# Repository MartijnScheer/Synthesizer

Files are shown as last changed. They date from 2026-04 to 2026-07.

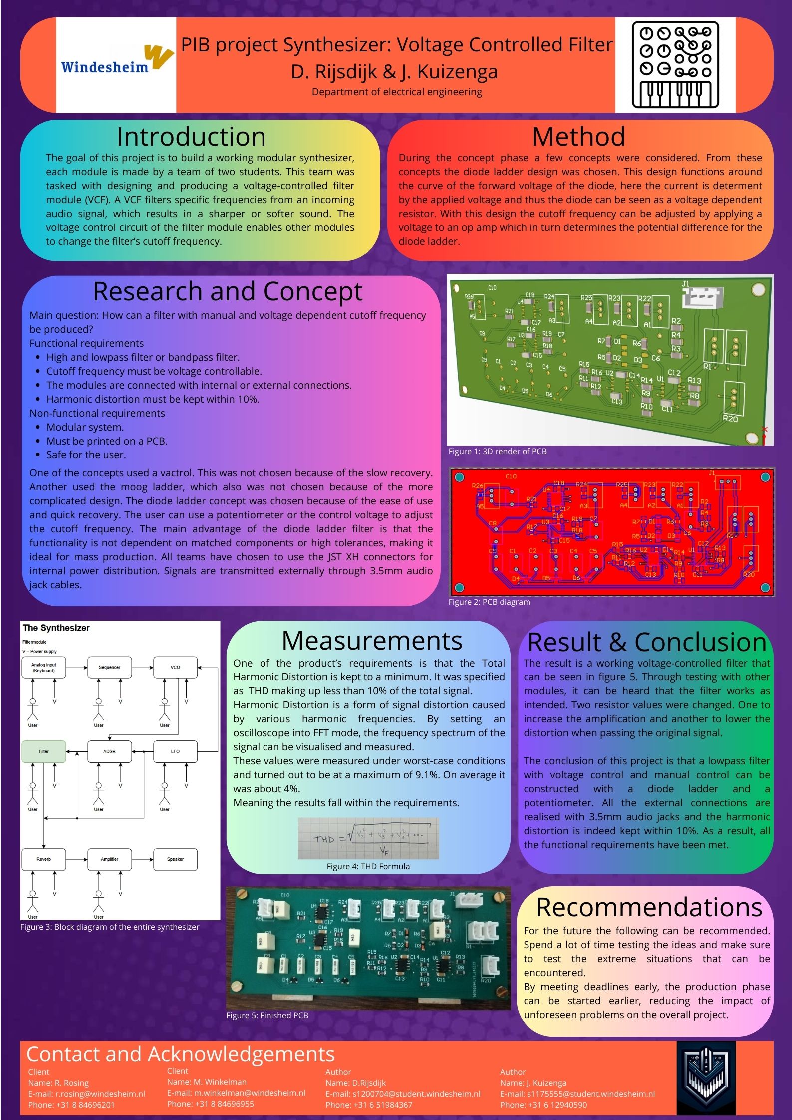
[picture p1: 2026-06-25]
Documentatie 2024-2025/Filter/Poster PIB project.jpg

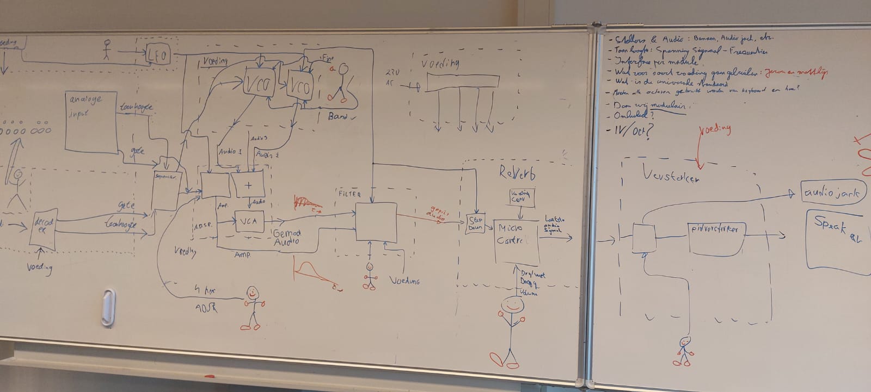
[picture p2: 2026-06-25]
Documentatie 2024-2025/Filter/Blokdiagram.jpeg

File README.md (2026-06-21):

# Synthesizer
Welkom bij de GitHub voor de Synthesizer op Windesheim. 
Hier kun je de relevante bestanden vinden en plaatsen voor de projecten die zijn uitgevoerd met de synthesizer!

Onder issues kun je de actuele problemen/vragen vinden.

Onder wiki kun je de meest actuele documentatie vinden.

Onder code kun je de bestanden vinden per projectjaar.

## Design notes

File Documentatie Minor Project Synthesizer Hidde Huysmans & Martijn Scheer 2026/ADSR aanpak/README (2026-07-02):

In de gesprekken met Bart en tijdens het project is er onderzoek gedaan naar mogelijke oplossingen om de ADSR opbouw met het NE555p timer IC nog te laten werken.

Een van de redenen waarom de triggering van het timer IC mogeglijk niet werkt is dat de eerst transistor in de schakeling gigantisch in de verzadiging wordt geduwd. 
Het toevoegen van een kleine weerstand in serie met de ingang van de eerste transistor kan dit al verhelpen, deze weerstand zorgt er namelijk voor dat de bjt sneller kan ontladen.

gebruikte literatuur:
  Nexpedia BJT handbook V2
  Chapman - Transistor circuit techniques

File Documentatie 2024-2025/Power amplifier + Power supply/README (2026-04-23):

bestanden voor de Power amplifier + Power supply module gemaakt door Jeroen Middel en Matthijs Vos

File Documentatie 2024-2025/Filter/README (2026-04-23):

Bestanden voor de filter module gemaakt door Jens Kuizenga en Diémo Rijsdijk

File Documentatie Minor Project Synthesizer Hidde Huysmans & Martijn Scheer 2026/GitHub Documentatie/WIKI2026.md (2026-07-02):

# PROJECT SYNTHESIZER


# Gemaakt door:
**PIB 2024/2025:**
* Patrick van Ommen & Rick Smelt (INPUT)
* Roelof Zijda & Relnout strating (SEQUENCER)
* Thijn Berkhoff & Ralph Hänninger (VCO)
* Ruben Boeve (LFO)
* Ingmar Kosmeijer & Hidde Huysman (ADSR + MIXER + VCA)
* Jens Kuizenga & Diémo Rijsdijk (FILTER)
* Jeroen Middel & Matthijs vos (POWER AMPLIFIER + POWER SUPPLY)
* Roelof Zijda (BEHUIZING)

**Project elektronica 2026: **
* Martijn Scheer (REVAMP INPUT MODULE +  & DOCUMENTATIE) 
* Hidde Huysmans (REVAMP ADSR + MIXER + VCA & DOCUMENTATIE)

Welkom bij de wiki van de synthesizer! Het grote idee is om verouderde documentatie hier te vervangen met de actuele. Als stukjes niet meer van toepassing zijn, haal ze lekker weg! Dat houd het overzichtelijk voor de groepjes in de volgende projecten.  

# Introductie

Tijdens het PIB-project van 2024/2025 is er een synthesizer gemaakt. Aan het einde van het project werkten echter nog niet alle onderdelen zoals bedoeld en was de documentatie nogal een zooitje. De documentatie was verspreid opgeslagen en ontbrak er een centrale plek waar alle informatie terug te vinden was. Hierdoor stond de synthesizer uiteindelijk ongebruikt in het lab en werd er niet meer aan verder gewerkt.

In 2026 is daarom, onder begeleiding van Bart Snijder, tijdens de minor elektronica een vervolgproject gestart. Het doel van dit project is om de bestaande synthesizer te herstellen en te verbeteren. Daarbij wordt eerst alle beschikbare documentatie verzameld en geplaatst in deze openbare GitHub (mapje documentatie 2024/2025), en de belangrijkste / meest actuele informatie gefilterd in deze wiki zodat toekomstige groepen eenvoudig verder kunnen werken aan het project.

Daarnaast worden de onderdelen die nog niet werken onderzocht en gerepareerd, problemen waar wij niet aan toe gekomen zijn staat onder issues, en het lijkt ons handig als die traditie wordt doorgevoerd voor goed overzicht! Het uiteindelijke doel van het 2026 project is om de synthesizer weer werkend te krijgen en daadwerkelijk geluid te laten produceren. 



# Uitleg per module

# Module 1: ADSR Envelope generator


Een ADSR envelope generator bepaalt hoe een geluid zich in de tijd ontwikkelt. Je kunt het zien als de “vorm” van een toon vanaf het moment dat een toets wordt ingedrukt tot het moment dat het geluid helemaal wegsterft. Dit is een belangrijk onderdeel van geluidssynthese, omdat het sterk bepaalt hoe natuurlijk, strak of elektronisch een geluid klinkt.
De ADSR-module is een envelope generator die een variërende stuurspanning genereert op basis van een gate-signaal van het keyboard.

ADSR staat voor Attack, Decay, Sustain & Release.

## Werking

Gate-trigger: Het gate-signaal van +3.3V wordt met transistoren omgezet naar een negatieve puls voor de trigger-pin van de NE555 timer.
Hierdoor start de envelope.

Attack: Een condensator laadt op via de attack-potmeter.
Hoe kleiner de weerstand -> hoe sneller de condensator oplaadt -> hoe sneller de uitgangsspanning stijgt

De spanning stijgt richting 8V intern en 5V aan de uitgang

Decay: Wanneer de condensatorspanning de threshold van de 555 bereikt:
schakelt het IC over
begint de condensator gedeeltelijk te ontladen
De spanning daalt naar het sustain-niveau.

Sustain: Tijdens sustain blijft de spanning constant zolang de gate actief blijft.
Het sustain-niveau bepaalt hoe hoog het uitgangssignaal blijft tijdens het vasthouden van een toets.

Release: Wanneer het gate-signaal terug naar 0V gaat: reset de 555 timer en 
ontlaadt de condensator via de release-potmeter
Hierdoor daalt de uitgangsspanning langzaam terug naar 0V.

afzonderlijke regeling van Attack, Decay, Sustain en Release
correcte envelope-vorm
instelbare timing en sustain-niveaus

## In- en uitgangssignalen

### Ingangen
Gate input: 0V / +3.3V
Voeding: ±12V
Potmeters: variabele weerstand

### Uitgangen
Envelope output: 0V – 5V
Interne condensatorspanning: 0V – 8V



# Module 2: Mixer
Mengt verschillende audio signalen

## Werking
 De mixer is nodig om audiosignalen, afkomstig van andere modules (zoals een LFO) en optionele externe bronnen, samen te voegen en vervolgens door te sturen naar de VCA
De schakeling is opgebouwd als een inverterende sommator, waarbij drie ingangen via 100kΩ-weerstanden worden samengebracht op de inverterende ingang van de opamp. Samen met de terugkoppelweerstand ook 100kΩ zorgt dit voor een gelijke versterking van 1 per kanaal. De signalen worden lineair gecombineerd en aan de uitgang geïnverteerd, zonder versterking of verzwakking.

## In- en uitgangssignalen
### Ingangen
3X 0 - 5V
### Uitgangen (alleen via de VCA!)
1X gemengd 0 - 5V

# Module 3: VCA (Voltage controlled amplifier)
Een VCA(Voltage-Controlled Amplifier) is een module in een synthesizer die het geluidsniveau (amplitude) regelt op basis van een stuurspanning bijvoorbeeld de omhullende gegenereerd door de ADSR envelope generator. Een VCA wordt gebruikt om de intensiteit van een geluidssignaal te moduleren. De VCA versterkt de geluidssignalen die al gemengd zijn in de mixer. 

## Werking 

Dit design maakt gebruik van ‘Long tailed pair’  geschakelede NPN transistoren, toegepast in deze vorm wordt een verschilversterker gecreëerd. (zie foto schema hieronder)
Een LTP verschilversterker bestaat uit twee NPN transistoren welke via hun emitters verbonden worden met een stroombron, in ons geval dient een stuurspanning met een serieweerstand als stroombron(zie R1 in het LTP schema). De collectors van de transistoren worden gezamenlijk gevoed via belastingsweerstanden naar de voedingsspanning(zie R2 en R3 in het LTP schema). De totale stroom blijft constant, de stroom per transistor is afhankelijk van het spanningsverschil tussen de basissen, dit is ook de input. Op de ene base zit V_(in-) en op de andere V_(in+ ).	 De output zit op de collectors, hoe groter het stroomverschil, hoe groter de spanning op de uitgang.


### Ingangen
Output van ADSR  0 - 8V

### Uitgangen

Envelope output: 0V – 5V (20 - 20kHz)



#Module 3: VCO (Voltage Controlled Oscillator)

De VCO module is ontwikkeld door Thijn Berkhoff en Ralph Hänninger tijdens het PIB project van 2024/2025. De VCO zet de inkomende stuurspanning (CV) om in een signaal met een bijbehorende frequentie. De frequentie reageert volgens de 1V/octaaf standaard, waardoor de module direct aangestuurd kan worden door het keyboard van de synthesizer, kijk bijvoorbeeld ook naar de afbeelding van de input module, tussen elk octaaf zit een volt verschil!

## Werking



Het ontwerp is opgebouwd uit drie hoofdonderdelen: de oscillator, de inputschakeling en het modulatiegebied. De kern van de module bestaat uit een zaagtandoscillator op basis van een comparator en integrator door middel van opamps. Door gebruik te maken van een converter met transistoren reageert de frequentie exponentieel op de ingangsspanning, waardoor de gewenste 1V/octaaf wordt bereikt.

Vanuit de zaagtand worden vervolgens meerdere golfvormen gegenereerd. Door middel van een inverter en comparator kunnen naast de zaagtand ook een geïnverteerde zaagtand en een blokgolf worden geselecteerd. Daarnaast beschikt de module over schakelaars voor verschillende octaafbereiken en een "finetune" regeling waarmee de frequentie nauwkeurig kan worden afgesteld.

Het oorspronkelijke ontwerp was bedoeld als een dual VCO, waarbij twee oscillatoren op één module aanwezig zijn. Beide kanalen beschikken over een eigen ingang, uitgang, octaafschakelaar en finetune regeling. Hierdoor kunnen twee verschillende signalen tegelijkertijd worden gegenereerd en gebruikt binnen de synthesizer. Dit werkt momenteel helaas nog niet, maar is wel essentieel voor het maken van een polyfoon systeem.

De module is momenteel opgebouwd op breadboard, alleen de output 2 is aangesloten omdat er geen ruimte was voor een extra output op de module, het maken van de module op een PCB is dus erg aangeraden!

## In- en uitgangssignalen
### Ingangen
CV Spanning: 0 tot 3.3V (zie input module)
Voeding: ±12V

### Uitgangen
VCO output: tussen -2.2v en 2.2v

Output frequentie: ligt aan de finetune en octaaf offset instellingen. Meestal rond de 50hz (nog even nameten!)



# Module 4: Input Module

De input module is oorspronkelijk ontwikkeld door Patrick van Ommen en Rick Smelt tijdens het PIB project van 2024/2025 waarin de hoofdwerking gerealiseerd is en verbeterd door Martijn Scheer tijdens het 2026 Elektronica project waarin de software verbeterd is en stappen voor het uitbreiding naar polyfoon zijn uitgewerkt.

## Werking

De module bestaat uit twee hoofdonderdelen: het ingebouwde keyboard en een schakelaar waarmee gekozen kan worden tussen de keyboard en een MIDI. Hierdoor kan de synthesizer zowel zelfstandig gebruikt worden als aangestuurd worden via MIDI. Op het moment van schrijven is deze werking helaas niet aanwezig. 
Hoewel de hardware voor de MIDI aanwezig is, was de softwarematige verwerking van MIDI signalen aan het einde van de projecten van 2024/2025/2026 nog werkend.
**Momenteel staat in de software de output vastgesteld op keyboard modus, ongeacht de stand van de schakelaar! Dit omdat de schakelaar niet goed bleek te werken, zie het tabje issues voor meer uitleg**

Het keyboard bestaat uit 25 toetsen die door een AVR128DB48-microcontroller worden uitgelezen. Wanneer een toets wordt ingedrukt, wordt de bijbehorende toonhoogte omgerekend naar een analoge spanning via de ingebouwde DAC van de microcontroller, zie de afbeelding hieronder. Daarnaast wordt een gate-signaal gegenereerd om aan te geven dat een toets actief is, de gate is een puls van 5v (op het moment van schrijven is er een bug? de gate lijkt nu 3.3v te zijn) en 10ms lang.



## In- en uitgangssignalen

De output van de input module bestaat uit een toonhoogtesignaal (CV) en een gate-signaal. Deze signalen worden doorgestuurd naar de andere modules van de synthesizer, zoals de VCO en ADSR, en vormen daarmee de basis voor het genereren van geluid.

# Module 5: Sequencer

De sequencer is een onderdeel van een modulaire synthesizer. Het systeem leest analoge toonhoogte-signalen van een keyboard in, slaat deze digitaal op en speelt ze later herhalend af als een sequence.

De sequencer ondersteunt meerdere modi:Recording, Play & Replace

Daarnaast kan de afspeelsnelheid (BPM) aangepast worden met een potentiometer en geven LED’s visuele feedback over de huidige positie of status.

### Werking
Input
De sequencer ontvangt twee signalen: Toonhoogte-signaal en Gate-signaal

Het toonhoogte-signaal bepaalt welke noot gespeeld wordt.
Het gate-signaal geeft aan wanneer een toets wordt ingedrukt.

#### ADC

Het inkomende analoge toon-signaal wordt ingelezen via de ADC van de microcontroller.
Omdat de ingangsspanning hoger kan zijn dan de maximale ADC-spanning, wordt eerst een spanningsdeler toegepast.

##### Opslag

De gemeten toonwaardes worden opgeslagen in een array in het geheugen van de microcontroller.

Elke stap in de sequence bevat een 10-bit waarde.

####DAC

Tijdens het afspelen worden de opgeslagen waardes via de DAC terug omgezet naar een analoog spanningssignaal.

Dit signaal wordt gebruikt om een VCO (Voltage Controlled Oscillator) aan te sturen.

#### Gate generatie

Tijdens playback genereert de sequencer zelf een nieuw gate-signaal.

Bij iedere nieuwe noot wordt de gate kort laag gemaakt en daarna weer hoog gezet, zodat externe modules weten dat een nieuwe toon gestart is.

### States
Recording: Leest ADC-waardes in en slaat deze op.
Play: Speelt opgeslagen waardes af via de DAC.
Replace: Speelt de huidige sequence af en overschrijft tegelijk bestaande noten.

Tijdens testen bleek dat de uitgangsspanning een afwijking had van ongeveer 21–30% ten opzichte van de ideale toonstappen.

Mogelijke oorzaken:

ADC/DAC onnauwkeurigheid
toleranties van weerstanden
offset in de analoge versterking
Mogelijke verbeteringen
Microcontroller met nauwkeurigere ADC/DAC
Weerstanden met lagere toleranties
Softwarematige offset-correctie
Hogere resolutie voor toonopslag

(!) Sequencer leek te werken, maar we weten niet hoe we hem instellen.

# Module 6: Power amplifier + Power supply

De "Pulse Soundworks" Power Amplifier is een klasse-AB eindversterker, door te kiezen voor een klasse-AB ontwerp wordt een goede balans bereikt tussen geluidskwaliteit, efficiëntie en warmteontwikkeling.

Naast de eindversterker is ook een voedingsmodule ontworpen. Deze zet de spanning van de trafo om naar meerdere stabiele voedingsspanningen die gebruikt worden door zowel de versterker als andere onderdelen van de synthesizer.

## Werking



Het audiosignaal komt eerst binnen via een hoogdoorlaatfilter dat DC ruis verwijdert. Daarna gaat het signaal door een buffer zodat de bron niet belast wordt. Met de volumepotmeter kan vervolgens het gewenste geluidsniveau worden ingesteld.

Na deze voorbewerking wordt het signaal versterkt door een opamp die als spanningsversterker werkt. Vervolgens sturen de drivertransistoren de MOSFET eindtrap aan. Deze eindtrap bestaat uit een IRF540N en een IRF9540N die samen het benodigde uitgangsvermogen leveren aan de luidspreker of hoofdtelefoon.

De voeding maakt gebruik van een transformator die 230 V AC omzet naar 12 VDC. Met behulp van gelijkrichters, afvlakcondensatoren en spanningsregelaars worden hieruit stabiele positieve en negatieve voedingsspanningen gemaakt. Deze spanningen worden gebruikt door de eindversterker en de overige elektronica van de synthesizer.

## In- en uitgangssignalen

### Ingangen

Audio input: 5 Vpp
Voeding: 18VAC vanuit trafo wordt gelijkgericht naar 12VDC
Volume regeling: 10 kΩ logaritmische potmeter

### Uitgangen

Speaker output: > 1 W aan 8 Ω
Headphone output: verzwakt audiosignaal voor oordopjes of hoofdtelefoon
Voedingsuitgangen: +12 V, -12 V, +5 V en +3,3 V

# Module 7: LFO (Low Frequency Oscillator)
De LFO is een laagfrequente oscillator voor een modulaire synthesizer. De module genereert variërende spanningen waarmee andere modules gemoduleerd kunnen worden. Hiermee kunnen verschillende effecten, zoals bijvoorbeeld vibrato, gemaakt worden.
## Werking
De LFO is volledig analoog opgebouwd met opamps. Met als basis een simpele oscillator. Hierin laadt en ontlaadt een condensator zichzelf steeds via een weerstand. De opamp schakelt daarbij steeds tussen de positieve en negatieve voedingsspanning, waardoor een oscillerend signaal ontstaat.

Met een potmeter wordt op- en aflaad de weerstand aangepast. Hierdoor verandert de snelheid waarmee de condensator oplaadt en ontlaadt. Daarmee wordt dus ook de frequentie van de LFO geregeld.

De schakeling genereert eerst een blokgolf en een driehoek.
De driehoekgolf wordt daarna via diodes afgerond zodat een sinusachtige golf ontstaat. Door de verschillende paden te kiezen kan je dan dus kiezen tussen een driehoek, blokgolf of sinus- vormig signaal

Na de golfselectie wordt het signaal verder aangepast met amplituderegeling (hoe sterk het signaal is) en offset (het signaal omhoog verschuiven)
De module heeft uiteindelijk drie gebufferde outputs zodat meerdere modules tegelijk aangesloten kunnen worden.
## In- en uitgangssignalen

### Ingangen
Voeding: ±12V
### Uitgangen
Signaal met driehoek, blokgolf of sinus- vorm
Regelbare amplitude: ongeveer 0V tot 2.2V
Offset: 0V tot +1.5V
Maximale uitgangsspanning: ongeveer 5.5V
Drie identieke gebufferde outputs


	
# Module 8: VCF(Voltage Controlled Filter)
De VCF (Voltage Controlled Filter) is een spanningsgestuurde filtermodule voor een modulaire synthesizer. De module filtert bepaalde frequenties uit een audiosignaal en kan de kantelfrequentie aanpassen met een potmeter een externe control spanning. De module kan zowel als LPF als HDF worden ingesteld.
## Werking
De VCF werkt door bepaalde frequenties uit een audiosignaal weg te filteren. Het ingangssignaal gaat eerst door een diode ladder.(Het ingangssignaal wordt eerst verzwakt en voorzien van een offset zodat de diodeladder correct werkt binnen het juiste spanningsgebied.) In deze schakeling gedragen diodes zich als spanningsafhankelijke weerstanden. Door de spanning over de diodes te veranderen verandert ook de weerstand van het filter.

Hierdoor verschuift de kantelfrequentie van het filter. Bij een low-pass filter worden hoge frequenties verzwakt en blijven lage frequenties over. Bij een high-pass filter gebeurt juist het tegenovergestelde. Dit veranderd de klank heel erg uiteraard.

De kantelfrequentie kan aangepast worden met een potmeter of met een externe control spanning. Daardoor kan het filter automatisch bewegen tijdens het spelen, wat typische synthesizer-effecten zoals sweeps oplevert.

## **Notities Sequencer:** 
De Sequencer werkt niet, dit is nagevraagd aan de originele groep, die heeft vermeld dat deze het wel heeft gedaan maar met een afwijking van 20-30%.
Dit is echter niet wat we hebben kunnen meten. Door te meten op de Gate van de uitgang meet je tijdens het recorden en replacen wel direct de gate. maar niet het signaal (gewoon 0). Tijdens het signaal opslaan lukt het niet om het patroon terug te zien. Dus het lijkt ook niet alsof recorden werkt.

De lampjes werken wel en reageren wel op de bpm die je instelt. Dit is een interresante module om een project over te kunnen doen. Aangezien het nog een mysterie is waarom deze module het niet doet.

### **Algemene notities:**
Wanneer er geen toets wordt gespeeld is er ruis op de ingang van de VCO. Deze ruis lijkt ook al te worden geoscilleerd waardoor je de brom hoort.
Voor de VCO is het misschien een idee om een hoogdoorlaat filter van bijvoorbeeld >5hz te doen om de ruis eruit te filteren / al flink indammen.

### **Notities Filter** 
Het filter werkt exponentieel, echter werken de frequenties die uit de modules komen lineair. Hierdoor is het vrijwel onmogelijk om het filter af te stemmen om ruis of een mooi signaal te maken. Zo is bijvoorbeeld het uitfilteren van de ruis met een hoogdoorlaatfilter erg moeilijk omdat op het moment dat deze afgestemd is om de ruis te filteren, het toetsenbord ook al flink gedempt is. 

### **Notities Eindversterker:**
Eindversterker module lijkt alles aan te kloppen na testen. Kleine demping voor koptelefoon (dat hoort). 

### **Notities Input:**
De input module werkt per 2026 de software door gebruik van Arrays die de ingedrukte toetsen in volgorde bijhoud. Het programmeren van de PCB
die zich rechtsonder (onder de basisplaat) bevind is getest en werkt nog. Hiervoor kun je bij het Lab een UPDI programmeren vragen om de pins te programmeren. 
De gebruikte software is MPlab, voor de meest actuele softwarefiles kijk in het mapje "Software" in het mapje "Documentatie 2026", MAAR! let hier op dat deze software de meest actuele software is die op de PCB staat. Hiervoor is de MIDI functie compleet geschrapt.
Als de Midi dus werkende gemaakt moet worden, zit er in deze software helemaal gedachte daarin gestopt! De switch knop is ook in beide gevallen geprogrammeerd op keyboard modus (er is een fout in of hardwarematig of softwarematig de knop!)

Verder is er een onderzoek gedaan naar parafonie. Dit houd in dat er meerdere CV spanningen uit de input module komen, waardoor je bijvoorbeeld akkoorden kunt spelen. In het kort moet het volgende hiervoor nog gebeuren: 
1. Input module software moet worden aangepast om plekken in de array een aparte CV spanning en Output geven. 
1B: Er is maar 1 DAC 10 bit aanwezig op de AVR128db48. Voor Parafonie heb je meer uitgangen nodig. Dit kan met een PWM met een filter of een extern bordje die je bijvoorbeeld met I2C kan aansturen.
2. PCB input module moet opnieuw gemaakt worden om meer CV outputs te ondersteunen. 
3. VCO module moet meer ingangen ondersteunen om elke CV spanning zijn eigen oscillatie te geven.
4. Deze moeten weer gecombineerd worden in de Mixer module. Deze werkt momenteel niet omdat deze niet gebufferd wordt. Ook is deze module afhankelijk
van de werking van de VCA en de ADSR module, deze werken momenteel ook nog niet. DUS! Het is belangrijk om een de ADSR + Mixer + VCA module werkende te krijgen, voordat er wordt gekeken naar parafonie. Nouja, niks hoeft, maar is wel aangeraden.

Kijk het mapje "Vooronderzoek poly/parafonie" in het mapje "Documentatie 2026" voor meer informatie hierover. 

### **Notities VCO**
**(7-5-2026)** De VCO werkt momenteel alleen via output 2. Output 1 zit aan de onderzijde en is niet aangesloten op het breadboard. Het lijkt erop dat de huidige module onder tijdsdruk is ontworpen, waarbij de focus lag op één werkend kanaal.

Om beide kanalen werkend te krijgen, zijn de meest voor de hand liggende opties:

1. Een tweede vergelijkbaar bordje maken.
2. Een nieuwe PCB ontwerpen met ondersteuning voor beide kanalen.

**Raadpleeg de documentatie van de VCO 2024/2025 om te bepalen welke optie het meest praktisch is.**

### **Notities ADSR:**
ADSR zijn nog onbekende fouten. Hiddeh ff iets bijtypen

### **Notities Mixer:**
Actieve mixer van maken. Hiddeh ff iets bijtypen

### **Notities VCA:**
VCA lijkt geen goeie input te krijgen doordat er niet gebufferd wordt.

### **Notities Power amp + power supply:**
De voeding die binnenkomt op de 18VAC 50Hz, voedingkabels lijken per module te verschillen, als de module niet meer werkt, zekering checken, deze brand snel door (uit ervaring). Mosfet wordt ook wel warm, hierom is het aangeraden om wellicht een extra koellichaampje op deze mosfet te monteren.

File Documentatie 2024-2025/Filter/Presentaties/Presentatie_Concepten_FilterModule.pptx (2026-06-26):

## Project Ingenieursbureau VCF Concepten

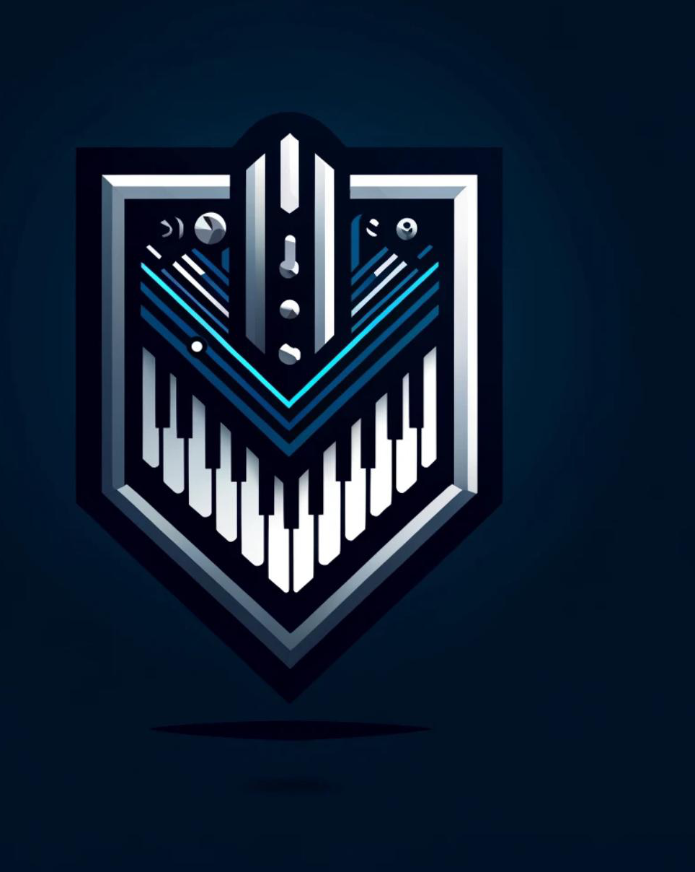
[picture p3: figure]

Opdrachtgever: Windesheim
Bedrijf: Pulse Soundworks
Datum: 25-09-’24
Diémo Rijsdijk: 1200704
Jens Kuizenga: 1175555

## Inhoud

- Inleiding
- Opdracht en doelstelling
- PvE
- Beperkingen
- Conceptoplossingen
- Voldoen aan eisen
- Afgevallen concepten
- Haalbaarheid

## Inleiding

- Voor het vak PIB gaan wij een synthesizer bouwen waarvan wij het filter gaan maken
- Het doel van het project is het produceren van een effectfilter module voor een modulaire synth die de kantelfrequentie kan regelen via een interface en via een input door middel van een spanning
- Aan het eind van het project wordt er een werkende synth opgeleverd.

## Opdracht en doelstelling

- High-pass en Low-pass
- Low-pass spanningsgestuurd
- 6-dB/oct demping
- Tevredenheid klant → werkend product
- Einddatum

## Programma van eisen

Functionele Eisen:
- Een laagdoorlaat- en hoogdoorlaatfilter of bandfilter in één module
- De kantelfrequentie van de low-pass is instelbaar met een extern stuursignaal
- Kantelfrequentie van beide filters is instelbaar met een potmeter
- Een bandbreedte van ten minste 4 octaven
- De kantelfrequentie is instelbaar van 100Hz-5kHz

## Programma van eisen

- Niet-functionele Eisen
- Veilige spanningen voor de gebruiker.
- De Maximale kosten bedragen 50€.
- De volledige constructie moet ten miste tilbaar zijn door één persoon.
- De pcb’s zijn zichtbaar te maken zonder demontage
- Modulair systeem.
- 3.5mm jack connectoren voor signalen.

## beperkingen

- Componenten die bij Windesheim op voorraad zijn
- PCB-ontwerp voldoet aan de door de fabrikant gestelde beperkingen
- Geen end-of-life componenten
- Max. afmetingen → behuizing

## LDR Filter (Vactrol)

- Eenvoudig filter, weerstand vervangen
- Exotische componenten / zelfbouw
- Spanningssturing niet-lineair → complexiteit
- Reactiesnelheid beperkt

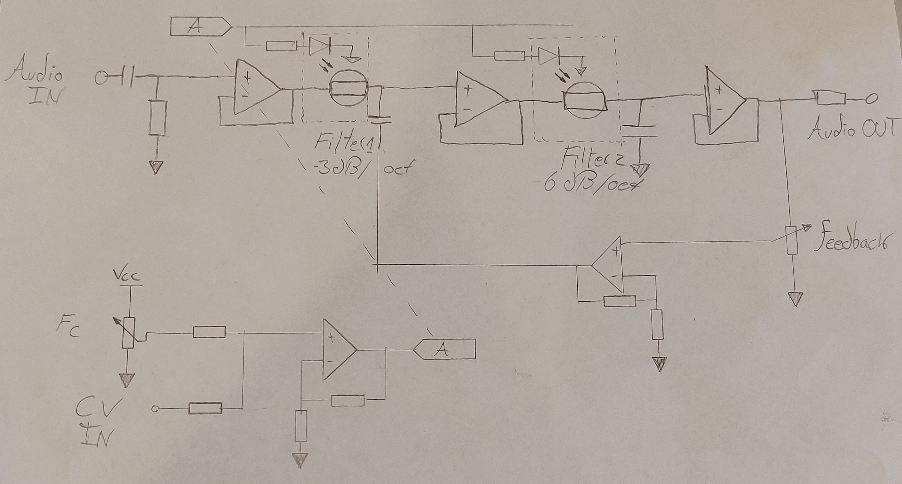
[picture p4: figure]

## OTA Filter

- Moeilijk lineair te maken
- “exotisch component”

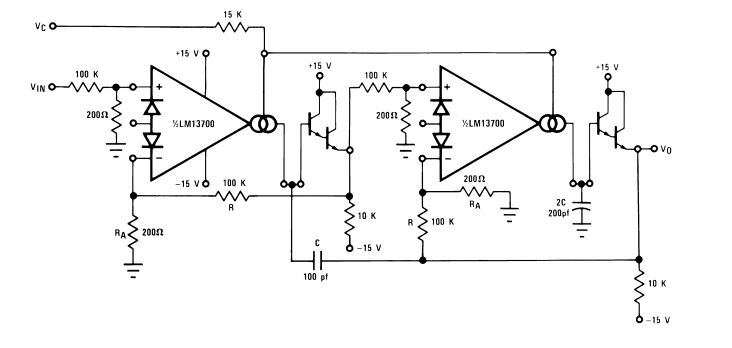
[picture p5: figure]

## Moog Ladder

- Machted pair transistor
- Ingewikkelder

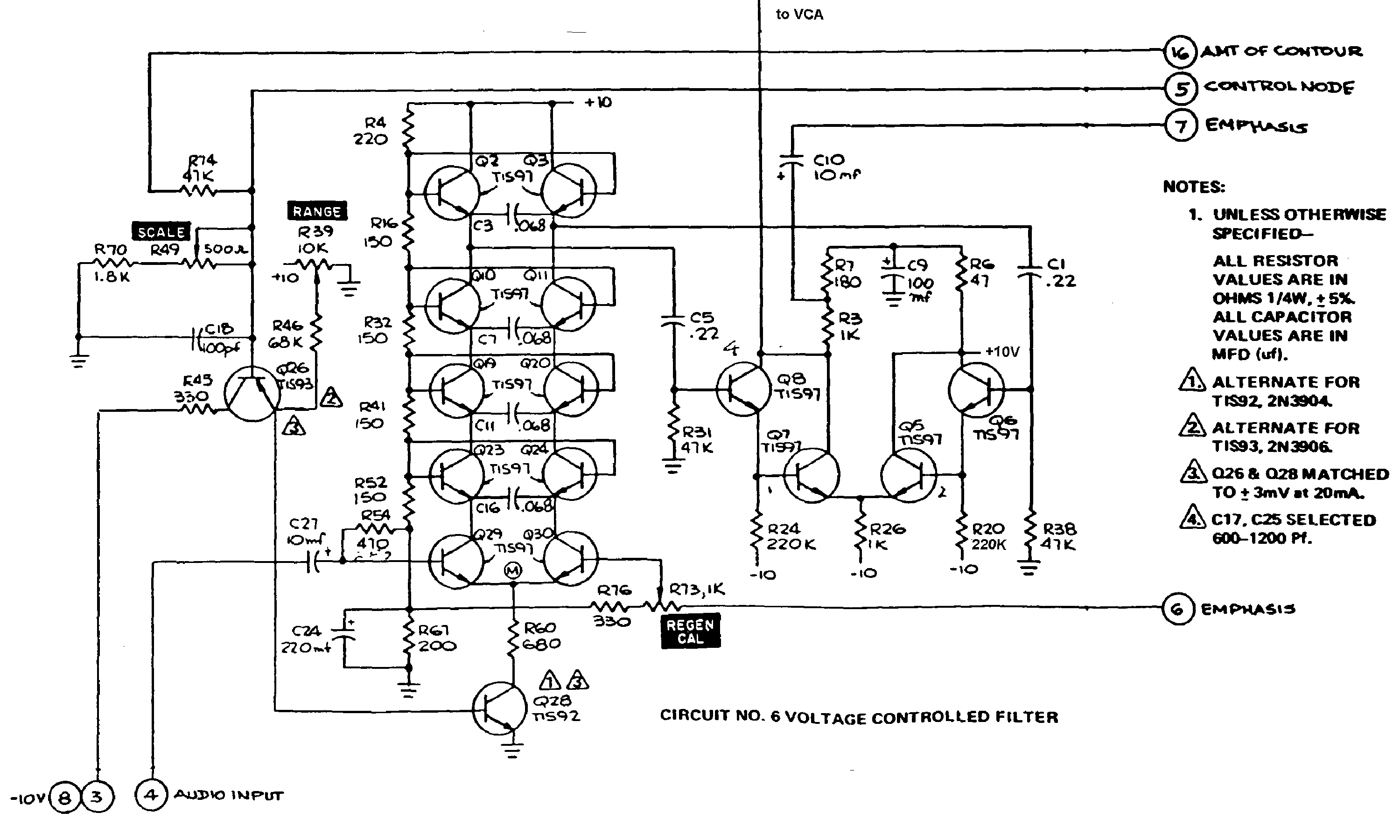
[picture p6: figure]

## Diode ladder

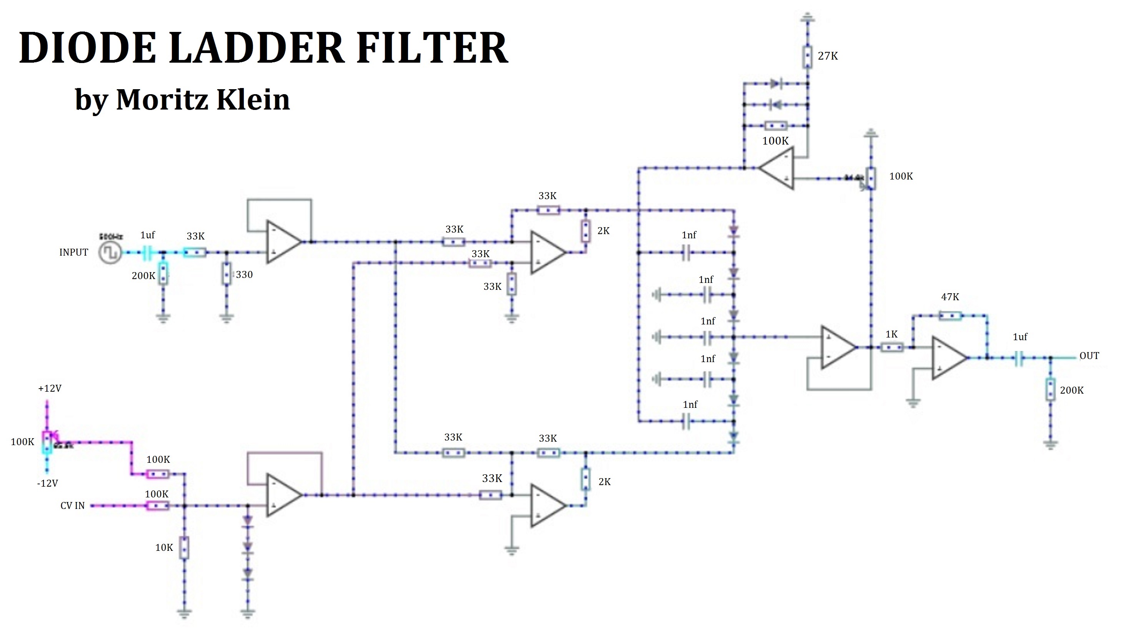
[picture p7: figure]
Designing a diode ladder filter from scratch - #17 by Dud - Videoos - Look Mum No Computer Thingies

- Eigenschappen
  - Diode als weerstand
  - Spanningsafhankelijk

## Diode ladder

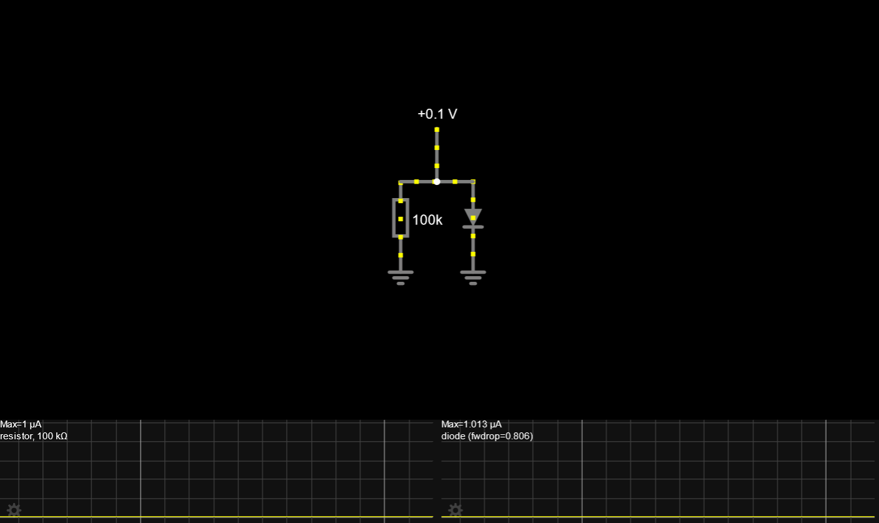
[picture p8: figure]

## Diode ladder

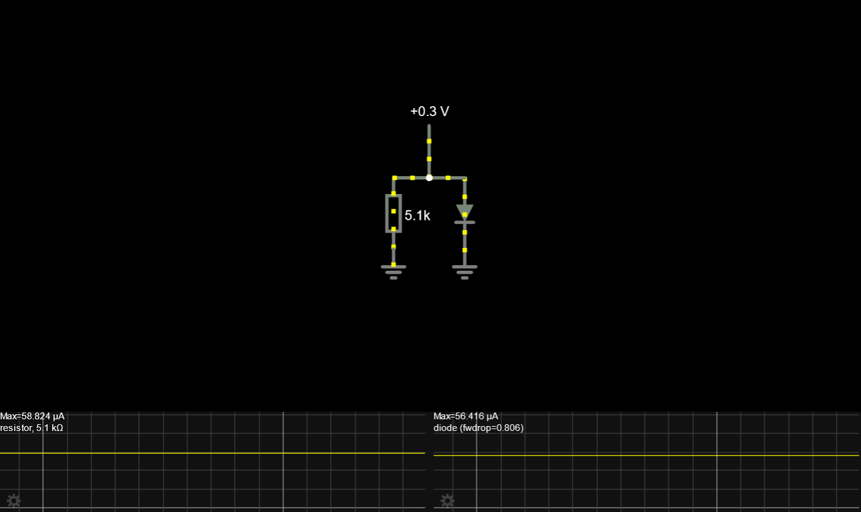
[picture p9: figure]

## Diode Ladder

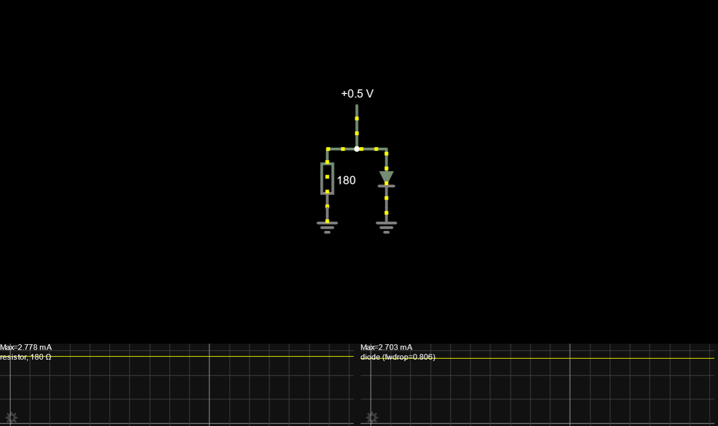
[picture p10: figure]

## Diode ladder

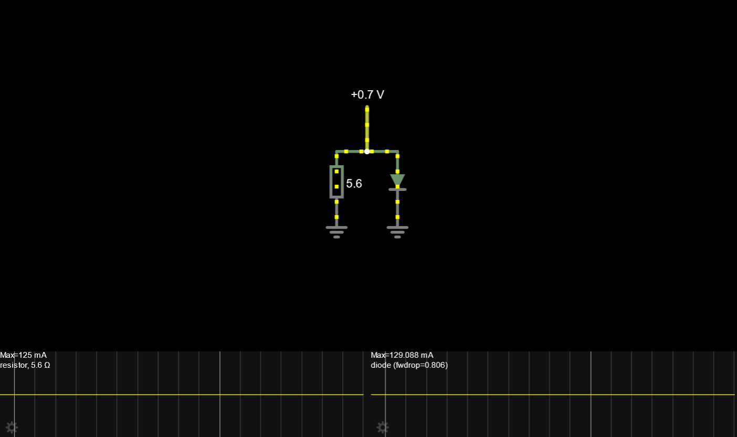
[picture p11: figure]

## Diode ladder

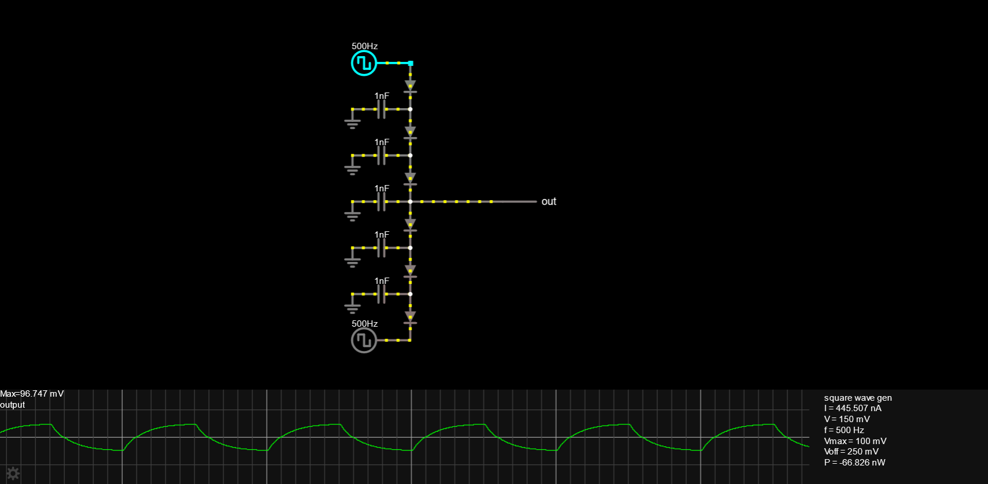
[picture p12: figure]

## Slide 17

Diode ladder

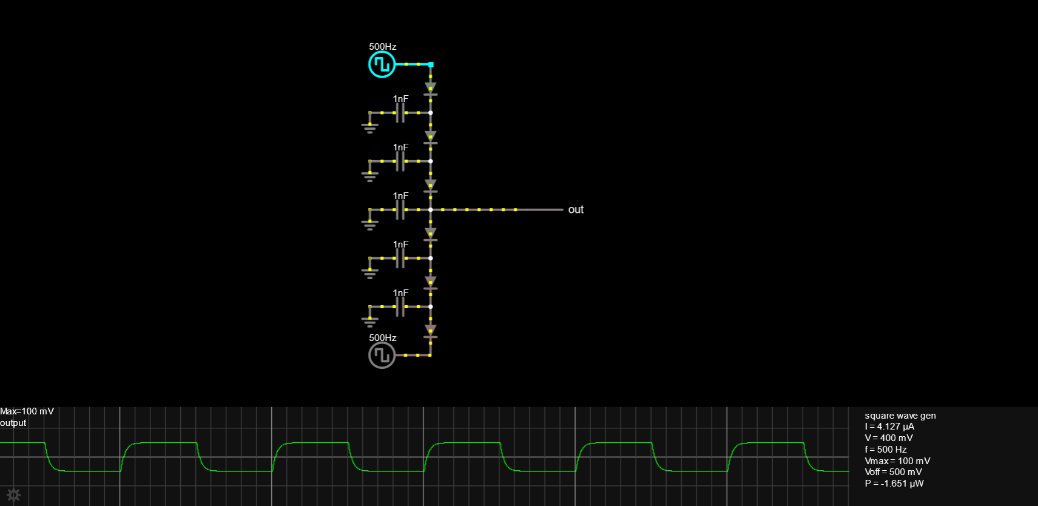
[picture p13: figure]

## Diode Ladder

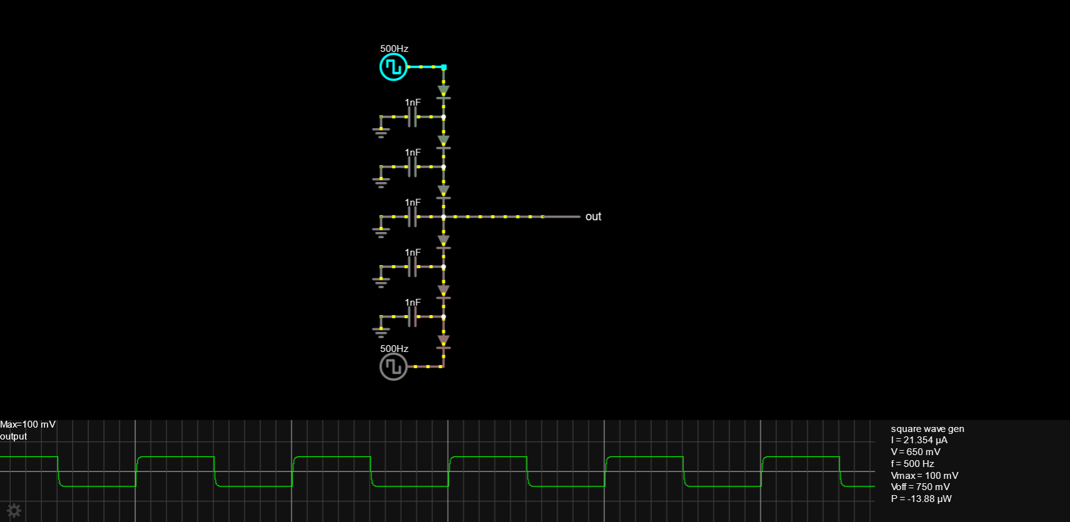
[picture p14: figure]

## Diode Ladder

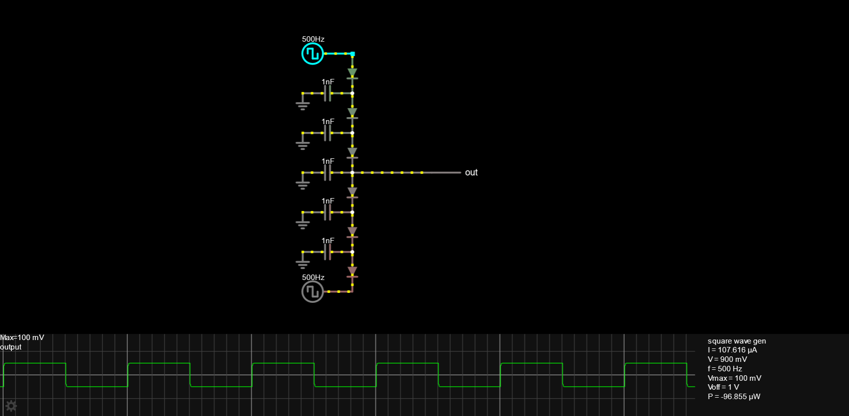
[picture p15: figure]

## Diode Ladder

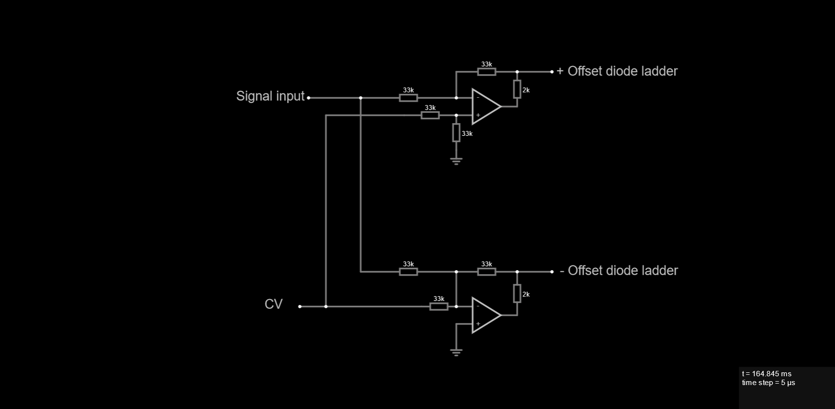
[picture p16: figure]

## Diode Ladder

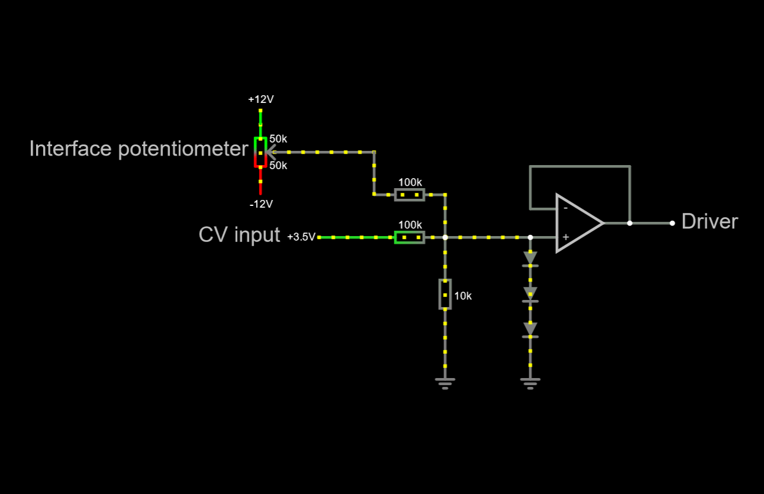
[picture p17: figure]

## Diode Ladder

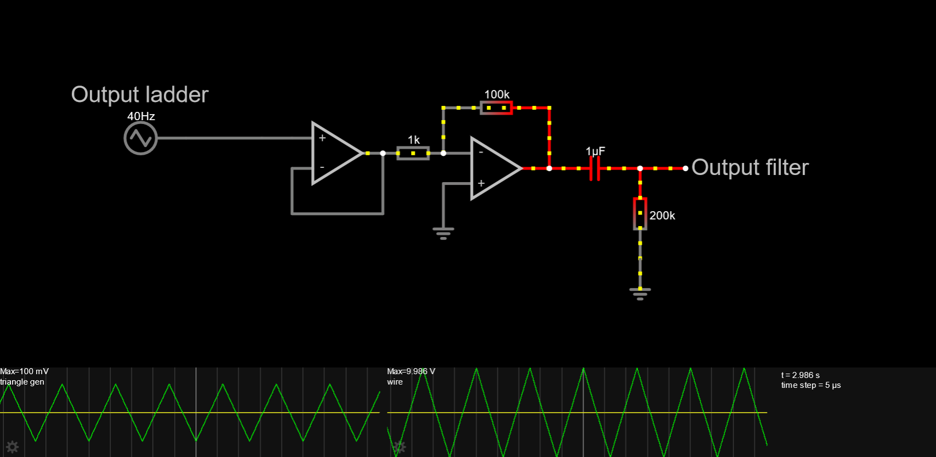
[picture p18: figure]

## Diode ladder

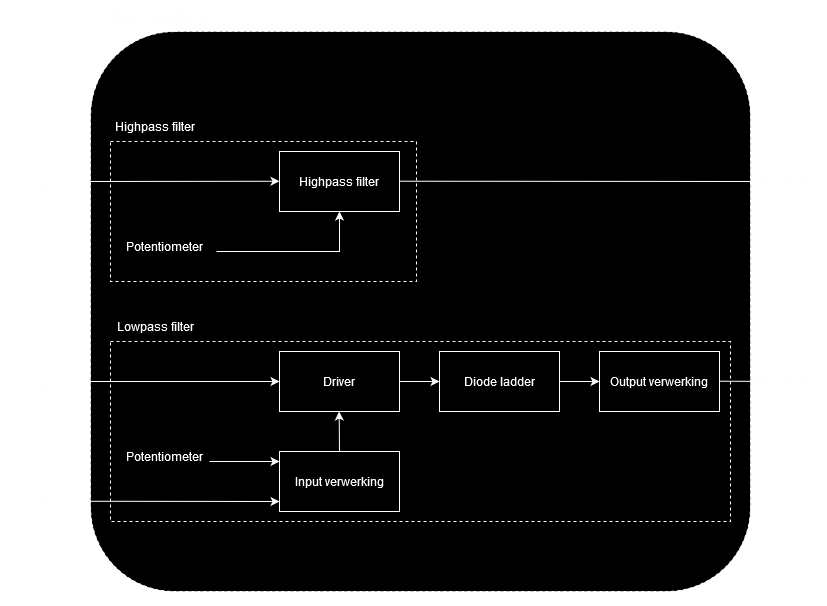
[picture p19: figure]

## Concepten vergelijken

LDR

Diode ladder

- Signaal sterk verlagen
- Offset kan niet te groot anders kortsluiting

Moog ladder

- Transistoren i.p.v. diodes

OTA-Filter

- Niet-standaard componenten
- Lineariteit → complexiteit
- Reactiesnelheid
- Matched pair
- Intuïtiever

- Exotische op amp

## Voldoen aan eisen

- Laag en hoogdoorlaat
- Kantel frequentie via potmeter
- Kantel frequentie via control voltage
- Bandbreedte wordt door de componenten bepaald.
- Evenals de kantelfrequentie

## Haalbaarheid

- Goed haalbaar, vanwege gebruikelijke componenten
- Afzonderlijk testbaar

## Einde

- Zijn er nog vragen?

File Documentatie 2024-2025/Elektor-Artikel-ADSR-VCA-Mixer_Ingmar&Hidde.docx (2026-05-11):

# Inleiding

In de muziekwereld speelt elektronica tegenwoordig een steeds grotere rol. Waar vroeger gitaren, piano’s, drums en andere instrumenten het geluid bepaalden, wordt muziek steeds vaker elektronisch gegenereerd. Vaak zelfs volledig in een digitale audio-omgeving op een computer. Het wordt voor muzikanten steeds makkelijker, er hoeft geen band met al haar instrumenten naar een studio te komen om de muziek op te nemen. Daarnaast biedt elektronisch gegenereerde muziek veel mogelijkheden; er zijn oneindige mogelijkheden voor tonen. Toonhoogtes, volumes en filterfrequenties zijn simpel aan te passen, de geluidskwaliteit is hoger en alles kan gemaakt worden door één persoon op een computer; kortom, ontzettend veel voordelen!

## Klankgeneratie

In deze hedendaagse digitale audio omgevingen worden veel functies welke ook te vinden waren op een analoge synthesizer gebruikt. De fundamenten deze functies werden in jaren ’20, toen werd de ondes-Martenot op de markt gebracht. Dit is een elektronisch muziekinstriment die geluidsgolven creerde met een elektronenbuis. Maar elektronische klankgeneratie ontwikkelde verder, in de jaren ’60 kwamen de eerste analoge synthesizers als de Minimoog op de markt.

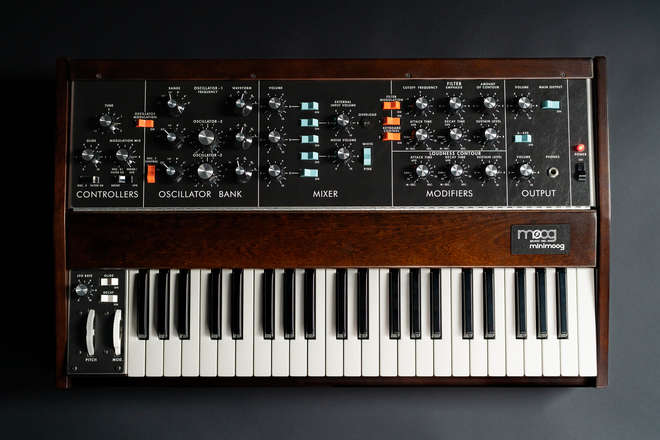
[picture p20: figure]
Moog Synthesizers | Moog Music

Synthesizers zijn apparaten die elektronisch geluiden kunnen genereren en manipuleren. De old-school synthesizers uit de jaren 70 waren volledig analoog en modulair opgebouwd. Dit betekende dat elk effect of geluidsbewerking een aparte module had, waardoor gebruikers zelf de volgorde en combinaties van de modules konden bepalen. Dit gaf muzikanten en geluidstechnici bijna oneindige mogelijkheden om unieke geluiden te creëren.

Minimoog Model D

## Opdracht

In dit project, aangeboden door Windesheim College, bouwen we in sub-teams een modulaire, analoge synthesizer die werkt en klinkt zoals de klassieke apparaten uit de jaren 70. Net als de oude synthesizers wordt ons ontwerp modulair opgebouwd. Deze synthesizers hadden verschillende maten, van klein topt hele wanden gevuld Elk effect of bewerkingsmodule staat op zichzelf, zodat de gebruiker de synthesizer flexibel kan samenstellen. Dit biedt de vrijheid om de effecten in elke gewenste volgorde te schakelen en de synthesizer volledig naar eigen smaak te configureren.

De modules die wij realiseren begaan de ADSR, mixer en VCA module. Hier hebben wij schema tot PCB ontwikkeld.

# ADSR

Wat doet een ADSR?

Een ADSR is een ‘Envelope generator’, een envelope of “omhullende” is de vorm van geluid door de tijd heen wanneer er een toets word ingedrukt. Een envelope generator stelt een geluidstechnicus of muzikant in staat om een breed scala aan verschillende tonen te creëren, waardoor het een fundamenteel onderdeel is van geluidsynthese. Een ADSR envelope generator is een van de meest voorkomende typen vanwege haar veelzijdigheid en eenvoudige toepassing. Het gebruikt vier fasen voor de evolutie van geluid: de attack-, decay-, sustain- en release-fase. Door de tijd te variëren die nodig is om de ingestelde niveaus te bereiken, kan de toon op verschillende manieren gemoduleerd worden.

## Eisen

- ADSR-parameters moeten afzonderlijk worden ingesteld.
- ADSR-Envelope wordt gestart door een gate signaal van +3.3V
- Modules moeten semi-modulair kunnen worden aangesloten.
- De bedieningselementen van de modules moeten volledig functioneel zijn over hun gehele bereik.

## Functies

Voor een goed functionerende ADSR moeten de volgende functionaliteiten in het ontwerp worden verwerkt: De envelope begint wanneer er een gate-signaal wordt ontvangen van het toetsenbord. Dit triggert de start van de attack-fase, waarin het signaal snel toeneemt tot de maximale piek. Na deze piek gaat het signaal over in de decay-fase, waarin het geleidelijk afneemt tot het sustain-niveau. Zolang de toets ingedrukt blijft en het gate-signaal actief is, blijft het signaal op dit sustain-niveau. Wanneer de toets wordt losgelaten en het gate-signaal wegvalt, gaat het signaal via de release-fase langzaam terug naar nul.

Wij hebben ons ADSR ontwerp gebaseerd op René Schmitz' Fastest Envelope in the West (https://www.schmitzbits.de/adsr.html). Dit circuit werkt met het 555 (https://nl.wikipedia.org/wiki/NE555) timer ic, om de vier parameters van de ADSR te moduleren.

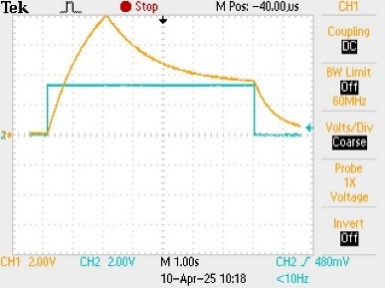
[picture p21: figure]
Afbeelding met tekst, schermopname, Perceel, lijn Door AI gegenereerde inhoud is mogelijk onjuist.
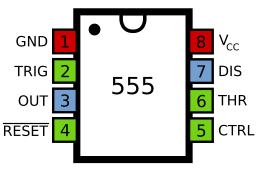
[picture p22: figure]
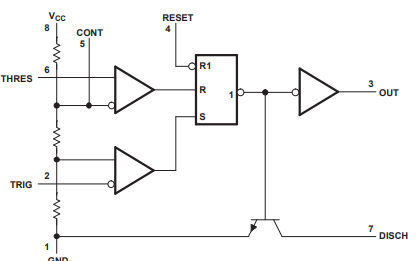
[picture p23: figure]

ADSR parameters(geel), Gate(blauw)

Starten van het IC:

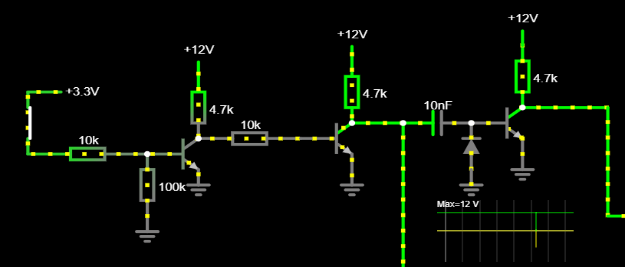
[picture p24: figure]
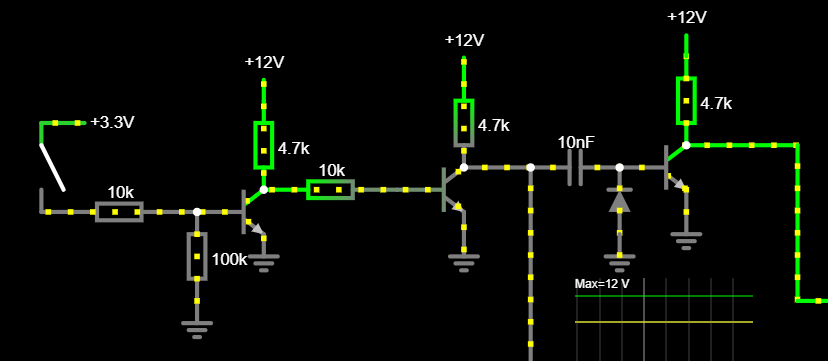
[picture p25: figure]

Om de envelope te starten moet het IC getriggerd worden op pin 2 met een negatieve puls. Om het Gate signaal om te zetten tot een negatieve puls gebruiken we drie NPN transistoren. Dit is hoe het werkt:

Wanneer de Gate hoog is aan de base van de eerste transistor gaat deze geleiden wat ervoor zorgt dat dat het voltage aan de base van de tweede transistor word verlaagd. Nu stopt de tweede transistor met geleiden wat voor een hoog voltage zorgt op de source pin. De condensator die daarop aangesloten is zal nu snel opladen waarna hij zijn stroom kort ontlaad op de base van de derde transistor die daarop ook kort gaat geleiden wat voor een negatieve puls zorgt op pin twee van het IC.

Attack fase:

Deze puls op pin 2 verandert de toestand van de interne flipflop van de 555, waardoor de uitgang op pin 3 hoog wordt. Hierdoor wordt stroom naar buiten geduwd via de attack potmeter. Afhankelijk van de hoeveelheid weerstand van de potmeter, laat deze stroom nu de condensator op wat de attack fase van de envelope voorstelt.

Decay fase:

Wanneer de spanning op de condensator hoog genoeg is en de drempel van het IC overschrijdt (op pin 6), schakelt de timer over naar de ontlaadmodus. Een interne transistor begint te geleiden, waardoor de spanning op pin 7 lager wordt. Nu zal stroom gaan vloeien van de positieve voedingsspanning, via de 4,7k-weerstand en de sustain-potmeter, wat de spanning aan de linkerkant van de diode verlaagt. Omdat het spanningsniveau op de condensator hoger is dan dat op de sustain-potmeter, zal er ook stroom uit de condensator vloeien, via de decay-potmeter, door de sustain-potmeter naar pin 7. Wanneer de spanning op de condensator gelijk is aan de instelling van de sustain-potmeter, stopt het ontladen en wordt een stabiele toestand bereikt. Er kan geen stroom meer op de condensator worden opgebouwd, omdat deze wegvloeit via de ontlaadpin van de timer.

Release fase:

Zodra het gate-signaal laag wordt, stopt de eerste transistor met geleiden. Dit zorgt ervoor dat de spanning op de base van de tweede transistor stijgt, waardoor deze opent. Nu wordt deze spanning weer laag welke doorverbonden is met de reset pin van de timer. De interne flipflop wordt gereset, en de uitgang gaat nu laag. Omdat er nog een restlading aanwezig is op de condensator, zal deze resterende lading via de release-potmeter en de tweede transistor naar de massa vloeien.

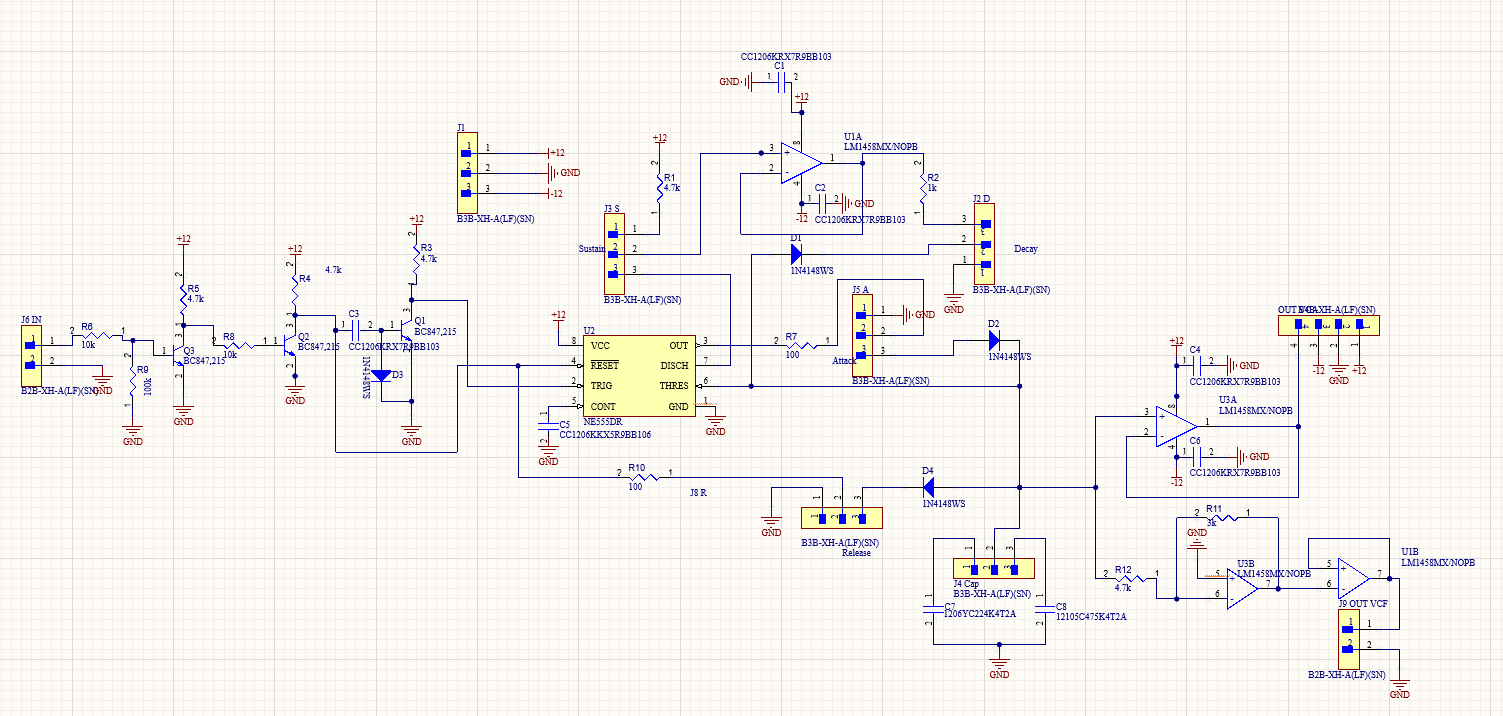
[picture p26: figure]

ADSR schakeling

Het spanningsniveau van de condensator wordt gebufferd en met de voeding doorgestuurd naar de VCA. Het gehele bereik van de envelope bedraagt 0 tot 8 volt. Omdat andere modules zoals het filter de envelope ook nodig hebben, verkleinen we het bereik met een op-amp naar max 5V, dit is een meer gestandaardiseerd voltage.

# VCA

Wat doet een VCA?

Afbeelding met tekst, schermopname, Perceel, lijn Door AI gegenereerde inhoud is mogelijk onjuist.

Een VCA(Voltage-Controlled Amplifier) is een module in een synthesizer die het geluidsniveau (amplitude) regelt op basis van een stuurspanning bijvoorbeeld de omhullende gegenereerd door de ADSR envelope generator. Een VCA wordt gebruikt om de intensiteit van een geluidssignaal te moduleren. De VCA versterkt de geluidssignalen die al gemengd zijn in de mixer.

Ons design maakt gebruik van ‘Long tailed pair’ geschakelede NPN transistoren, toegepast in deze vorm wordt een verschilversterker gecreëerd.

Scopebeeld VCA

CH1: VCA output

CH2: ADSR omhullende


Een LTP verschilversterker bestaat uit twee NPN transistoren welke via hun emitters verbonden worden met een stroombron, in ons geval dient een stuurspanning met een serieweerstand als stroombron(zie R1 in het LTP schema). De collectors van de transistoren worden gezamenlijk gevoed via belastingsweerstanden naar de voedingsspanning(zie R2 en R3 in het LTP schema). De totale stroom blijft constant, de stroom per transistor is afhankelijk van het spanningsverschil tussen de basissen, dit is ook de input. Op de ene base zit V_(in-) en op de andere V_(in+) . De output zit op de collectors, hoe groter het stroomverschil, hoe groter de spanning op de uitgang.

## Eisen

LTP schakeling

- Versterken over de gehele envelop (0 – 8V)
- Weinig vervorming in het hoorbare frequentiedomein (20 – 20kHz)

Afbeelding met tekst, diagram, lijn, nummer Door AI gegenereerde inhoud is mogelijk onjuist.

VCA schakeling

# Mixer

De mixer is nodig om audiosignalen, afkomstig van andere modules (zoals een LFO) en optionele externe bronnen, samen te voegen en vervolgens door te sturen naar de VCA

De schakeling is opgebouwd als een inverterende sommator, waarbij drie ingangen via 100kΩ-weerstanden worden samengebracht op de inverterende ingang van de opamp. Samen met de terugkoppelweerstand ook 100kΩ zorgt dit voor een gelijke versterking van 1 per kanaal. De signalen worden lineair gecombineerd en aan de uitgang geïnverteerd, zonder versterking of verzwakking.

## Eisen

Afbeelding met tekst, diagram, lijn, Parallel Door AI gegenereerde inhoud is mogelijk onjuist.

- Audiosignalen moeten over het gehele bereik van de potmeter gemixt kunnen worden.

Mixer schakeling

# Complicaties

Na dat de schakelingen succesvol op een breadboard waren opgebouwd en getest, was het de bedoeling om van de drie ontwerpen een PCB te maken. Hiervoor hebben we de schakelingen in Altium getekend en de juiste smd(suface mount device) componenten gezocht met dezelfde functionaliteiten als de trough-hole componenten die gebruikt zijn voor de testopstellingen op de breadboards.

Toen de PCB’s eenmaal geleverd waren, ontdekten we echter een aantal fouten. Zo bleek de omzetting van through-hole componenten naar SMD niet overal correct te zijn verlopen. We hadden fouten gemaakt met de keuze voor de SMD componenten, er is door ons onderschat wat de impact van kleine discrepanties in technische specificaties tussen de trough-hole en SMD componenten kan zijn.

Ook bleek op een later moment dat de eisen voor het spanningsbereik van de VCA-schakeling anders waren dan bedacht, hierdoor voldeed de originele schakelingen niet meer. Daarom moesten er aanpassingen gedaan worden om het spanningsbereik te verbeteren. Hiervoor moest dus een nieuwe print gemaakt worden.

verder bleek bij de mixer dat de sporen voor de opamp verkeerd waren gerouteerd in het PCB design waardoor deze afgekeurd was.

Dit betekende helaas dat er geen werkende PCB’s waren. Daarom is besloten om de schakelingen handmatig op gaatjesprint te solderen. Voor zowel de mixer als de VCA is dit goed gelukt. De ADSR bleek echter een stuk lastiger.

Ondanks dat we de ADSR-schakeling drie keer één-op-één van het werkende breadboard hebben overgezet op gaatjesprint, bleef deze weigeren te functioneren. Waarom dit misging, is ons tot op heden een raadsel. Om toch een betrouwbare en robuuste schakeling te kunnen opleveren, hebben we uiteindelijk het originele werkende ADSR-breadboard ingegoten in giethars.

# Testen

Om te testen of alles werkt, en de capaciteiten van de systemen te testen hebben we onze schakelingen grondig nagemeten. Dit hebben we gedaan in de labopstellingen bij Windesheim in Zwolle. Hier kunnen we alle inputs simuleren en de outputs goed analyseren. In het lab kunnen we gebruikmaken van 4 belangrijke apparaten:

- Siglent SPD3303X-E DC-labvoeding
- Tektonix TDS 2002B Two channel digital oscilloscope
- Siglent SDM3045X digitale multimeter
- Siglent SDG1025 function/arbitrary waveform generator

## ADSR

De ADSR-envelopegenerator beschikt over vier instelbare weerstanden waarmee de afzonderlijke fasen — Attack, Decay, Sustain en Release — geregeld kunnen worden. Voor de Attack-, Decay- en Release-fase is het mogelijk de tijdsduur in te stellen, terwijl bij de Sustain-fase het spanningsniveau bepaald kan worden waarop het signaal blijft hangen.

De verschillende fasen kunnen onderling invloed op elkaar uitoefenen. Zo geldt bijvoorbeeld dat wanneer de Sustain op een laag niveau staat ingesteld, de Decay-fase minder ver hoeft terug te zakken in spanning na de piek van de Attack. Hierdoor kan de Decay-tijd korter worden.

We hebben met behulp van een oscilloscoop alle minimale en maximale waarden van de fasen gemeten, en hier schermafbeeldingen van gemaakt. Daarnaast hebben we de lineariteit van de potmeters onderzocht. Elke potmeter heeft een draaibereik van 270 graden. Om het gedrag goed te analyseren, hebben we dit bereik opgedeeld in tien gelijke stappen. Voor iedere tiende positie hebben we de bijbehorende weerstand gemeten tussen de twee niet-verbonden pinnen van de potmeter. Aangezien de rotatie van de potmeter lineair is gekoppeld aan de weerstand, geeft dit een goed beeld van het verloop.

Afbeelding met tekst, schermopname, kaart, diagram Door AI gegenereerde inhoud is mogelijk onjuist.

Meetresutalen parameters ADSR envelope generator

Afbeelding met tekst, lijn, Perceel, diagram Door AI gegenereerde inhoud is mogelijk onjuist.

Meetresutalen potmeters ADSR envelope generator


# VCA

Verhouding lineariteit versterking

## Om de VCA goed te kunnen testen, is gekeken of het ingangssignaal lineair wordt versterkt door de binnenkomende ADSR-envelope. Hiervoor is het versterkingsgedrag gemeten bij een envelopespanning van 0 tot 8 volt. Uit de metingen bleek dat de versterking over dit bereik zeer lineair verloopt.


Ook is er getest of de VCA correct werkt over het volledige hoorbare frequentiebereik, zonder vervorming. Dit werd gedaan door een signaal van 20 Hz (laagste hoorbare frequentie) en 20 kHz (hoogste hoorbare frequentie) naar de ingang van de VCA te sturen. Het uitgangssignaal werd vervolgens vergeleken met het originele ingangssignaal om te controleren of er enige vervorming optrad. Deze vervorming was minimaal en ruim voldoende.

Meetresutalen VCA

## Mixer

De mixer is getest op vervorming en lineariteit. Dit is gedaan door te meten op:

- Alle kanalen helemaal open: uitgangssignaal 4,4V tt.
- 1 kanaal dicht, 1 open: uitgangssignaal 2,2V tt, Precies de helft.
- Ingaand signaal op 20Khz: Uitgangssignaal heeft minimale vervorming.


### SMD-PCB

Afbeelding met tekst, stroomkring, schermopname, Elektronische engineering Door AI gegenereerde inhoud is mogelijk onjuist.

# Conclusie

In dit project hebben we veel geleerd over analoge elektronica en hoe de verschillende onderdelen samen een werkende synthesizer vormen. We hebben onze technische skills flink kunnen verbeteren en kregen meer inzicht in hoe geluidsynthese eigenlijk werkt.

Hoewel we onderweg wat problemen tegenkwamen, zoals niet-werkende PCB’s, hebben we daar juist veel van geleerd – vooral op het gebied van ontwerpen, testen en het oplossen van fouten.

Uiteindelijk hebben we bereikt wat we wilden: de ADSR-parameters zijn apart instelbaar, de VCA versterkt naar behoren en mixer doet het. Deze ervaring geeft ons een goede basis om in de toekomst nog betere modules te bouwen.

Component | type | MFR part no. | Max Rating | Value | Quantity | Discription
Resistor | Metal Film | | 0.25W | 100 ohm | 2
Resistor | Metal Film | | 0.25W | 1 k ohm | 1
Resistor | Metal Film | | 0.25W | 3 k ohm | 1
Resistor | Metal Film | | 0.25W | 4k7 ohm | 5
Resistor | Metal Film | | 0.25W | 10 k ohm | 2
Resistor | Metal Film | | 0.25W | 30 k ohm | 1
Resistor | Metal Film | | 0.25W | 50 k ohm | 1
Resistor | Metal Film | | 0.25W | 100 k ohm | 1
Capacitor | Ceramic | C103 | 50V | 10 nF | 2
Capacitor | Ceramic | C104 | 50V | 100nF | 3 | Decoupling capacitor
Capacitor | Film | | 50V | 1,5 uF | 1
Diode | Glass | 1N4148 | 75V_reverse | | 4 | Small signal fast switching
IC | Timer | NE555N | | | 1
IC | Opamp | LM324N | 0.4V/µs SR | | 1 | Low power quad opamp
Transistor | NPN | BC550C | 50V_CBO | | 3
Potmeter | Lineair | | 60V | 100K | 3
Potmeter | Lineair | | 60V | 10K | 1
Connector | JST | | | 2 pins | 2
Connector | JST | | | 3 pins | 5
Connector | JST | | | 4 pins | 1

## Bills of materials

## ADSR BOM

## VCA BOM

Component | type | MFR part no. | Max Rating | Value | Quantity | Discription
Resistor | Metal Film | | 0.25W | 100k ohm | 7
Resistor | Metal Film | | 0.25W | 10 k ohm | 1
Resistor | Metal Film | | 0.25W | 1k ohm | 2
Resistor | Metal Film | | 0.25W | 68k ohm | 1
Resistor | Metal Film | | 0.25W | 330k ohm | 1
Capacitor | Ceramic | C104 | 50V | 100nF | 2 | Decoupling capacitor
IC | Opamp | TL074 | 20V/µs SR | | 1 | Low noise FET-Input opamp
Transistor | NPN | BC550C | 50V_CBO | | 2
Connector | JST | | | 2 pins | 1
Connector | JST | | | 4 pins | 2

## Mixer BOM

Component | type | MFR part no. | Max Rating | Value | Quantity | Discription
Resistor | Metal Film | | 0.25W | 100k ohm | 4
Resistor | Metal Film | | 0.25W | 50k ohm | 1
Capacitor | Ceramic | C104 | 50V | 100nF | 2 | Decoupling capacitor
IC | Opamp | TL072cp | 12V/µs SR | | 1 | dual audio opamp
Connector | JST | | | 2 pins | 3
Connector | JST | | | 4 pins | 1

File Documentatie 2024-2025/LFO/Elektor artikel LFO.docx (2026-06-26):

# Low-Frequency-Oscillator


In dit project gebruiken we een Op-Amp relaxation oscillator met regelbare frequentie om een LFO circuit te maken voor een modulaire synthesizer. Dit project is volledig analoog en bevat alleen opamp IC’s.


x

Eigenschappen

Regelbare frequentie … tot … Hz

Blok, Driehoek, Sinus

3 outputs

Regelbaar volume

Regelbare offset

Compleet analoog

Voeding +12V, GND en -12V

LFO:

De laagfrequente oscillator (LFO) is een onderdeel van een synthesizer bestaande uit onder meer een generator die een elektrische spanning opwekt met een golfvorm in het laagfrequente, vaak niet hoorbare gebied. Deze spanning kan vervolgens worden gebruikt om een

Ruben Boeve


parameter van een geluidssignaal te moduleren. Afhankelijk van hoe de modulatie plaatsvindt kan dit verschillende effecten opleveren. Een aantal bekende toepassingen zijn modulatie van de amplitude (geluidsniveau) van het geluid (tremolo) en modulatie van de frequentie (toonhoogte) van het geluid (vibrato).


Het hart van de schakeling

De LFO is ontworpen om de opamp relaxation circuit heen. Het opamp relaxation circuit (zie afbeelding 1) werkt doordat de condensator met een bepaalde snelheid oplaad en weer leegloopt. De opamp springt elke keer tegen de Vcc en de -Vcc aan. omdat de opamp niet perfect is zal de golf echter nooit precies Vcc en -Vcc bereiken. Voor dit project is dat niet heel erg omdat we niet werken met super precieze golven, maar toch is het belangrijk om dit in het achterhoofd te houden bij het gebruiken van dit circuit. Voor dit project zal een standaard LM324 geschikt werken. De snelheid van het laden en ontladen van de condensator wordt geregeld door de weerstand R1. Door hier een variable weerstand neer te zetten (bijvoorbeeld een potmeter) kunnen we de frequentie van de golfen veranderen. De frequentie wordt bepaald door de formule in onderstaande afbeelding. Aan de Vout ontstaat een blokgolf en aan de V- ontstaat een soort driehoeksgolf. Uit testen bleek dat door een grotere waarde voor R2 als R3 te kiezen de spanning over de condensator lager wordt en daardoor de driehoek steeds scherper wordt. Dit Circuit biedt hierdoor al een blokgolf en een driehoek golf. Voor het maken van een sinus hoeven we alleen nog maar de driehoek af te ronden. Dit kunnen we doen door een spanningsdeler met 2 diodes.

Afbeelding 1: Op-Amp relaxation circuit

3

2

1


Afbeelding 2: Op-Amp relaxation circuit outputs

Afbeelding 3: Op-Amp relaxation circuit formule frequentie

Het maken van de golven


Als we de LFO combineren met het sinus circuit dan krijgen we het circuit zoals hiernaast is afgebeeld. Om alle golven een even grote amplitude te geven is gekozen om de amplitude van de driehoekgolf (middelste lijn) te gebruiken. in dit geval is dat: 1,09 V. de blokgolf (onderste lijn) krijgt hiervoor een spanningsdeler met de zelfde waardes als die uit de Op-Amp relaxation oscillator. Voor de sinus generator wordt de output van de driehoekgolf gebruikt. Deze gaat eerst door een buffer om de LFO niet te belasten. Hierna volgt het spanningsdeler circuit met 2 diodes die beide anders gepolariseerd staan. Dit is om de top +V en de top -V van de driehoekgolf af te ronden. Om vervolgens de sinus weer enigszins gelijk te maken aan de amplitude van de andere twee golven is er gekozen voor een Op-Amp met een gain van 2. Aan het eind van dit circuit zitten de schakelaars voor het kiezen van de golf. In het uiteindelijke design is hier gekozen voor 2 schakelaars. De eerste voor een keuze tussen de sinus en driehoek-golf, en de tweede voor de keuze tussen de output van de eerste schakelaar en de blokgolf.

Afbeelding 4: schema Falstad

Regelbare Amplitude


Nu we keuze hebben uit 3 soorten golven kunnen we componenten toevoegen aan de schakeling om deze golven nog verder aan te kunnen passen. Nadat de golf is gekozen is er een amplitude regelaar toegevoegd (zie afbeelding hiernaast). Deze amplitude regelaar bestaat uit een buffer met een gain van 2 ,om het signaal een iets groter bereik te geven, met daaropvolgend een potmeter. Deze potmeter geeft een output tussen circa 0 en 2,2 volt output. Hiervoor is een potmeter van 10K geschikt. Omdat het hier gaat om audio amplitude is het aan te raden om gebruik te maken van een logaritmische potmeter. Een logaritmische potmeter klinkt geleidelijker voor het gehoor dan een lineaire potmeter.

Afbeelding 5:schema amplification and volume

Regelbare offset

Voor meer modulatie mogelijkheden is er een offset control toegevoegd. Deze offset varieert tussen 0 en +1,5 V. deze waarden zijn gekozen omdat hiermee het totale signaal aan de uitgang niet hoger wordt als circa 5,5 volt. De offset wordt gemaakt doormiddel van een Op-Amp met een potmeter. De 1,5 volt voor de offset moest zelf in het bordje gemaakt worden. Dit is gedaan door een spanningsdeler met 10k en 1,5k. de spanning die over de 1,5k weerstand heen staat is doorgegeven aan een Op-Amp. De output van deze Op-Amp wordt doorgegeven aan de offset control. Omdat er één extra Op-Amp kanaal was vereist voor deze spanningsbuffer is er gekozen om deUA741CD één kanaals Op-Amp te gebruiken. deze optie was goedkoper en efficiënter als het plaatsen van nog een 4 kanaals lm324.


Afbeelding 7: schema spanningsvolger

Afbeelding 6: schema offset

Outputs

Voor de outputs was het vereist om 3 outputs te hebben. Deze drie outputs hebben een identieke uitgangsspanning, signaalvorm en frequentie. De 3 outputs zijn alle 3 gebufferd en belasten daardoor de andere schakelingen niet. Voor deze buffers zijn gewone Lm324’s gebruikt. Om dit signaal door te kunnen geven aan de andere modules is er gekozen voor een universele jack 3.5 input voor alle modules. Dit is de: “ACJS-MV35-3” geworden.

onderdelen

Onderdelenlijst

- 4u7F condensator 1x
- 1uF condensator 6x
- 1,8K weerstand 1x
- 10k weerstand 7x
- 1k weerstand 8x
- 1,5k weerstand 1x
- Lm324 Op-Amp 2x
- 10k Potmeter 2x
- 250k potmeter 1x
- UA741 Op-Amp 1x
- ACJS-MV35-3 3x
- Diode 2x
- Schakelaar 2x

voor het opbouwen van deze schakeling kan het onderstaande Altium schema worden gebruikt. Let hierbij op dat de 1,1k weerstand die staat in het ronde vlak van de low Frequency Oscillator vervangen moet worden door een 11,8k weerstand. Deze weerstand had standaard al 1.8k moeten zijn maar tijdens testen bleek dat een extra 10k nog wel nodig was (hierover later meer). Verder kunnen voor de potmeters elke soort wel gebruikt worden. Het is wellicht wel handig om logaritmische potmeters te gebruiken omdat we hier werken met audiosignalen. Ook is het nog belangrijk om de ontkoppelingscondensatoren (C2, C3, C4, C5, C6, C7) dicht op de Op-Amp Ic’s te zetten. Dit zorgt voor beter ontkoppeling van de Ic’s. een andere belangrijke correctie is dat aan de ingang van U1b (linksonder), staat dat de square_wave_Out de input is. Dit klopt niet. Hier moet de triangle_wave_OUT staan als input. Anders krijg je geen sinus signaal.


Afbeelding 8: LFO schematic


Opstelling en testen

De schakeling is in eerste instantie gemaakt in een online simulatie programma genaamd: Falstad. Hierin werd duidelijk wat ongeveer de uitgangsspanningen en golfvormen waren aan de outputs. Ook was zo duidelijk te zien welke componenten benodigd waren en wat hun effect was op de schakeling. Nadat er uitbundig getest is met dit simulatie programma is de schakeling opgebouwd op een breadbord. Aan te raden is om ook eerst zelf deze schakeling op te bouwen op een breadbord om te begrijpen wat er aan de hand is in de schakeling zelf en om eventueel nog dingen te kunnen verbeteren. Begin bij het opbouwen van de oscillator (Op-Amp relaxation oscillator) en bouw vanuit daar de schakeling verder uit. Door op een breabord de boel te testen was het gemakkelijk om de oscillator goed af te stellen op de benodigd frequenties en dit door te meten. Ook waren de golfen goed te maken. Hieronder staan de afbeelding van de scope waarop de drie golven staan afgebeeld. Het enigste probleem was dat de opstelling al aardig groot begon te worden en dat de draadjes niet erg betrouwbaar waren. Om dit te verbeteren is een PCB ontworpen.

Afbeelding 9: Breadbord test opstelling LFO


Meetresultaten:


Afbeelding 12: sinusgolf

Afbeelding 11: driehoekgolf

Afbeelding 10: blokgolf

PCB


Om een echt product te kunnen realiseren is besloten dat er een PCB gemaakt moest worden van dit circuit. Hiervoor is Altium-designer gebruikt. In Altium kon gemakkelijk alle componenten en afmetingen ingesteld worden voor het eindproduct. Tijdens het ontwerpen van de PCB moest er ook rekening mee gehouden worden dat de PCB een interface paneel krijgt voor de synthesizer. Hierom is besloten dat er headers geplaatst werden zodat potmeters, schakelaars en outputs gemakkelijk met het PCB en interface paneel konden worden verbonden. Verder moesten er ook bevestiging-gaten op de PCB komen. Deze gaten worden gebruikt om de PCB aan het interface paneel te bevestigen. Dit interface paneel zal uiteindelijk één van de modules worden van de synthesizer

Afbeelding 13: 3D view PCB Altium

PCB resultaat en aanpassingen


Na het monteren van de componenten op de PCB moest de PCB getest worden. Uit testen bleek dat de sinus golf het niet deed. Zoals eerder benoemd kwam dit doordat in plaats van het doorgeven van het driehoeksignaal het bloksignaal werd doorgegeven. Dit is gemakkelijk te verhelpen door het pootje van de IC waarop de blokgolf binnenkwam omhoog te wippen en die vervolgens met een draadje door te verbinden aan de pin waarop de driehoekgolf staat. Na testen bleek dat de sinus mooi in beeld kwam. Het enige probleem dat er nog was aan het PCB was dat de sinus net ongeveer 0.2 V hoger topspanning heeft als de driehoek- en de blokgolf. Dit was op het breadbord ook al het geval maar is verder niet aangepast omdat het een klein verschil is wat in principe geen grote gevolgen heeft. Indien precisie vereist is zou dit opgelost kunnen worden door in plaats van een vaste waarde te nemen voor R8 er een instel potmeter van te maken met een bereik tussen 0 en 2k ohm.

Afbeelding 14: PCB resultaat


Om het PCB even snel te kunnen testen kunnen de potmeters simpelweg op een breadbord gezet worden. omdat het PCB design footprints had voor headers met een pinafstand van 2mm waren de headers eigenlijk net iets te klein voor de pinnen. Om dit op te lossen zijn er grotere headers met de standaard formaat van 2,54mm pinafstand aan de onderkant bevestigd. Omdat in dit design de extra 10k weerstand ook niet geïmplementeerd is op het PCB is deze extra toegevoegd bij de potmeter voor de frequentie. Deze PCB bevatte ook geen duidelijke aanwijzingen voor wat welke pin van de header deed. Het was om deze reden lastig om te bepalen waar voeding en dergelijke aangesloten moest worden. Aan te raden daarom om dit duidelijk op de PCB bij de headers te zetten.

Afbeelding 15: PCB test opstelling

De synthesizer


Deze module is één van de modules van de modulaire synthesizer die ontwikkeld is voor opdracht PIB van Windesheim. Om de synthesizer modulair te maken zijn speciale interface paneeltjes ontworpen waarop de PCB met potmeters en dergelijke bevestigd konden worden. Uiteindelijk kan dit dan gemakkelijk in de synthesizer aangesloten worden. Voor het doorverbinden van in- en outputs is gebruik gemaakt van kortere aux kabeltjes. Voor de voeding is een speciale PCB ontworpen die voeding geeft naar elk van de modules. Om deze voeding te verbinden met de LFO module is een speciaal voedingskabeltje gemaakt.

Afbeelding 16: interface paneel LFO


Afbeelding 18: LFO module in synthesizer

Afbeelding 17: synthesizer

de LFO is vervolgens getest met de ingebouwde voeding en het interface paneel en werkte naar behoren. Hiermee is het sub-onderdeel LFO met succes afgerond en kan de LFO gebruikt worden als modulatie voor de andere modules of als rechtstreekse uitgang naar de speaker voor een laag frequente toon.


Dit project is gemaakt door Ruben Boeve, Student aan het Windesheim in Zwolle. Dit project was onderdeel van Project Ingenieursbureau 2024/2025 opdracht synthesizer.

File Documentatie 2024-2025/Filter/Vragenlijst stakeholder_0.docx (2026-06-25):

Vragenlijst stakeholder

Opdrachtgever: Richard Rosing

- Wie is de gebruiker?
  - A: Meneer Rosing & Meneer Winkelman en de leek.
- Wat is het budget per module?
  - A: Waarschijnlijk 50 euro per groep. Dit aanhouden.
- Moet het systeem modulair zijn of semi modulair?
  - A: Vrije keuze.
- Hoe zit het met het spanningsgestuurde gedeelte?
  - A: Eerst vooronderzoek: hoe kan het überhaupt?
- Wat komt er nog meer bij het filter kijken?
  - A: Vraag is vervallen.
- Hoeveel filters moeten er in onze module zitten?
  - A: In principe één filter, met een heleboel opties. Wat voor output wil je genereren. Vrijekeuze.
- Wat voor parameters moeten wij kunnen aanpassen?
  - A: de frequentie. Instrument afhankelijk bekijken qua cut off.
- Moet het stuursignaal gedempt/verzwakt kunnen worden vóór het filter?
  - A: Andere module afhankelijk. Wat is jouw input.
- Wat gaan wij afstemmen voor de interface qua knoppen, ledjes, etc?
  - A: Voorbeelden bekijken.
- Moeten wij zelf een behuizing voorzien? Zo ja, wat voor middelen hebben wij tot onze beschikking?
  - A: Tenminste veilig voor diegene die het gebruikt.
- Zitten de onderdelen (weerstanden, transistoren, etc.) die al aanwezig zijn bij het Windesheim i.e. die bij Henk en Marcello al bij het budget in of komt dat erbij?
  - A: Vraag is vervallen.
- Is er een minimum/maximum frequentie bereik en geldt dat voor de gehele synth? (tussen 20-20000 Hz bijvoorbeeld)
  - A: Afstemmen andere groepen. Vrije keuze. Welke octaven zijn er gebruikelijk.
- Wat voor inputspanning mag je gebruiken?
  - A: Afstemmen met de voedings groep.
- Is er een voorkeur voor connectoren wat voor de signalen en voedingen?
  - A: Voorkeur gaat naar standaard: audiojack.
- Is er een maximale afmeting van de gehele synth?
  - A: Reëel ontwerpen naar de gebruiker.
- Zijn wij nog iets significants vergeten?
  - A: n.t.b.
- Zijn er nog beperkingen waar wij rekening mee moeten houden?
  - A: n.v.t.

“Using filters to shape your sound” video

Cc naar Mr. Rosing.

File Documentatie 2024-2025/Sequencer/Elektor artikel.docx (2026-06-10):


De sequencer


## Inleiding:

Bij het maken van elektronische muziek is een synthesizer een veel gebruikt instrument. Het biedt diverse manieren van muziek maken en geeft ook direct de mogelijkheid om het signaal te vervormen. Eén van de onderdelen in een Synthesizer is de sequencer, een apparaat waarmee tonen opgenomen worden en vervolgens herhalend worden afgespeeld, om zo een bepaald deuntje te creëren. Afhankelijk van het type sequencer kunnen er verschillende dingen worden ingesteld, zoals de afspeelsnelheid (BPM) en de hoeveelheid toetsen die gesequenced kunnen worden. In dit artikel wordt het bouwproces van een sequencer besproken, er zal hierbij ingegaan worden op zowel hardware als software, waarbij ook mogelijke problemen worden besproken. Uiteindelijk zullen er ook een aantal resultaten getoond worden.


## Andere onderdelen

Het sequencer project is onderdeel van een groter totaalproject, namelijk de al eerdergenoemde Synthesizer. Het is daarom ook belangrijk om ervoor te zorgen dat alle modules met elkaar samen werken. Van een input, geproduceerd door een keyboard, komen er 2 signalen binnen bij de sequencer, een toonhoogte signaal waaraan we kunnen zien welke toets is ingedrukt en een gate signaal, deze is enkel om aan te geven dat er een toets wordt ingedrukt. Het laatstgenoemde signaal gebruikt de sequencer niet, maar hij genereert er wel eentje. Vervolgens wordt ons signaal dus opgeslagen en doorgeven aan de na ons komende onderdelen. Dit moet uiteindelijk muziek maken.

## Het onderzoek

Voordat men kan onderzoeken hoe een sequencer werkt, zijn er een paar doelen gezet. Deze doelen moeten reëel en haalbaar zijn. Vanuit deze doelen wordt onderzoek gedaan, om die doelen te behalen. Deze zijn weer ingedeeld in twee delen: benodigd eisen en extra eisen.

Benodigd eisen:

- Het lezen van signalen
- Het opslaan van signalen
- Het uitspelen van de opgeslagen signalen

Extra eisen:

- Het aanpassen van de snelheid van de sequence
- Heb verschillende modes hoe de sequencer gedraagt
- Geef visueel feedback aan de gebruiker

### Signalen

Voordat de signalen gelezen kunnen worden, moet eerste het signaal gedefinieerd worden. Hierbij kan men bepalen welke benodigdheden moet kiezen voor de sequencer.
De binnenkomende signalen voor de sequencer zijn: de gate en de toon. De gate signaal wordt gebruikt om wanneer de toon wordt ingedrukt aan te tonen. De voltages van de gate is, 3.3V of 0V. Ook geeft de gate aan wanneer er een nieuwe toon is, tussen de noten in. Hierbij zal de gate snel van 3.3V naar 0V en teruggaan.
De toon geeft aan welke toon je afspeelt. Deze wordt bij de oscillator (VCO) omgezet in een geluidssignaal. De Oscillator verwacht een signaal tussen de 1 en 3 volts. Daartussen zal 24 verschillende tonen bepaald worden.

### Het lezen, opslaan en uitspelen van de signalen

Om signalen te kunnen verwerken, moet men het signaal kunnen aflezen. Hier wordt gebruik gemaakt van een analog to digital converter (ADC). Hiermee zet je elektronische signalen om in een bit. Deze bit-waardes kan worden gebruikt in het softwaresysteem. De conversie wordt moment
In het softwaresysteem zijn er meerdere manieren om bit-waardes op te kunnen slaan. Bits kunnen in een opslagapparaat opgeslagen worden of in de memorie van de Microcontroller. Het gebruiken van een opslagapparaat heeft 1 voordeel over het opslaan in de memorie. Met het opslagapparaat wordt de data behouden wanneer men de microcontroller uit en aan zet. Het nadeel ervan is dat je extra onderdelen moet toevoegen om het opslagapparaat te gebruiken.
Na het opslaan van de data, moet het data weer gebruikt worden om dat om te zetten naar een signaal. Hierbij wordt een digital to analog converter (DAC) gebruikt. Hierbij worden bits omgezet naar een analoog signaal.

### De snelheid van de sequence

Sequencers moeten in de maat spelen. Soms is de maatsnelheid niet altijd hetzelfde. Bij veel gemaakte sequencers wordt een knop of draaiknop gebruikt om de snelheid te bepalen. Een knop kan je gebruik om zelf het tempo aan te passen met behulp van muzikaal gevoel. De draaiknop kan je het tempo aanpassen door te draaien. Meeste draaiknoppen gebruiken een analoog signaal en een voltage deler. Met behulp van ADC, kan je het tempo aansturen met behulp van een microcontroller. Het voordeel van een draaiknop is dat je niet muzikaal gevoel moet hebben, ten opzichte van de knop.

### Modes van de Sequencer

De sequencer moet verschillende manieren gedragen op basis van welke mode het in zit. Veel sequencers hebben twee verschillende modes: recording (opslaan) en playing (afspelen). Bij recording zal de sequencer alles opslaan wat ingevoerd wordt. Bij playing zal de sequencer niet meer tonen opslaan, maar de opgeslagen tonen worden afgespeeld.
Soms is de sequence niet correct. Hier kan men een andere mode gebruiken, de replace. Hierbij behoudt hij de sequence, maar vervangt de toon als er een input wordt gedaan op dat moment in de sequence.

### Visueel feedback

De sequencer kan meerdere manieren gebruiken om visueel feedback te geven aan de gebruiker. In meeste gevallen worden LED's gebruikt om het volgende te laten zien; in welke modes hij zit, hoe snel hij afspeeld of waar de sequence in de maat zit. Dit is budget vriendelijk. Een ander manier voor visueel feedback is het gebruiken van een scherm. Hier kan de ontwikkelaar parameters en andere visuele steun op zetten. Het nadeel hiervan is dat het meer geld en tijd kost om het voor elkaar te krijgen.

## Het schema

### Input

Na nauwkeurig gekeken te hebben hoe het beste resultaat bereikt kan worden, is er ontwerp gemaakt. Zie (figuur 1). Links onderaan bevindt zich het blok J7, dit is een 3.5mm audiojack die functioneert als input. De lijnen splitsen zich op naar een 2e audiojack, met als doel om direct af te kunnen spelen en naar de microcontroller. Lijn 3 wordt gebruikt als Gate, en lijn 4 geeft een toonhoogte signaal. Echter moeten we voorkomen dat de spanning op de ADC binnen marge van 2.048V blijft, en de input om lijn 4 is maximaal 3V. Om hiervoor te zorgen wordt een spanningsdeler toegepast, in dit geval R11 en R12. Deze zorgen voor een verzwakking van het signaal volgens de formule: Vout=(R12)/(R11+R12)∗Vin=(8,2k)/(8,2k+3,9k)∗3,0V= 2.033V , Exact binnen de spanningslimiet. Vervolgens komt dit signaal binnen op Pin PD5, hier wordt vervolgens de ADC gebruikt, hier meer over in de code.

### Knoppen

Links bovenaan de tekening zijn de connectoren J1 t/m J4 te vinden. Dit zijn Dupont-connectoren die worden gebruikt om knoppen aan te sluiten. Om te voorkomen dat de pinnen van de microcontroller zwevend blijven, zijn pull-down-weerstanden (R1 t/m R4) toegevoegd. Deze weerstanden hebben elk een waarde van 100 ohm en zorgen ervoor dat de pinnen naar een logische laag (grond) worden getrokken wanneer de knop niet is ingedrukt. Bij het selecteren van pull-down-weerstanden is het van belang te kijken of het vermogen wat de weerstand dissipeert niet te hoog is. Aangezien er in dit geval maximaal 3,3V op staat, en de weerstand 100 ohm is, kan dit met de volgende formule gecontroleerd worden: P=(U^2)/R=(3,3^2)/100= 0,11 W , dit is ruim binnen de marge van vrijwel alle weerstanden (standaard is 0,250W). P2 biedt de mogelijkheid om een potentiometer op aan te sluiten. Ook deze kan worden uitgelezen door middel van de ADC en wordt in dit geval gebruikt om de BPM te regelen.

### Microcontroller en voeding

Bij het selecteren de microcontroller is gekeken naar prijs, functies en beschikbaarheid. Hieruit is de AVR128DB28 gekomen, een niet al te dure microcontroller met een hoop functies. Hoewel veel microcontrollers voldeden aan de door ons gestelde eisen, was deze ook nog eens voorradig. De AVR beschikt over een 12 bits ADC en 10 bits DAC, wat voldoende resolutie geeft. Ook geeft de AVR de mogelijkheid om zowel met 3,3 als met 5V gevoed te worden, waardoor hij flexibel in te zetten is. Als er gekeken wordt naar de plaatsing van de microcontroller zijn de condensatoren C1 t/m C6 te zien. Deze dienen als voedingsontkoppeling om ervoor te zorgen dat de inkomende spanning stabiel is. De waarden worden in de datasheet voorgeschreven. Te zien is ook nog P1, Deze is aangesloten aan de UPDI-poort van de microcontroller. Dit geeft later de mogelijkheid om code naar de microcontroller te sturen door middel van een UPDI-programmer. Het is hierbij praktisch om er een voedingslijn naar toe te leggen, zodat er geen externe voeding nodig is tijdens het programmeren.

### De Operationele Versterker

Eerder is besproken dat het noodzakelijk was om het toonhoogtesignaal te verzwakken. Dit introduceert echter een probleem: de uitgangsspanning valt hierdoor niet meer binnen het oorspronkelijke bereik. Om dit te corrigeren, moet het signaal worden versterkt met dezelfde factor waarmee het eerder werd verzwakt. Dit wordt gerealiseerd met een operationele versterker, ook wel op-amp genoemd, die in het schema te vinden is als U1.

Door de op-amp correct aan te sluiten en gebruik te maken van de weerstanden R9 en R10, wordt het signaal versterkt volgens de formule:

Vuit=(R9+R10)/(R9)*Vin=(8,2k+3,9k)/(8,2K)* 2.033V= 3,00V

Het versterkte signaal ligt nu weer keurig op het gewenste niveau en wordt vervolgens via J6, de output van de sequencer, uitgevoerd.

Er is gekozen voor een LM324 als op-amp, vanwege de lage kosten en omdat deze voldoende nauwkeurig is voor onze toepassing. Een belangrijke eigenschap van de LM324 is dat de voedingsspanning minimaal 1,5 V hoger moet zijn dan het maximale signaalniveau dat wordt verwerkt. Daarom wordt de op-amp gevoed met 12 V, wat beschikbaar is via de voedingsmodule.

Om de op-amp stabiel te laten werken, is een ontkoppelcondensator (C7) toegevoegd aan de voedingslijn. Deze voorkomt ongewenste ruis en spanningsfluctuaties.

### De LED

Om te laten zien wat de huidige maat is worden LED’s gebruikt. Binnen de tekening is gekozen van LED’s met een benodigde voeding van ongeveer 2V, met een nominaal verbruik van 20mA. Dit zorgt voor een probleem, aangezien er 3,3V uit de digitale uitgang komt van de microcontroller. Om dit op te lossen zijn de weerstanden R5 t/m R8 toegevoegd. Deze zorgen voor een spanningsverval. Het nodige spanningsverval is 3,3 – 2,0 = 1,3V. Door gebruik van de wet van ohm te maken is de weerstandswaarde te vinden: R=U/I=(1,3)/(20m)=65Ω . Dit dichtstbijzijnde waarde uit de voorraad was 68Ω. Op deze manier kan voorkomen worden dat de LED’s doorbranden.Figuur 1: het schakelschema van de sequencer


## Opbouw

Nu het volledige schema gereed is, kan de PCB ontworpen en opgebouwd worden. Voor een efficiënte opbouw is het aan te raden om eerst alle SMD-onderdelen te bevestigen.

1. Op-amp bevestigen

Begin met het plaatsen van de op-amp, de LM324, op de positie van U1. Zorg ervoor dat de op-amp correct georiënteerd is. Als deze verkeerd wordt geplaatst, zal de voeding omgekeerd aangesloten worden, wat ervoor zorgt dat de op-amp niet functioneert of zelfs beschadigd raakt.

2. Condensatoren en weerstanden plaatsen

Nadat de op-amp is bevestigd, kunnen de condensatoren en weerstanden worden gesoldeerd. De volgorde waarin dit gebeurt, is niet strikt van belang. Wel moet je aandacht besteden aan de juiste waarden van de condensatoren, omdat deze visueel sterk op elkaar kunnen lijken.

- Condensatoren: Bij elke voedingsingang van de microcontroller horen twee waarden: een van 1 µF en een van 100 nF. Omdat deze keramisch zijn, hoeft de polariteit niet in acht genomen te worden. Voor de op-amp moet je C7 solderen, een 100 nF condensator. Zorg ervoor dat de op-amp tijdens het solderen niet beschadigd raakt door overmatige hitte.
- Weerstanden: Het proces voor het solderen van de weerstanden is vergelijkbaar. Let erop dat je de juiste weerstand op de juiste plek plaatst.

3. Voetje voor de microcontroller plaatsen

Als alle SMD-componenten bevestigd zijn, is het moeilijkste deel afgerond. Nu kan op de plaats van IC1 een voetje worden geplaatst voor de microcontroller. Dit voetje maakt het mogelijk de microcontroller eenvoudig te vervangen, mocht deze beschadigd raken of als je hem voor een ander project wilt gebruiken.

4. Pinheaders en JST-connector bevestigen

Vervolgens kunnen de Dupont-pinheaders en de JST-connector voor de voeding worden bevestigd. Depinheaders worden geplaatst op P1, P2 en J1 t/mJ4. P1 blijft vrij voor het programmeren. Op P2 kan een 10k potentiometer worden bevestigd, en aan J1 t/m J4 een schakelaar of knop naar keuze. Deze onderdelen zouden eenvoudig te solderen moeten zijn.

5. LED’s plaatsen

Plaats de LED’s (D1 t/m D4) op de PCB. Als je de LED’s verder van de print wilt positioneren, kun je draadjes gebruiken om ze te verbinden. Let bij de LED’s op de oriëntatie: het lange pootje moet door het gaatje aan de kant waar het +-teken op de print staat.

6. 3.5mm-audiojacks bevestigen

Als laatste zijn de 3.5mm-audiojacks (J6, J7 en J8) aan de beurt. Deze jacks passen slechts op één manier op de PCB en moeten allemaal dezelfde oriëntatie hebben. Het solderen van deze onderdelen kan lastig zijn, omdat ze een groot oppervlak hebben. Hierdoor duurt het langer voordat ze voldoende warm zijn om gesoldeerd te worden. Om dit proces te versnellen, kun je de soldeerbout iets hoger instellen dan normaal.

7. De AVR plaatsen

Als het goed is, zijn er nu geen lege plekken meer op de PCB, behalve de voet voor het IC. Plaats de AVR-microcontroller voorzichtig in de voet. Zorg ervoor dat de oriëntatie correct is: er zit een klein inkeping (of stipje) aan de bovenkant van de chip. Deze inkeping moet in de richting van de LED’s wijzen. Een verkeerde oriëntatie kan leiden tot schade aan de microcontroller of andere componenten wanneer de voeding wordt aangesloten.

Afbeelding met tekst, schermopname, diagram, stroomkring rtyhrtthshthtshrt

Figuur 2: doorzichtig pcb-design van het sequencer


Figuur 3: 3d PCB-design van het sequencer


Figuur 4: de PCB-design

## De code

Om de signalen op te slaan gebruikt de sequencer een array die uit 10bits bestaat. Dezelfde type bits als de uitkomst van de ADC en inkomst van de DAC. Dit zorgt ervoor dat er zo klein mogelijk conversie fouten kunnen ontstaan.
Wanneer de sequencer start is zijn taken gesplitst in twee delen: het sequencen en state management. De state management wordt continue gecheckt in tegenstelling tot het sequencen. Tijdens de state management, kijkt de microcontroller aan de pins een spanning wordt geleverd. Hierbij zijn 3 toegewijde pins. Deze pins bepalen in welke state(mode) hij in zit. Een andere pin is verbonden met de delete knop. Wanneer deze pin aan staat, zal hij alle waardes van de lijst op 0 zetten. Waardoor de hele sequence verwijderd is.
Tijdens het sequencen wordt maar eens in de zoveel tijd aangeroepen met behulp van een timer. Hierbij wordt er een 'count' bijgehouden die bepaald waar hij is in de sequence. Ook wordt gecheckt welke state hij zit. Aan de hand van de state doet hij de volgende:

Recording:
De pin van de toon wordt afgelezen (ADC), deze wordt opgeslagen in de array Toon op de plek 'count'. replace:
De toon in de array op de plek 'count' wordt uitgestuurd (DAC). De microcontroller leest ook de toon afgelezen (ADC), die toon wordt op dezelfde plek gezet als de uitgestuurde toon.
Play:
De toon in de array op de plek 'count' wordt uitgestuurd (DAC).

Om het tempo te veranderen wordt ADC en een Potmeter gebruikt. Maar ADC kan niet altijd aangeroepen worden. De microcontroller heeft tijd nodig om van ADC pins te kunnen veranderen. Hierbij wordt de timer gehalveerd en zal dus twee keer zo snel zijn. Deze timer zal één van de twee dingen doen; tempo veranderen of de sequence.

Wanneer er tonen uitgespeeld wordt, moet er nog een gate genereerd worden. Gate wordt hoog gezet wanneer er een toon gespeeld wordt. De gate moet ook laten zien dat er een nieuwe toon is gespeeld. De code checkt constant of toon verandert plus dat het boven de 0 is, met behulp van een variable die een paar clock cycles achter zit. Als de variable niet gelijk is aan de toon die uit wordt gestuurd. Zal de gate voor een paar cycles laag gezet en daarna weer hoog.

Code fragmenten zijn te vinden onderaan het document.*

## Testen

Om te testen hoe goed de sequencer werkt, kan getest worden door een signaal van 0 tot 2 volts aan te sluiten die op een lage frequentie loopt. Bij de volgende test is er een driehoek signaal in de toon gezet. Uit de sequencer zal een blokgolf die een driehoekgolf na doet. Hierbij zal je de gate constant zien dippen. Hierbij wordt het volgende als uitgangssignaal.


Figuur 5: verwachte uitgangssignaal van de toon en gate.

Om de kwaliteit te testen van het uitgangssignaal. Moet men een dc-signaal in het ingangssignaal gedaan. Dit signaal probeer je op te slaan. Daarna wordt dit signaal als uitgangssignaal gezet. Dit uitgangssignaal meet je met behulp van een oscilloscoop of multimeter. De precisie van de toon bereken je door het gemeten waarde af te trekken van het ingangssignaal. Uiteindelijk kan dat gedeeld worden door 0,0833 (de stap grootte van de toon in Volt) en dat keer 100%.

## Het resultaten

De resultaten van test 1, die focust op het sequencen.


Figuur 6: reële uitgangssignaal van de sequencer

In figuur 6 is te zien dat de driehoek signaal omgezet is in een blokjes die een deel van een driehoeksignaal representeerd. In het midden van de meeting is een sprong, dit sprong is het overgang van het eind van de sequence naar het begin. De overgang van de rechterkant van de meeting, komt direct over naar de linkerkant.

De resultaten van test 2, waar het wordt focust om de nauwkeurigheid te meten en bereken. Hieruit komt de volgende meetingen en resultaten:

Uin (V) | Uuit (V) | Onnauwkeurigheid (%) | Wisseling (%)
1,000 | 0,975 | 30,0 | 1.5
2,000 | 1,979 | 24,6 | 1.5
3,000 | 2,982 | 21,0 | 1.5

De Wisseling % is de hoeveelheid volts in percentage de sequencer kan schommelen. Een opmerking over de
de onnauwkeurigheid is het percentage hoe ver het signaal afwijkt tenopzichte van de grootte van de toon stappen. Hierbij zit het uitgangssignaal zit altijd 25mV onder het proberende signaal. Die steeds afneemt naar mate het signaal hoger wordt. Deze offset kan met softwarematig manieren op te lossen.

## Conclusie

Bij het maken van dit project zijn een aantal zaken bijzonder goed gelukt. Zo is het gelukt om:

- Een goed instelbaar signaal te genereren dat nauwkeurig afgestemd kan worden op de gewenste toepassing.
- Een bruikbaar gate-signaal te realiseren, wat essentieel is voor de correcte synchronisatie met andere modules.

Accuratie

Tijdens het testen bleek echter dat de accuratie van het systeem een beperking vormt. Met een onnauwkeurigheid van 21,0% <-> 30,0% in de gegenereerde signalen, voldoet het niet aan de eisen. Dit zorgt ervoor dat wanneer we een spanning binnenkrijgen er een redelijk grote kans is dat de uitgaande spanning zoveel hoger of lager ligt dat er een compleet andere noot gespeeld wordt, wat de sequencer minder bruikbaar maakt.

Aanbevelingen

Om de accuratie te verbeteren, raden wij een aantal dingen aan:

Gebruik van een betere microcontroller: De huidige microcontroller is functioneel, maar niet optimaal voor taken die nauwkeurige ADC (Analog-to-Digital Converter) en DAC (Digital-to-Analog Converter). Ook zal het helpen om weerstanden te kiezen met strakke toleranties of voor het plaatsen de weerstanden na te meten en te matchen.

# Componentenlijst:

Weerstanden (SMD 1206):

R1, R2, R3, R4 :100Ω

R5, R6, R7, R8: 68Ω

R9, R12: 8,2kΩ

R10, R11: 3,9kΩ

Condensatoren (SMD 1206):

C1, C4, C6, C7: 100nF

C2, C3, C5: 1uF

Halfgeleiders:

D1, D2, D3, D4: 3mm Led met spanning van ~2V

Connectoren:

P1, P2: 3x1 2.54mm pin header

J1, J2, J3, J4: 2x1 2,5mm pin header

J5: 2.54mm JST-connector

J6, J7, J8: 3.5mm audiojack, ACJS-MV35-3

Knoppen en accessoires:

Aan P2: 10K potentiometer naar keuze

Aan J1 t/m J4 schakelaar of knop naar keuze.

Overig:

U1: lm324DT, so-14 uitvoering

IC1: AVR128DB28-I/SP

# Code fragmenten

Recording, replacing en playing en hoe het is toegepast


De code dat Gate genereert


Het switchen tussen nieuwe tempo regeling of sequensen


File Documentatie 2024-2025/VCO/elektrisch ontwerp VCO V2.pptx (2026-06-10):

## Modulaire Synthesizer, VCO hardware design.

Thijn Berkhoff – 1198746
Ralph Hänninger – 1197535
Begeleid door Marco Winkelman

Mijn startpagina

16-10-2024
Zwolle

## Inhoudsopgave

- Inleiding
- Eisen
- beperkingen
- Elektronisch ontwerp
- Beoordeling ontwerp
- conclusie

## inleiding

Opdracht: samen met verschillende modules een synthesizer maken
Doelstelling: het maken van een werkende VCO die op de andere modules aansluit

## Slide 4

Eisen | functioneel | Niet-functioneel | verplicht | optioneel | prioriteit
1v/octaaf | x | | x | | 1
stroombeveiliging | | x | x | | 1
2 uitgangssignalen | x | | x | | 1
Bescherming in- en outputs | | x | x | | 1
PCB zo klein mogelijk | | x | | x | 3
Blok, driehoek en zaagtand signaal | x | | x | | 2
Moet samenwerken met andere modules | x | | x | | 1
Elektronica moet zichtbaar zijn | | x | x | | 3
Enige middelen tegen warmtevervoming | | x | | X | 3
Instelbare lineariteit en zaagsignaal | x | | | x | 2

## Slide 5

Beperkingen

Stroom en spanningslimieten.
Budget van 50 euro.
Geen kant en klare componenten. (devboards, Modules ETC)
Uiteindelijke afmetingen van het volledige design.

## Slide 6


## Componenten, opamp

- Texas Instruments NE5532 Dual Low noise opamp
  - Specifiek gemaakt voor audio, zeer lage slewrate
  - Zowel de SMD als de trough hole variant zijn beschikbaar op Mouser.com, trough hole zoiezo op conrad
  - https://nl.mouser.com/ProductDetail/Texas-Instruments/NE5532PSR?qs=bkMXpVdiF42odhJUqZo0sQ%3D%3D

## Componenten, BJT’s

- PNP: BC557, algemene PNP BJT
- NPN: BC547, algemene NPN BJT
Niet lineaire regio's zijn makkelijk te behalen in deze transistoren, dus geschikt voor exponentiële converter
Zijn ook te verkrijgen op bijvoorbeeld Mouser of Conrad.
https://www.conrad.nl/nl/p/diotec-transistor-bjt-discreet-bc547c-to-92-3-aantal-kanalen-1-npn-140539.html
https://www.conrad.nl/nl/p/diotec-transistor-bjt-discreet-bc557b-to-92-3-aantal-kanalen-1-pnp-140543.html

## Componenten, diodes

- 1n4148 diode
In voorraad bij de labbeheerders
Kleine spanningsval over de diode
Geen onnodige grote waardes

## Video aantoning stabiel zaagsignaal.


## Beoordeling

- Wat voldoet in dit ontwerp?
  - uitgang zaag en blok
  - 2 uitgangsignalen
  - exponentiële toename frequentie op basis van ingang spanning
  - instelbare lineariteit
  - Instelbare finetune
  - stroombeveiliging
- Wat ontbreekt nog?
  - Driehoekspanning
  - Middelen tegen warmtevervorming

## Conclusie

- We zijn in tijdsnood gekomen.
- Ons ontwerp voldoet nog niet volledig aan onze eisen.
- De basisfuncties van de VCO zijn operationeel.

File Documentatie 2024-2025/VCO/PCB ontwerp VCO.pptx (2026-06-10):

## Modulaire Synthesizer, VCO Plan van aanpak

Thijn Berkhoff – 1198746
Ralph Hänninger – 1197535
Begeleid door Marco Winkelman en Richard Rosing

Mijn startpagina

20-11-2024
Zwolle

## Inhoudsopgave

- Inleiding
- PCB ontwerp
- Design rule check
- Onderbouwing plaatsing componenten
- Einde


## inleiding

Opdracht: samen met verschillende modules een synthesizer maken
Doelstelling: het maken van een werkende VCO die op de andere modules aansluit

## Eisen

- Functioneel

- Niet functioneel

Eisen | Voldaan?
1v / octaaf | Ja
2 uitgangssignalen | Ja
Blok, driehoek en (inverse )zaagsignaal | Driehoeksignaal ontbreekt
Instelbare lineariteit | ja

Eisen | Voldaan?
Stroombeveiliging | Ja
Zichtbare elektronica | Ja
Preventie warmtevervorming | Ja

## PCB ontwerp

Grotendeels SMD
Voldoet aan eurorack standaard
Geen routing hoeken van 90°
Mounting holes aanwezig
Connectiviteit met interface via header pins
Geen “dead copper” op de PCB

## Voorkant PCB


## Achterkant PCB


## Schematische weergave PCB


## Design Rule Check

- Design voldoet aan de check van Altium
- Rules van fabrikant zijn meegenomen


## Onderbouwing plaatsing componenten BJT’s

- Dicht bij elkaar
- Dicht bij de VCO’s
- Geeft minder warmtegevoeligheid
- Geen onnodig lange draden


## Onderbouwing plaatsing componenten opamps

- VCO’s in het midden
- Inverter, comparator en buffer links
- VCO’s liggen zo lekker centraal
- De linkerkant is zo gereserveerd voor signaalverwerking


## Onderbouwing plaatsing componenten condensatoren

- Ontkoppel condensators dichtbij hun IC’s
- Condensators voor de VCO’s bij elkaar
- Minder ruis op de voedingslijnen
- De condensator banken zijn makkelijker te solderen


## Onderbouwing plaatsing componenten in- en outputs

- Voeding dichtbij de rand
- In- en uitgangsignaal met headers
- Voedingskabel kan makkelijker ingeplugd worden
- Flexibiliteit voor het plaatsen van de audiojacks


## Einde

Zijn er nog vragen?


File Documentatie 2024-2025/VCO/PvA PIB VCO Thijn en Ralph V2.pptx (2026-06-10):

## Modulaire Synthesizer, VCO Plan van aanpak

Thijn Berkhoff – 1198746
Ralph Hänninger – 1197535
Begeleid door Marco Winkelman en Richard Rosing

Mijn startpagina

11-9-2024
Zwolle

## Inhoudsopgave

- Achtergrond project
- Doelstelling project
- Programma van eisen
- Schema’s
- Probleemstelling en onderzoeksvragen
- Projectgrenzen en randwaarden

## Achtergrond project

Mengpaneel

- De volledige opdracht is om samen met andere duo’s een modulaire synthesizer te maken.
- Onze opdracht is om een “voltage controlled oscillator” te maken.
- De aanleiding is het vak project ingenieursbureau.
- Stakeholders:
  - Marco Winkelman
  - Richard Rosing
  - Gebruikers van de VCO
  - Andere modules in de synthesizer
  - PCB fabrikant

## Doelstelling project

Achtergrond met printplaat

- Einde van het project: volledige VCO-module.
- Persoonlijke doelen,
  - Thijn: meer inzicht en kennis analoge elektronica.
  - Ralph: het begrijpen en gebruiken van analoge elektronica.

## Programma van eisen

- Functionele eisen

- Niet-functionele eisen

1. 1v / octaaf
2. 2 uitgangssignalen
3. Ten minste blok, driehoek en zaagsignalen
4. Budget van 50 euro
5. Moet samen kunnen werken met de andere modules
6. Instelbare Lineariteit
7. Instelbaar zaagsignaal

1. Enige stroombeveiliging
2. Bescherming op in- en outputs
3. Zo klein mogelijke PCB
4. Elektronica moet op een bepaalde manier zichtbaar zijn
5. Aanwezigheid van onderhoudspotentiometers tegen warmtevervorming

## Beperkingen

Stroom en spanningslimieten.
Budget van 50 euro.
Geen kant en klare componenten. (devboards, Modules ETC)
Uiteindelijke afmetingen van het volledige design.

## Blokschema


## Usecase schema


## Probleemstelling en onderzoeksvragen.

Hoe kan je een oscillator “voltage controlled” designen?
Hoe halen we in ons design 1V/octaaf?
Welke uitgangspanningen worden van ons verwacht?
Hoe moet het interface eruit zien?
Hoe verbinden we de VCO met de andere modules?
Hoe precies moet de VCO zijn?

## Projectgrenzen en randvoorwaarden

Binnen ons project valt:
- Het designen en ontwerpen van een dubbele VCO
- 2 uitgangssignalen met variabele golven
- Het krijgen van 1V / octaaf
- Een duidelijk interface designen
Buitens ons project valt:
- De DC-inputspanningen.
Het project is een succes als:
- De VCO volledig operationeel is met de andere modules.

## EINDE

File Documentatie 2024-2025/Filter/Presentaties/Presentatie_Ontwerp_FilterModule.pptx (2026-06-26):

## Project Ingenieursbureau VCF Ontwerp


Opdrachtgever: Windesheim
Bedrijf: Pulse Soundworks
Datum: 16-10-’24
Diémo Rijsdijk: 1200704
Jens Kuizenga: 1175555

## Inhoud

- Inleiding
- Opdracht en doelstelling
- PvE
- Beperkingen
- Schema
- Onderbouwing componenten
- Beschikbaarheid
- Metingen
- Voldoen aan eisen
- Demonstratie

## Inleiding

- Voor het vak PIB gaan wij een synthesizer bouwen waarvan wij het filter gaan maken
- Het doel van het project is het produceren van een effectfilter module voor een modulaire synth die de kantelfrequentie kan regelen via een interface en via een input door middel van een spanning
- Aan het eind van het project wordt er een werkende synth opgeleverd.

## Opdracht en doelstelling

- High-pass en Low-pass
- Low-pass spanningsgestuurd
- 3e orde
- Tevredenheid klant → werkend product
- Einddatum

## Programma van eisen

Functionele Eisen:
- Een laagdoorlaat- en hoogdoorlaatfilter of bandfilter in één module
- De kantelfrequentie van de low-pass is instelbaar met een extern stuursignaal
- Kantelfrequentie van beide filters is instelbaar met een potmeter
- Een bandbreedte van ten minste 4 octaven
- De kantelfrequentie is instelbaar van 100Hz-5kHz

## Programma van eisen

- Niet-functionele Eisen
- Veilige spanningen voor de gebruiker.
- De Maximale kosten bedragen 50€.
- De volledige constructie moet ten miste tilbaar zijn door één persoon.
- De pcb’s zijn zichtbaar te maken zonder demontage
- Modulair systeem.
- 3.5mm jack connectoren voor signalen.

## beperkingen

- Componenten die bij Windesheim op voorraad zijn
- PCB-ontwerp voldoet aan de door de fabrikant gestelde beperkingen
- Geen end-of-life componenten
- Max. afmetingen → behuizing

## Schema


## Schema


## Onderbouwing componenten input

- Ingangsfilter > ~20Hz
- Spanningsdeler --> 400mVpp
- Offset --> ~1.5-2.5V

## Onderbouwing componenten diodeladder

- Condensatoren
- Diodes
- Outputversterking


## Beschikbaarheid

- TL072H: Circa 30.000 (15-10-'24) Bij Mouser
- BAV99: Circa 65.000 (15-10-'24) bij Mouser
- Weerstanden, condensatoren en overige diodes beschikbaar bij de Werkplaats

## Metingen

- Is het meetbaar?
- THD


## Metingen

- - Vergelijking met “normaal” 3e orde filter


Diode ladder filter


“normaal” 3e orde filter

## “Weerstand” diodes


## Voldoen aan eisen

- Laag en hoogdoorlaat
- Kantel frequentie via potmeter
- Kantel frequentie via control voltage
- Bandbreedte wordt door de componenten bepaald.
- Evenals de kantelfrequentie

## Demonstratie!!!

## Einde

- Zijn er nog vragen?

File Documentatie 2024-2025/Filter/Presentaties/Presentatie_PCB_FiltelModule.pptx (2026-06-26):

## Project Ingenieursbureau VCF PCB


Opdrachtgever: Windesheim
Bedrijf: Pulse Soundworks
Datum: 20-11-’24
Diémo Rijsdijk: 1200704
Jens Kuizenga: 1175555

## Inhoud

- Inleiding
- Opdracht en doelstelling
- Beperkingen
- Schema
- PCB-ontwerp
- Haalbaarheid

## Inleiding

- Voor het vak PIB gaan wij een synthesizer bouwen waarvan wij het filter gaan maken
- Het doel van het project is het produceren van een effectfilter module voor een modulaire synth die de kantelfrequentie kan regelen via een interface en via een input door middel van een spanning
- Aan het eind van het project wordt er een werkende synthesizer opgeleverd.

## Opdracht en doelstelling

- High-pass en Low-pass
- Low-pass spanningsgestuurd
- 6-dB/oct demping
- Tevredenheid klant → werkend product
- Einddatum

## Beperkingen

- Zoveel mogelijk componenten die bij Windesheim op voorraad zijn / standaard componenten
- PCB-ontwerp voldoet aan de door de fabrikant gestelde beperkingen (→ Altium)
- Geen end-of-life componenten
- Goede beschikbaarheid componenten, lage prijs
- Max. afmetingen → behuizing


## Elektronisch schema


- Eigenschappen
  - Diode als weerstand
  - Spanningsafhankelijk


## PCB-ontwerp


- Beperkingen fabrikant
- Elektrische en mechanische verbindingen naar front
- Dikte traces, layout


## PCB-Ontwerp


## PCB-Ontwerp


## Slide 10


## Componenten - onderbouwing

- Film condensatoren weinig aanbod SMD
- SMD componenten, goedkoop, snelle montage
- SMD diodeladder + interessante layout

## Componenten - Kostenberekening

- Zonder PCB, draden
- Weerstanden schatting


## Haalbaarheid

- Goed haalbaar, Componenten zijn beschikbaar
- Met de hand te solderen
- Op-amp schakelingen zijn afzonderlijk testbaar

## Einde

- Zijn er nog vragen?

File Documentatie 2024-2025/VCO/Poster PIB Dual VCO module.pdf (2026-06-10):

# Dual VCO module

# T. Berkhoff & R. Hänninger

# Introduction

# Objectives

# Requirements

# Design

In this project a voltage-controlled oscillator is designed and build to work with other modules in a modular synthesizer. A voltage-controlled oscillator, or VCO, converts a DC input voltage into an AC output voltage. VCO’s are considered to be the heart of any synthesizer, as it mostly makes up the primary signal that can be modulated and outputted as sound.

The main objective of this project is to design a dual VCO-module for a modular synthesizer. With the duality being able to output two independent signals.

In consultation with the stakeholders, a few requirements have been set up:
Functional requirements:
- The ability to output two independent signals.
- Being able to output three different waveforms.
- The input and output voltages must correspond to the 1V / octave standard.
Non-functional requirements:
- The internal electronics must be easily presentable.
- the linearity of the signal must be adjustable. Constraints
- The budget of 50 euros.
- The supply voltage of +/- 12 volts.
- The final size of the module.

# Research

how do you create and design a voltage controlled oscillator used in synthesizers?

# Method

To make a VCO module simple it can be split into three different parts. First a simple oscillator has to be made, then that oscillator has to be modified to make it voltage controlled. And at last, the signal out of the oscillator needs to be modulated before it can be outputted. Using operational amplifiers most of this can be done. With two opamps a sawtooth oscillator can be made; this oscillator can be made voltage controlled by using bipolar junction transistors as resistors. This has the extra benefit of creating a certain frequency at 1V / octave. To modulate the sawtooth, it can be inserted into an inverting amplifier with a gain equal to 1. This inverts the sawtooth. Then the inverted sawtooth can be inserted into a comparator that makes a square wave. Any of these three signals can be tapped and buffered to send to the output of the module. This is visualised in the diagram.

On the left is the PCB design shown in altium, on the right is the board after all of its components have been soldered. The size of the board is chosen according to the eurorack standard, so it can be easily implanted into the casing of the synthesizer. The QR-code contains information about the electronical schematics.

# Results

The dual VCO module is operational. It’s two independent channels can be switched from signal, octave layers and finetuned. Shown in the picture is a computer drawing of the synthesizer wich will house the module.

# Conclusion

Although the end product has been made, the road to that point was not easy. The PCB design contained a couple of routing errors, resulting in some external routes that had to be added. Also, some resistors had to be changed to a higher value to limit current flow in the board. But all the (non) functional requirements have been met.

## Contact & acknowledgements

## Department of electrical

engineering - Windesheim.

## Main client: M. Winkelman email: m.winkelman@windesheim.nl Supporting client R. Rosing email: r.rosing@windesheim.nl Author: Thijn Berkhoff Email: thijn.berkhoff@windehseim.nl Student number: 1198746 Author: Ralph Hänninger Email: ralph.hanninger@windesheim.nl Student number: 1197535

A big thanks to all the other groups from Pulse Soundworks TM that were able to make this project happen.

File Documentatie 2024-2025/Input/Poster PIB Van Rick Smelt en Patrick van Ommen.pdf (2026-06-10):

# Requirements

Functional requirements for both inputs: When a new key is pressed, the previous tone stops and the new tone begins.
A gate signal must be sent whenever a key on the keyboard is pressed or released. This signal is 0V when off and 3.3V when on.
Functional requirements for Analog input:
A minimum of 1 octave of keys, with the ability to play 4 octaves.
An analog signal for pitch.
1 octave should have a range of 1 volt.
Functional requirements for digital input:
The incoming byte from the MIDI keyboard is read, and the corresponding pitch is sent.
The MIDI input must comply with the NEN-EN-INC 63035 protocol for the most part.
Non-functional requirements for both inputs: No velocity sensitivity.
A maximum cost of 50 euro.
The module must be compatible with other modules within the synthesizer.
It must be safe and easy to use.

# PIB Synthesizer

# Analog & Digital Inputs

Figure 1
figure 2

# Conclusion

Figure 3a

The project consisted of several components, including an Elektor article, a poster, and a personal PCB design. Although the underlined requirements in the requirements list were not fulfilled, all other requirements were successfully met and thoroughly tested. Finally, the following questions were addressed: What voltages should be used to send a stable signal to the oscillator, sequencer, and ADSR module?

1.

A DAC voltage between 1 and 3 volts is sent, along with a gate signal of 3.3 volts. 2.What does the analog signal look like, and how is it processed?
The analog signal ranges between 1 and 3 volts, determined by the pressed button. Simultaneously, a gate signal is sent: 3.3 volts when high and 0 volts when low.
3.What does the digital signal look like, and how is it processed?
The MIDI signal contains three incoming bytes: the first byte represents the channel, the second byte specifies the key pressed, and the third byte indicates touch sensitivity (gate).

# Introduction

This project involves the creation of a 25-key keyboard (2 octaves) with added functionality to read inputs from an external MIDI keyboard. Inputs from both keyboards are processed by a microcontroller, which translates key presses into corresponding voltage signals sent to the VCO module to control pitch. Each key press also generates a Gate signal, triggering the ADSR module to define the sound's envelope.

# Objective

The analog input has the following objectives assigned to it: to develop a functional keyboard with a minimum range of one octave, capable of producing the sound of up to four octaves. The digital input also has objectives: to decode a MIDI signal from a MIDI keyboard, as provided by the client.

Figure 3b
Department of Electrical Engineering Main client: R. Rosing Main client email: r.rosing@windesheim.nl Supporting client: M. Winkelman Supporting client email: m.winkelman@windesheim.nl; supply; Thijn Berkhof and Ralph Hänninger: VCO Ruben Boeve: LFO; Author: Rick Smelt Email: Rick.Smelt@windesheim.nl; Author: Patrick van Ommen Email: Patrick.van.Ommen@windesheim.nl

School: Windesheim University of Applied Sciences

Big Thanks to the other groups with whom the synthesizer was made. Ingmar Kosmeijer and Hidde Huysman: ADSR and Mixer Jeroen Middel and Matthijs Vos: power amplifier and power Jens Kuizenga and Diémo Rijsdijk: Filter
Roelof Zijda and Reinout Strating: Sequencer

# Hardware

The custom PCB (figure 2) was designed in Altium, featuring the AVR128DB48 microcontroller at its core, which controls all functionalities within the program. A standard circuit has been integrated for receiving MIDI messages, ensuring essential connectivity. Additionally, a row of pin headers has been included for interfacing with the analog keyboard. To optimize power stability, strategically placed decoupling capacitors have been used. The analog keyboard (shown in Figures 3a and 3b) was a pre-existing keyboard. A PCB already connected to the keys was utilized, along with the keys themselves. These components were integrated into the new housing and connected accordingly.

The built-in keyboard checks the status of each key using polling. When a key is pressed, a 10-bit DAC (Digital-to-Analog Converter) is triggered to produce a specific voltage on an output pin. At the same time, a gate signal is sent to indicate that a key has been pressed.
Meanwhile, for the MIDI
keyboard, two bytes are read:
the first byte contains pitch information, and the second byte represents the gate signal. Based on this data, the 10-bit DAC generates the
corresponding voltage, and a gate signal is sent.

# Software

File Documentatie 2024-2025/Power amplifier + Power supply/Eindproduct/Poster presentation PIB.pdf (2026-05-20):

AMPLIFIER CLASS | EFFICIENCY | SOUND QUALITY | DISTORTION | COMPLEXITY
Class A | Low (20%-30%) | Very High | Very Low | Low
Class B | Medium (60%-80%) | Medium | High | Medium
Class AB | Medium (40%-60%) | High | Low | Medium to High
Class D | Very High (90%-95%) | Low/Verry High* | Medium/Low* | Low/Very High*

Name: Matthijs Vos
Student number: s1200598
Email: matthijs.vos@windesheim.nl

Name: Jeroen Middel
Student number: s1197965
Email: jeroen.middel@windesheim.nl


Big thanks to the other groups with whom the synthesizer was made. Ingmar Kosmeije and Hidde Huysman: ADSR and Mixer
Rick Smelt and Patrick van Ommen: Analog and Digital Input
Jens Kuizenga and Diémo Rijsdijk: Filter
Roelof Zijda and Reinout Strating: Sequencer
Thijn Berkhof and Ralph Hänninger: VCO
Ruben Boeve: LFO

School: Windesheim University of Applied Sciences Zwolle
Department of Electrical Engineering
Main client: R. Rosing
Main client email: r.rosing@windesheim.nl Supporting client: M. Winkelman
Supporting client email: m.winkelman@windesheim.nl

# PIB Project Synthesizer

# Power amplifier

# Made by Jeroen Middel & Matthijs Vos

# Pulse Soundwork commissioned by Windesheim University of Applied Sciences

# Introduction

Research | Conclusion

# Design

In this project the power supply and power amplifier for a modular synthesizer were made. The synthesizer is divided into different modules and across different groups of students within the electrical engineering course. Together this makes a working synthesizer for the project ingenieursbureau.

To make a Power amplifier, a couple research questions were made:

How do you design a (semi-) modular Power amplifier and Power supply for a Synthesizer, with symmetrical and asymmetrical Voltages, and delivers clean audio?

What kind of power amplifier is the most suitable for audio? What kind of current protection is needed?
How do you design a symmetrical power supply and a asymmetrical power supply that can deliver multiple voltages, using an outlet?

REQUIREMENT FOR THE POWER AMPLIFIER

The power amplifier must be able to amplify enough for an external speaker of 8 ohm.
The power amplifier must be able to amplify enough for an external speaker of 8 ohm.
The modules in front of the amplifier must be protected.
The user must be able to adjust the volume.
The amplifier must not become too hot. (passive, active) Maximum distortion. (1% harmonic)

To safely use this module and the speakers, it is essential to filter out the DC component. This is done by the High-pass filter at the input of the module. After that, the signal needs to be buffered, before it is used to control to volume with a potentiometer. After the potentiometer comes the Power Amplifier, with class-AB the amplifier usually exists of 3 stages: the Voltage Amplifier, the Driver and the Output stage. After the output stage there is a resistor in series with a capacitor for a more stable signal. After that is a switch to control the output of the power amplifier: Speaker or Headphones. This module has a total gain of around 3,2; and is powered with the unstable rectified power from the power supply.

*The sound quality, distortion, and complexity depend greatly on what kind of class D amplifier you make, whether it is a simple old-school one or a very complex modern one.

In this project, a class AB audio amplifier was chosen. This decision was made after weighing the pros and cons of the most common audio amplifier classes. Class AB offers a good balance of efficiency, sound quality, and complexity. Therefore, this class of audio amplifier fits very well into this project.

From the PIB project, an electronic article, a poster, and a functional PCB have been developed. The PCB meets all specified requirements. The following questions were also addressed in the project:
What kind of power amplifier is the most suitable for audio?
- Our research has shown that Class AB is the most suitable type for the synthesizer.
What type of protection is required in the Power amplifier?
- A buffer has been added to the amplifier

'
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

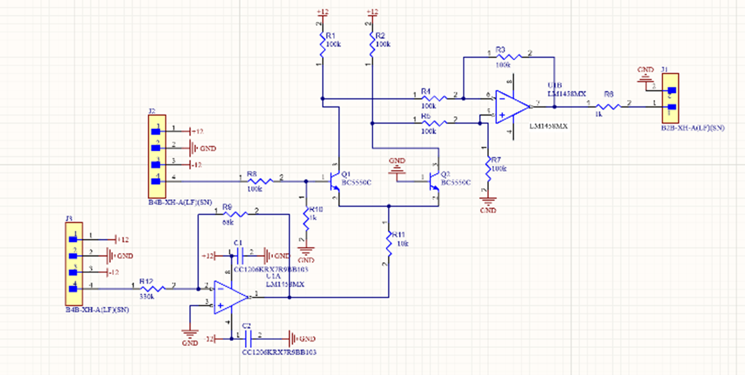
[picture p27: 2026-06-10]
Documentatie 2024-2025/ADSR+MIXER+VCA/Schematics en pcb/VCA Schematic.png

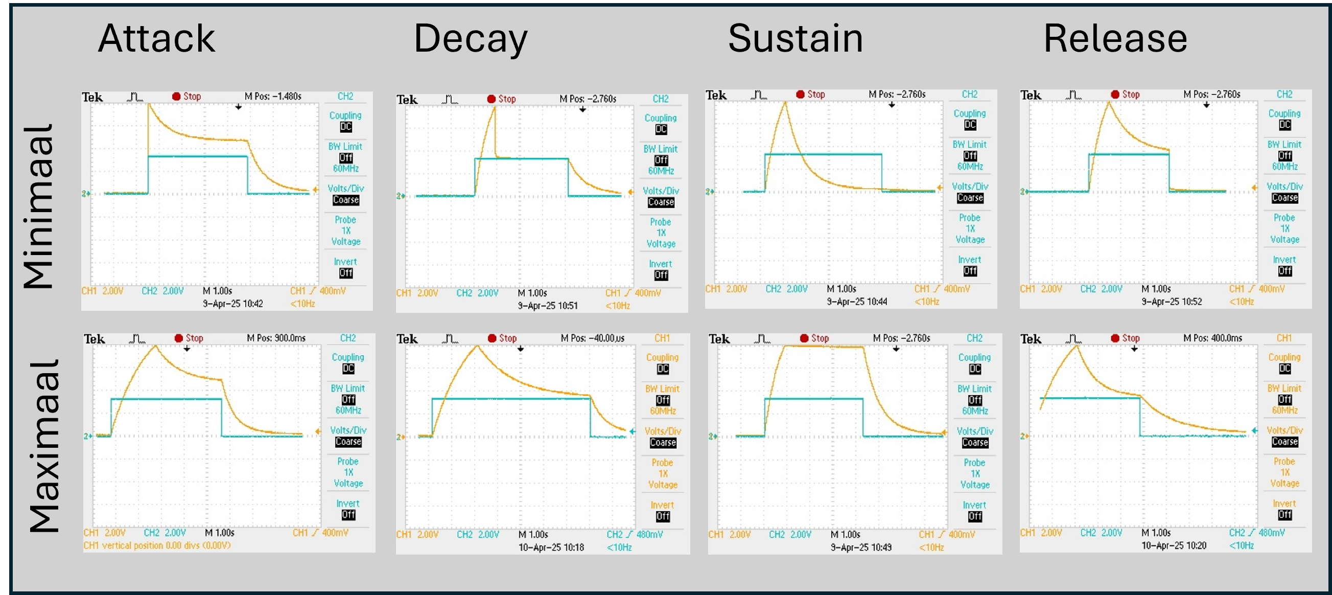
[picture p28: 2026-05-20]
Documentatie 2024-2025/ADSR+MIXER+VCA/Afbeeldingen metingen specs/overzicht parameters adsr.png

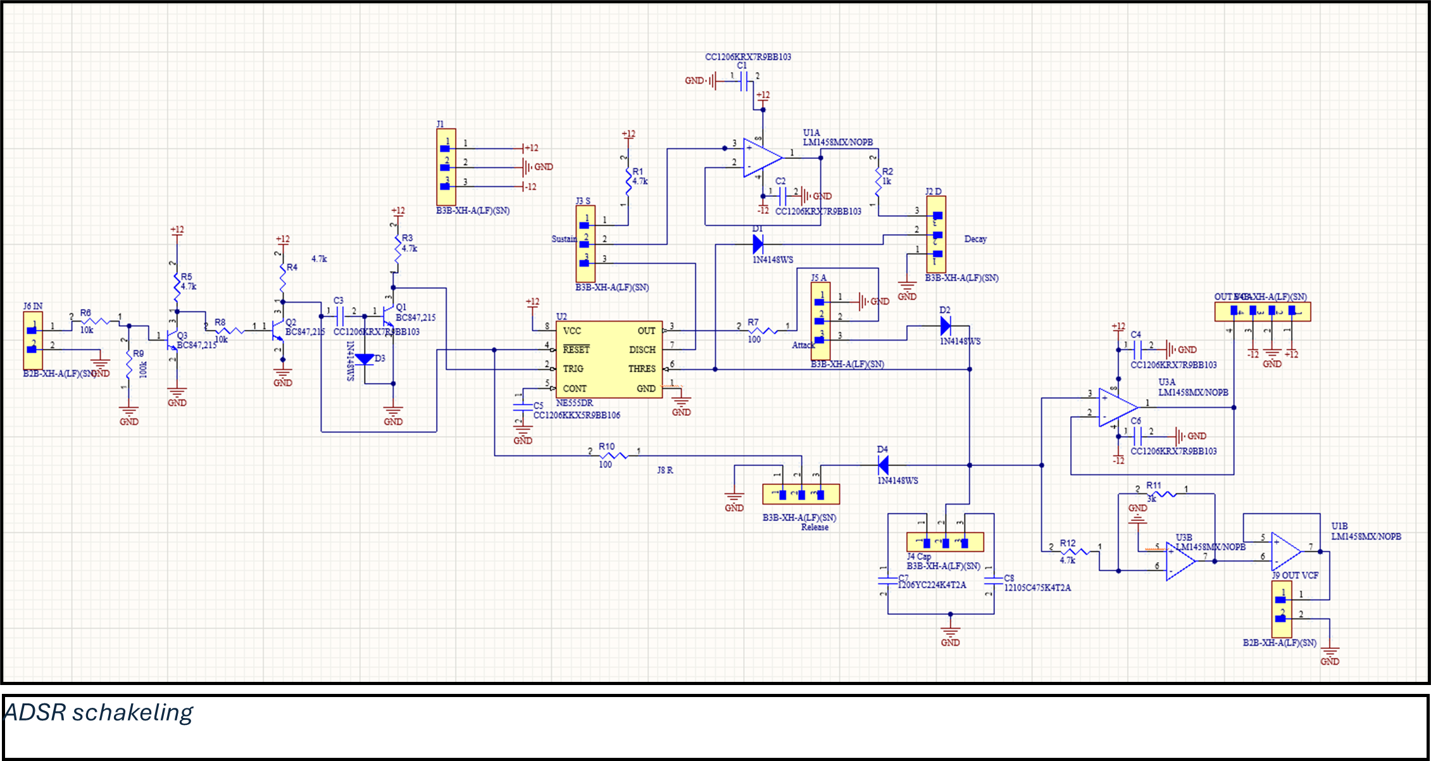
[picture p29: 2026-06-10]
Documentatie 2024-2025/ADSR+MIXER+VCA/Schematics en pcb/ADSR Schematic.png

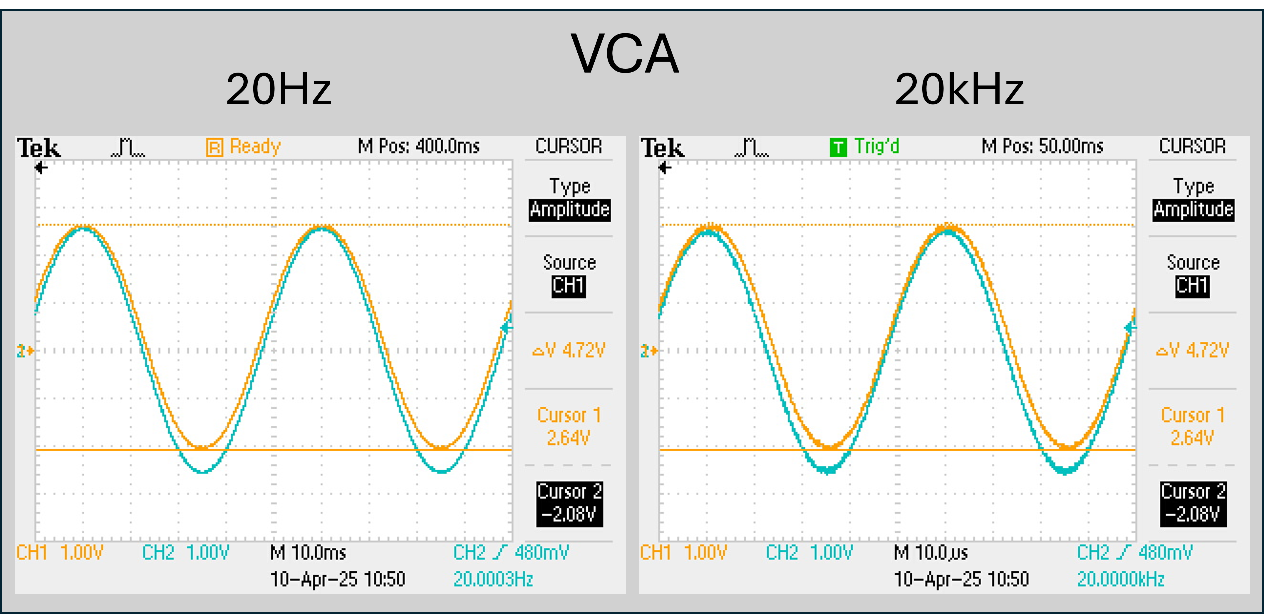
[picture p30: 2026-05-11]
Documentatie 2024-2025/ADSR+MIXER+VCA/Afbeeldingen metingen specs/VCA 20hz vs 20kHz.png

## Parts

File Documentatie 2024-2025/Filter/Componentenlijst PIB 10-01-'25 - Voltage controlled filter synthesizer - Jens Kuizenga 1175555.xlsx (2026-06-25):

Component | Montage type | Webwinkel | Aantal | Prijs per stuk | Prijs totaal | Opmerking | url
Potmeter 10k mono | THT | Mouser | 1 | 1.19 | 1.19 | Interface component | https://nl.mouser.com/ProductDetail/Bourns/PDB181-E420K-103A2?qs=HVbQlW5zcXWC17G23A3FYg%3D%3D
Potmeter 10k stereo | THT | Mouser | 1 | 2.22 | 2.22 | Interface component | https://nl.mouser.com/ProductDetail/Bourns/PDB182-E425K-103A?qs=gZXFycFWdAMnVbjl2yp9gQ%3D%3D
Audio jack in - output | THT | Mouser | 5 | 1.34 | 6.7 | Interface component | https://nl.mouser.com/ProductDetail/Amphenol-Audio/ACJS-MV35-3?qs=t8%2F5FiDdxGZU3J8GgPv5Yw%3D%3D
TL072H Op Amp | SMD | Mouser | 4 | 0.214 | 0.856 |  | https://nl.mouser.com/ProductDetail/Texas-Instruments/TL072HIDR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
BAV 99 | SMD | Mouser | 3 | 0.093 | 0.279 |  | https://nl.mouser.com/ProductDetail/Diotec-Semiconductor/BAV99?qs=OlC7AqGiEDlmuhCokzYmxg%3D%3D
Condensator 1uF | THT | Farnell | 10 | 0.233 | 2.33 | Minimale afname = 10stuks | https://nl.farnell.com/kemet/r82dc4100aa60k/cap-1-f-63v-10-pet-radial/dp/2763215
Condensator 1nF | THT | Farnell | 10 | 0.151 | 1.51 | Minimale afname = 10stuks | https://nl.farnell.com/kemet/r82ec1100dq50j/cap-1000pf-100v-5-pet-radial/dp/2429343
1N4148 | SMD | Werkplaats | 3 | 0.093 | 0.279 | Prijs van Mouser
Weerstand 330Ω | SMD | Werkplaats | 1
Weerstand 1kΩ | SMD | Werkplaats | 1
Weerstand 2,2kΩ | SMD | Werkplaats | 2 |  |  | 2k in ontwerp
Weerstand 10kΩ | SMD | Werkplaats | 3
Weerstand 12kΩ | SMD | Werkplaats | 1
Weerstand 18kΩ | SMD | Werkplaats | 1
Weerstand 100kΩ | SMD | Werkplaats | 9
Weerstand 220kΩ | SMD | Werkplaats | 1 |  |  | 200k in ontwerp
JST connector | THT | Mouser | 8 | 0.623 | 4.984 | Voor kabel -> PCB aansluiting interface componenten | https://nl.mouser.com/ProductDetail/JST-Commercial/BM03B-PASS-TFLFSN?qs=QpmGXVUTftG0jznDmAO4hg%3D%3D
Condensator 100nF | SMD | Werkplaats | 8
JST connector (Insert) | x | Mouser | 8 | €0.149 | €1.19 | Gaat in PCB connector | https://nl.mouser.com/ProductDetail/JST-Commercial/PAP-03V-S
JST connector (Pins) | Crimp | Mouser | 24 | €0.028 | €0.67 |  | https://nl.mouser.com/ProductDetail/JST-Commercial/SPHD-001T-P0.5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
 |  |  |  |  | Totaal | Prijs weerstanden en kabels/draden nog niet inbegrepen
 |  |  |  |  | 22.212

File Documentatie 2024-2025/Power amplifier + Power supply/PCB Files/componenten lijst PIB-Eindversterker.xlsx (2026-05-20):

componenten |  |  | hoeveelheid nodig | prijs (per stuk) | Prijs (totaal) | Linkje
IRF540NPBF | mosfet | Mouser | 1 | 1 | 1 | https://nl.mouser.com/ProductDetail/Infineon-Technologies/IRF540NPBF?qs=9%252BKlkBgLFf36us%252Bg5kwffA%3D%3D
IRF9540NPBF | mosfet | Mouser | 1 | 1.26 | 1.26 | https://nl.mouser.com/ProductDetail/Infineon-Technologies/IRF9540NPBF?qs=9%252BKlkBgLFf0vnuA8mxUPtw%3D%3D
TL072IP | opamp | Mouser | 1 | 0.79 | 0.79 | https://nl.mouser.com/ProductDetail/Texas-Instruments/TL072IP?qs=5BZzbFV4k2v7IBrcArRPQw%3D%3D
BD139 | BJT | Mouser | 1 | 0.4 | 0.4 | https://nl.mouser.com/ProductDetail/STMicroelectronics/BD139?qs=ljbEvF4DwOPW%2FLxHSWYMMA%3D%3D
BD140 | BJT | Mouser | 1 | 0.43 | 0.43 | https://nl.mouser.com/ProductDetail/STMicroelectronics/BD140?qs=ljbEvF4DwOOQh3TFtIzRQQ%3D%3D
Potmeter 1K | potmeter | school | 2 | 1.09 | 2.18 | https://nl.farnell.com/amphenol-piher-sensorscontrols/pt15nv02-102a2020-s/trimmer-1k-0-25w-1turn/dp/4006855
Potmeter 20K | potmeter | Mouser | 1 | 1.48 | 1.48 | https://nl.mouser.com/ProductDetail/Bourns/PTA6043-2015DPA103?qs=U%2FacTlguYxapXI1x524WqA%3D%3D
Slider | Slider | Farnell | 1 | 0.54 | 0.54 | https://nl.farnell.com/cliff-electronic-components/cp3261/slider-knob-cs1b-4mm-b-blk/dp/3762253
701W-15/21 | IEC-320 C-14 connector | mouser | 1 | 0.679 | 0.679 | https://nl.mouser.com/ProductDetail/Qualtek/701W-15-21?qs=hzq9O0YpnZsZdOnffw4akQ%3D%3D
Elco 4700uF | condensator | school | 4 | 1.99 | 7.96 | https://nl.mouser.com/ProductDetail/Cornell-Dubilier-CDE/478CKE025MQV
foliecondensator | condensator | Mouser | 1 | 0.8 | 0.8 | https://nl.mouser.com/ProductDetail/WIMA/MKS4C034702C00JSSD?qs=2G4irm%2FqADzbKabShRSisw%3D%3D
6,3mm audio jack | audio jack | Mouser | 1 | 2.63 | 2.63 | https://nl.mouser.com/ProductDetail/Same-Sky/SJ-63053A?qs=hWgE7mdIu5Q5ZZx8mXk5JQ%3D%3D
KBU8B-E4/51 | bridge rectifier | Mouser | 1 | 3.3 | 3.3 | https://nl.mouser.com/ProductDetail/Vishay-General-Semiconductor/KBU8B-E4-51?qs=NyKJzQ80QAygqwzWBhqaRw%3D%3D
3,5mm audio jack | audio jack | Mouser | 2 | 1.29 | 2.58 | https://nl.mouser.com/ProductDetail/Amphenol-Audio/ACJS-MV35-3?qs=t8%2F5FiDdxGZU3J8GgPv5Yw%3D%3D
Elco 330uF | condensator | Mouser | 2 | 0.8 | 1.6 | https://nl.mouser.com/ProductDetail/EPCOS-TDK/B41858C6337M000?qs=nadT%2FcWsIvA1sjqdj3l0sA%3D%3D
330nF condensatoren | condensator | school | 1 | 0.25 | 0.25 | DriveXChance prijs lijst
220nF condensatoren | condensator | school | 3 | 0.25 | 0.75 | DriveXChance prijs lijst
100nF condensator | condensator | school | 9 | 0.25 | 2.25 | DriveXChance prijs lijst
1 Ohm Weerstand | weerstanden | school | 3 | 0.1 | 0.3 | DriveXChance prijs lijst
10 Ohm Weerstand | weerstanden | school | 1 | 0.1 | 0.1 | DriveXChance prijs lijst
22 Ohm Weerstand | weerstanden | school | 1 | 0.1 | 0.1 | DriveXChance prijs lijst
1k Ohm Weerstand | weerstanden | school | 1 | 0.1 | 0.1 | DriveXChance prijs lijst
2k2 Ohm Weerstand | weerstanden | school | 3 | 0.1 | 0.3 | DriveXChance prijs lijst
68k Ohm Weerstanden | weerstanden | school | 1 | 0.1 | 0.1 | DriveXChance prijs lijst
pin header | haeder | school | 2 | 0.5 | 1 | DriveXChance prijs lijst
power switch | switch | school | 1 | 1.43 | 1.43 | https://nl.farnell.com/te-connectivity/1634202-1/switch-rocker-spst-black/dp/1822036
audio switch | switch | Mouser | 1 | 2.66 | 2.66 | https://nl.mouser.com/ProductDetail/E-Switch/200MSP1T1B1M2QE?qs=f57gQzlyLirEcN5qw3HMNA%3D%3D
L7912ACV | voltage regulator | school | 1 | 1 | 1 | DriveXChance prijs lijst
L7812CV | voltage regulator | school | 1 | 1 | 1 | DriveXChance prijs lijst
L7805CV | voltage regulator | school | 1 | 1 | 1 | DriveXChance prijs lijst
UA78M33CKCSE3 | voltage regulator | school | 1 | 1 | 1 | DriveXChance prijs lijst
 |  |  |  | Totaal Prijs: | 40.969

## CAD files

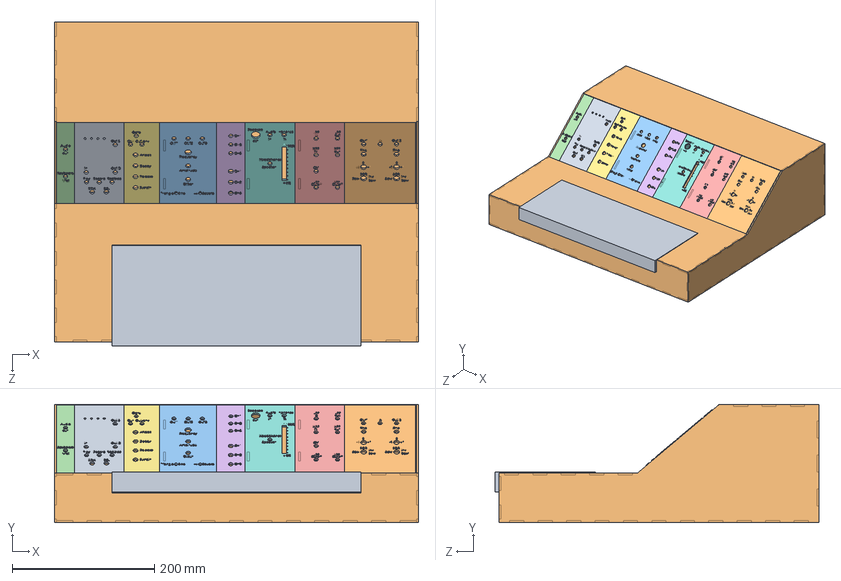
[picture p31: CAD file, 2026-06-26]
Documentatie 2024-2025/Sequencer/Ombouw_Synth/assembly syntesyzer geheel.SLDASM
512.0 x 166.4 x 455.4 mm
Kast synthesizer
sequencer frontplate
eindversterker frontplate
ADSR panel
MIXER panel
filter paneel
input paneel
LFO paneel
Dual VCO interface
keyboard model, alleen toetsen

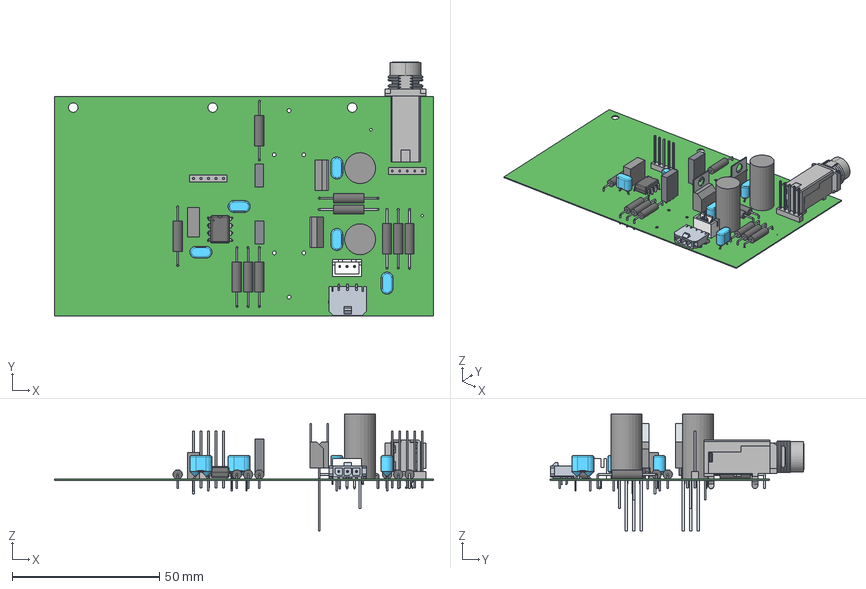
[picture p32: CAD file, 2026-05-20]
Documentatie 2024-2025/Power amplifier + Power supply/PCB Files/PIB Synthesizer Eindversterker.step
128.5 x 86.0 x 39.5 mm
Pins
Marking
JST Logo
Extruded x 26
BODY_P0008A
LEAD_P0008A x 4
LD_LHALF_P0008A x 2
LD_RHALF_P0008A x 2
SimpleBody x 12
Tab x 2
PinsArray x 2
630BT-1
630LS-1
PRT0003-1
630C2-1
630GZ-1
Pin1 x 2
Pin2 x 2
Leads x 6
Murata x 5

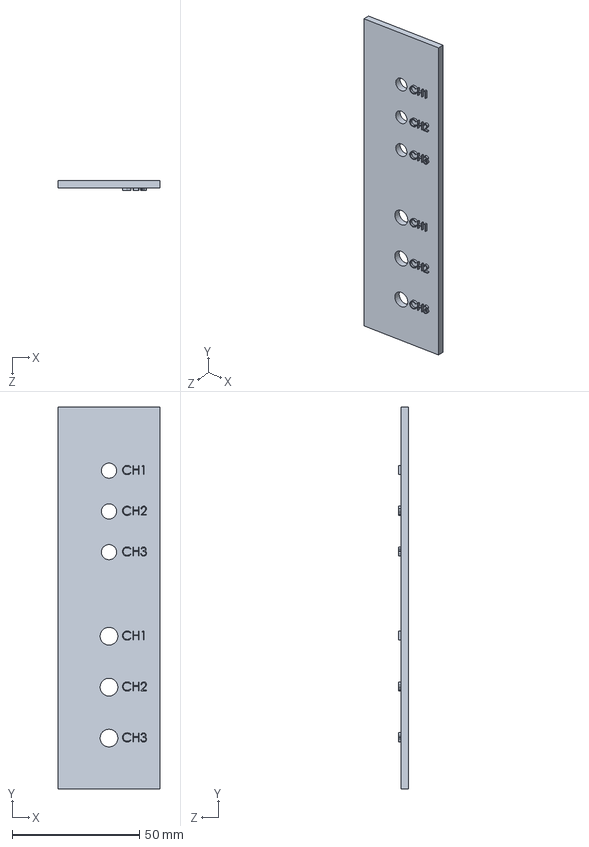
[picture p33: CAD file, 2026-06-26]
Documentatie 2024-2025/Sequencer/Ombouw_Synth/MIXER panel.SLDPRT
40.0 x 150.0 x 4.00 mm

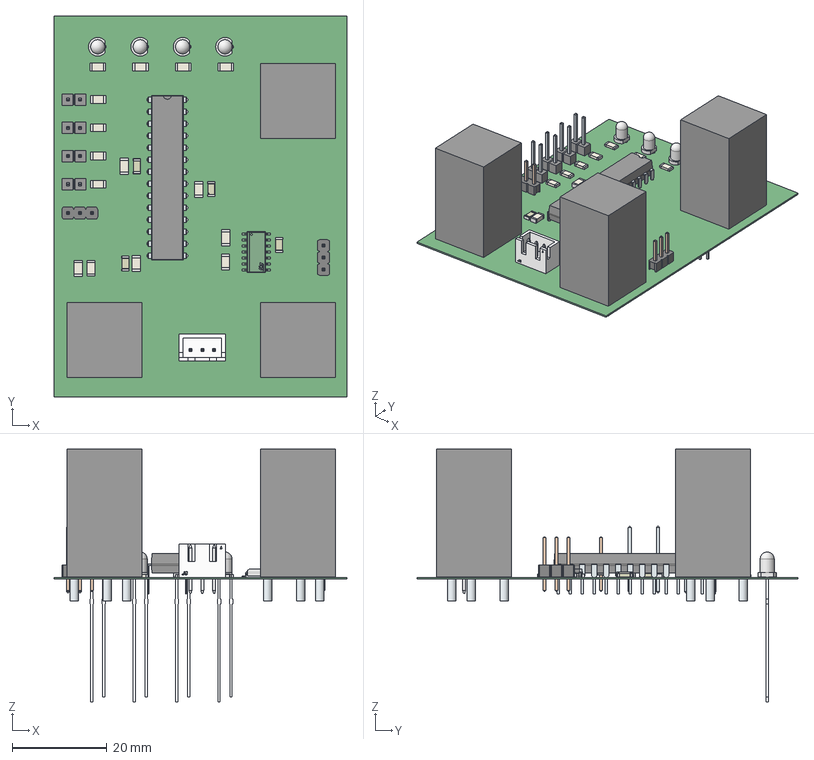
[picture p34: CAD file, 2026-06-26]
Documentatie 2024-2025/Sequencer/Schematics/sequencer pvb v2.step
62.0 x 80.5 x 53.5 mm
Pins
Marking
JST Logo
IC_BODY
circle
IC_LEG x 7
STMicroelectronics
IC_LEG_MIR8 x 7
Extruded x 45
6130xx11121_PIN x 6
Leads x 3
LeadsArray x 4
PinsArrayLR
15103xxx x 4
Cap_KEMET_C1206C472K4RACTU_eec x 12

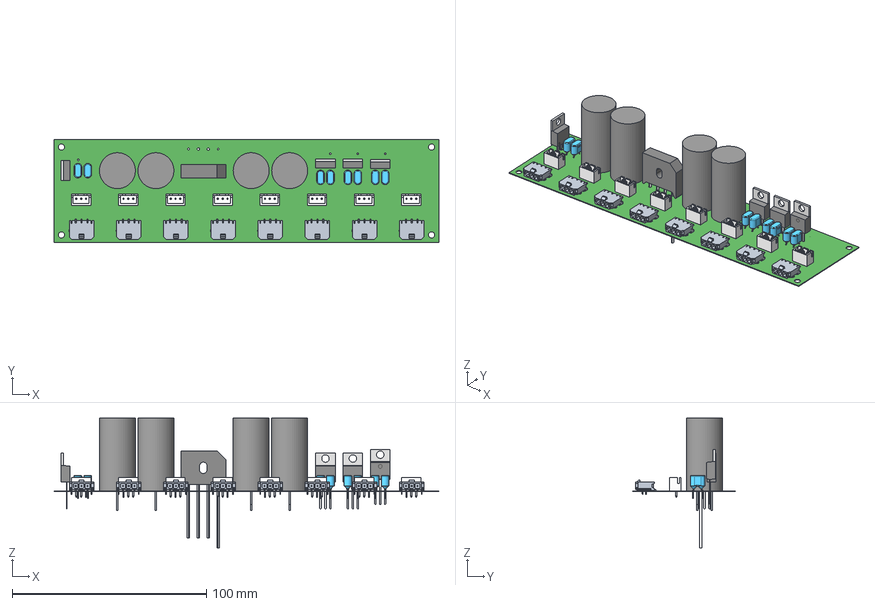
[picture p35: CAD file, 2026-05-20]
Documentatie 2024-2025/Power amplifier + Power supply/PCB Files/PIB Synthesizer Voeding.step
198.1 x 52.8 x 66.9 mm
Pins x 8
Marking x 8
JST Logo x 8
Leads x 8
Murata x 8
T03B_BODY x 3
T03B_LEAD x 9
T03B_HS x 3
BODY-TO-220
LEAD-TO220 x 3
HEATSINK-TO-220
SimpleBody x 4
Pin1 x 4
Pin2 x 4

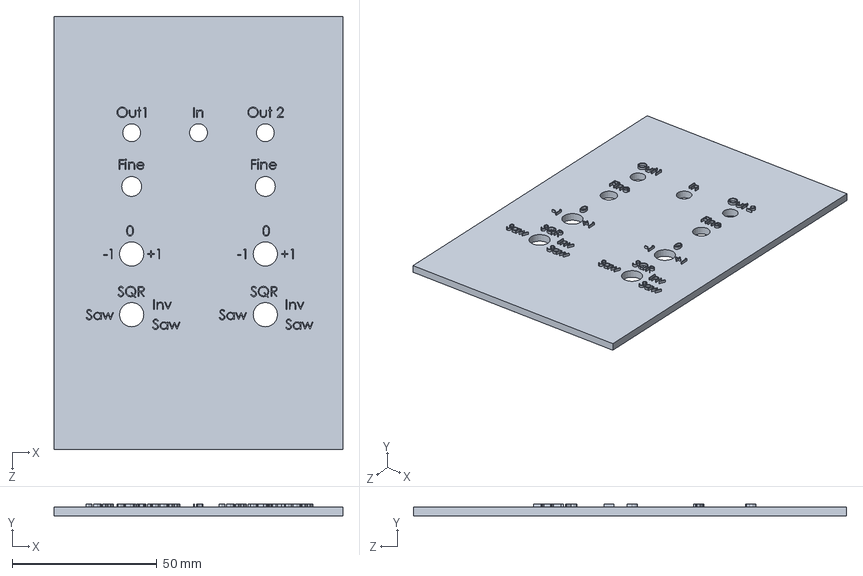
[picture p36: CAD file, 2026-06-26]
Documentatie 2024-2025/Sequencer/Ombouw_Synth/Dual VCO interface.SLDPRT
100.0 x 4.00 x 150.0 mm

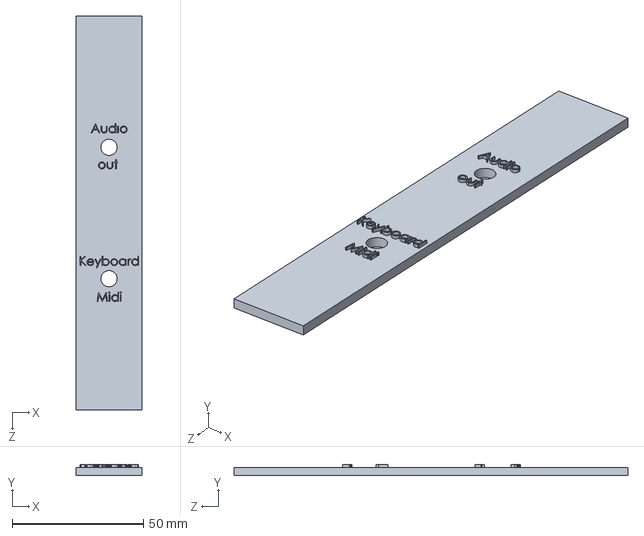
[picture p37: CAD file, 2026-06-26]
Documentatie 2024-2025/Sequencer/Ombouw_Synth/input paneel.SLDPRT
25.0 x 4.00 x 150.0 mm

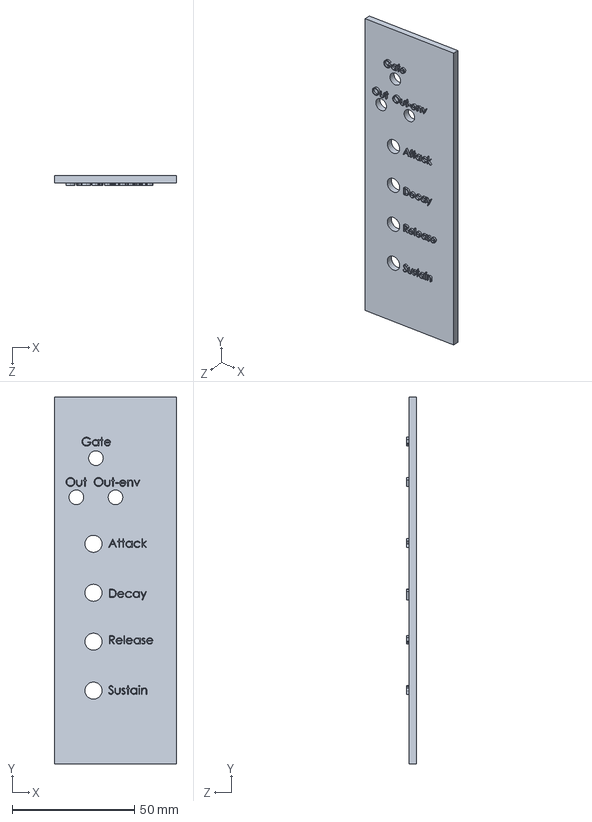
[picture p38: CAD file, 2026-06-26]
Documentatie 2024-2025/Sequencer/Ombouw_Synth/ADSR panel.SLDPRT
50.0 x 150.0 x 4.00 mm

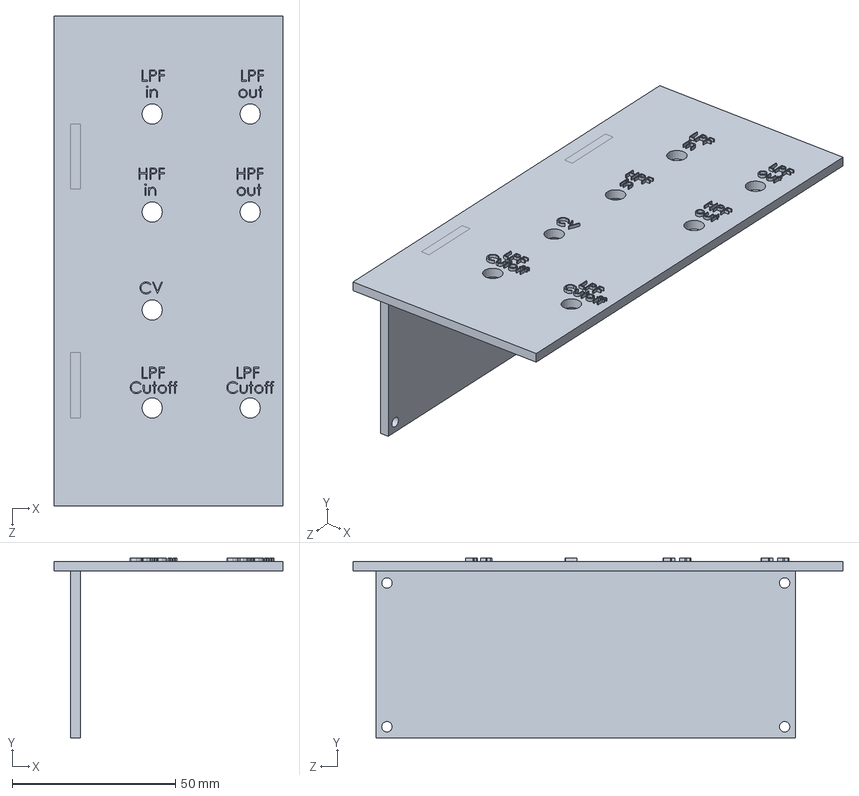
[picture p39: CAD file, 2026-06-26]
Documentatie 2024-2025/Sequencer/Ombouw_Synth/filter paneel.SLDPRT
70.0 x 55.0 x 150.0 mm

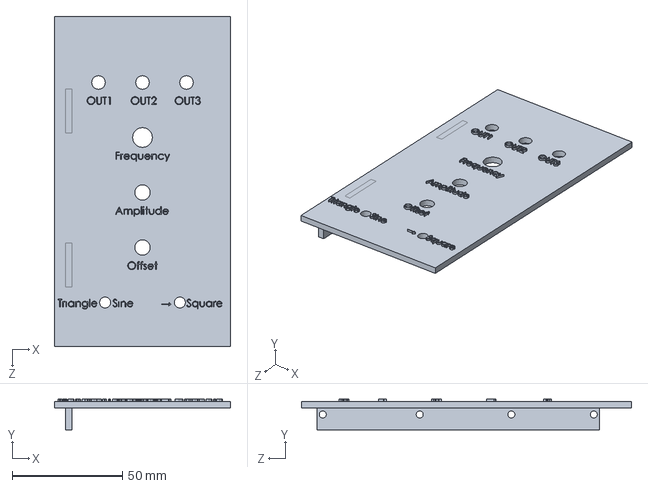
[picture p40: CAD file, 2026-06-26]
Documentatie 2024-2025/Sequencer/Ombouw_Synth/LFO paneel.SLDPRT
80.0 x 14.0 x 150.0 mm

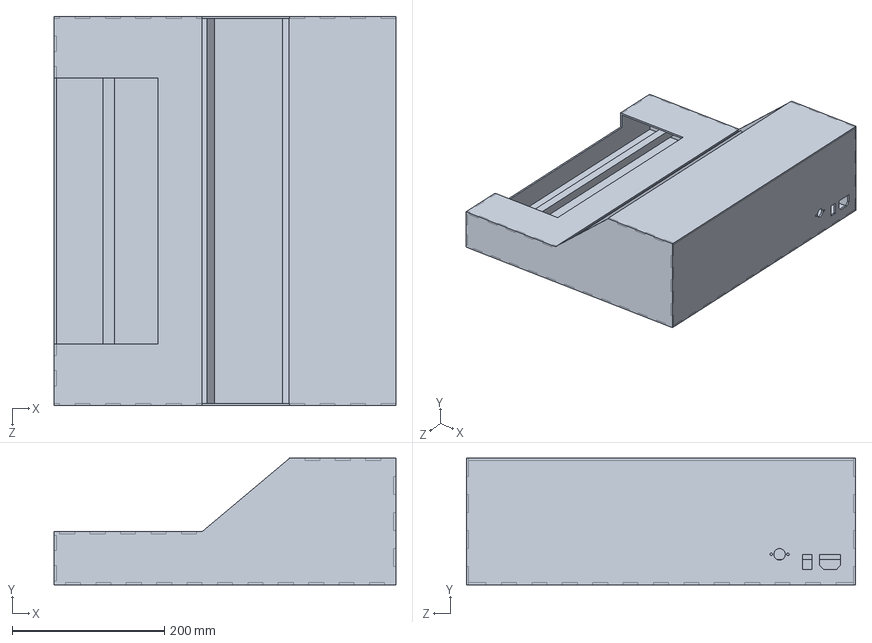
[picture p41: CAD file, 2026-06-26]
Documentatie 2024-2025/Sequencer/Ombouw_Synth/Kast synthesizer.SLDPRT
449.9 x 166.4 x 512.0 mm

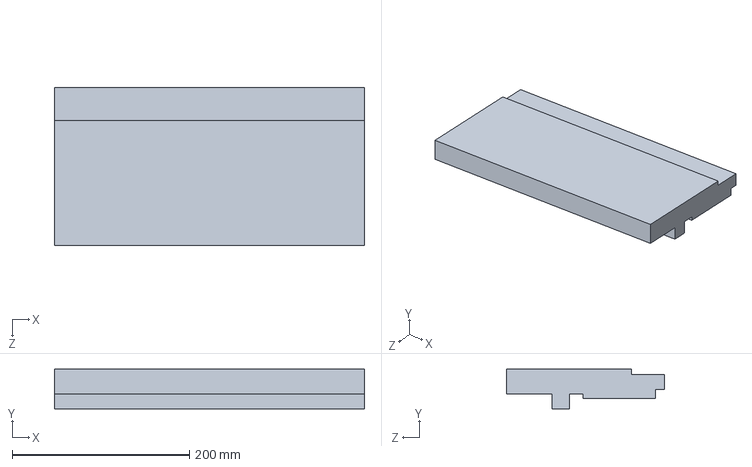
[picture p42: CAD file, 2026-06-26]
Documentatie 2024-2025/Sequencer/Ombouw_Synth/keyboard model, alleen toetsen.SLDPRT
350.0 x 45.0 x 178.0 mm

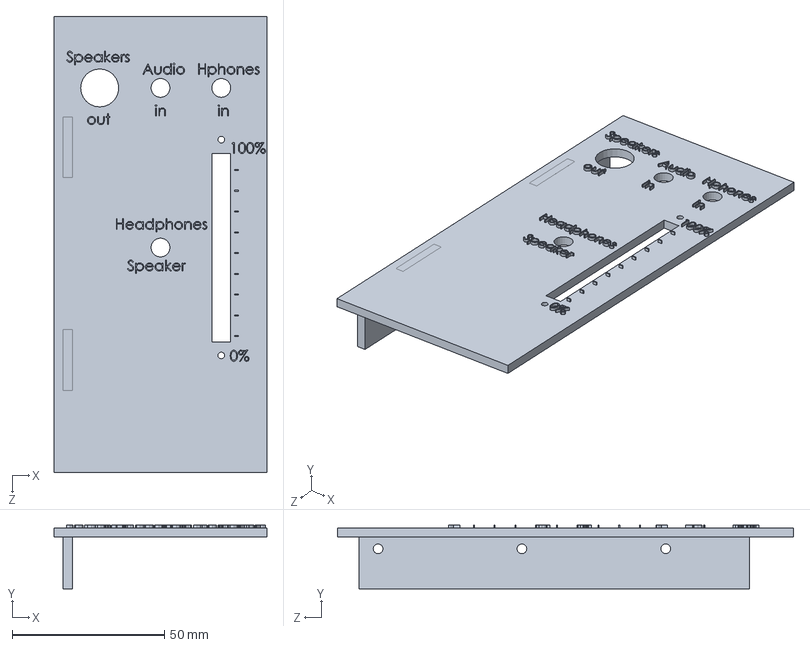
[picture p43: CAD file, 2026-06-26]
Documentatie 2024-2025/Sequencer/Ombouw_Synth/eindversterker frontplate.SLDPRT
70.0 x 21.0 x 150.0 mm

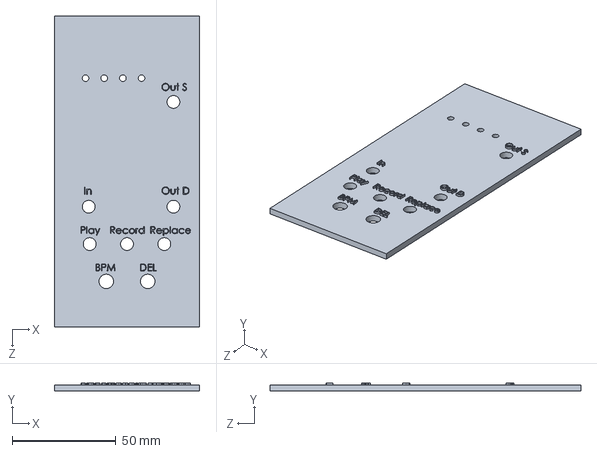
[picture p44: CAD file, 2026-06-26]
Documentatie 2024-2025/Sequencer/Ombouw_Synth/sequencer frontplate.SLDPRT
70.0 x 4.00 x 150.0 mm

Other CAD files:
Documentatie 2024-2025/Sequencer/Ombouw_Synth/Assem1_Mixer.SLDASM
Documentatie 2024-2025/Sequencer/Ombouw_Synth/Assem ADSR.SLDASM
Documentatie 2024-2025/Sequencer/Ombouw_Synth/PIB Synthesizer Eindversterker.SLDASM
Documentatie 2024-2025/Sequencer/Ombouw_Synth/sequencer pcb v2.SLDASM

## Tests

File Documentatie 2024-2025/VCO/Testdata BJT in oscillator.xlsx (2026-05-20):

 |  | Ik heb hier de spanning uitgezet tegen de frequentie van de bc550 transistor in een zaagtand VCO. Met een condensator van 100nF
 |  | U-base | Frequentie
 |  | 0 | 0.05
 |  | 0.5 | 2.5
 |  | 1 | 122
 |  | 1.5 | 230
 |  | 2 | 363
 |  | 2.5 | 480
 |  | 3 | 604
 |  | 3.5 | 713
 |  | 4 | 844
 |  | 4.5 | 950
 |  | 5 | 1076
 |  | 5.5 | 1182
 |  | 6 | 1297
 |  | 6.5 | 1395
 |  | 7 | 1509
 |  | 7.5 | 1606
 |  | 8 | 1706
 |  | 8.5 | 1809
 |  | 9 | 1940
 |  | 9.5 | 1986
 |  | 10 | 2113
 |  | 10.5 | 2139
 |  | 11 | 2165
 |  | 11.5 | 2248
 |  | 12 | 2329
 |  | Nu met een spanningsdeler van 1/25 en een 10nF condensator ipv 100nF
 |  | U-loper | U-base | Frequentie
 |  | 0 | 0 | 0.1
 |  | 0.5 | 0.024 | 0.1
 |  | 1 | 0.047 | 0.11
 |  | 1.5 | 0.073 | 0.11
 |  | 2 | 0.093 | 0.11
 |  | 2.5 | 0.114 | 0.12
 |  | 3 | 0.136 | 0.12
 |  | 3.5 | 0.16 | 0.12
 |  | 4 | 0.19 | 0.12
 |  | 4.5 | 0.21 | 0.12
 |  | 5 | 0.23 | 0.11
 |  | 5.5 | 0.25 | 0.12
 |  | 6 | 0.28 | 0.13
 |  | 6.5 | 0.3 | 0.13
 |  | 7 | 0.32 | 0.14
 |  | 7.5 | 0.35 | 0.2
 |  | 8 | 0.37 | 0.4
 |  | 8.5 | 0.39 | 0.8
 |  | 9 | 0.41 | 1.3
 |  | 9.5 | 0.43 | 3.3
 |  | 10 | 0.45 | 6.6
 |  | 10.5 | 0.48 | 13.3
 |  | 11 | 0.5 | 23.5
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

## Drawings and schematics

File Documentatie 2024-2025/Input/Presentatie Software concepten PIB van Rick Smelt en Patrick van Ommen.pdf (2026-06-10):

# Project synthesizer Concepten

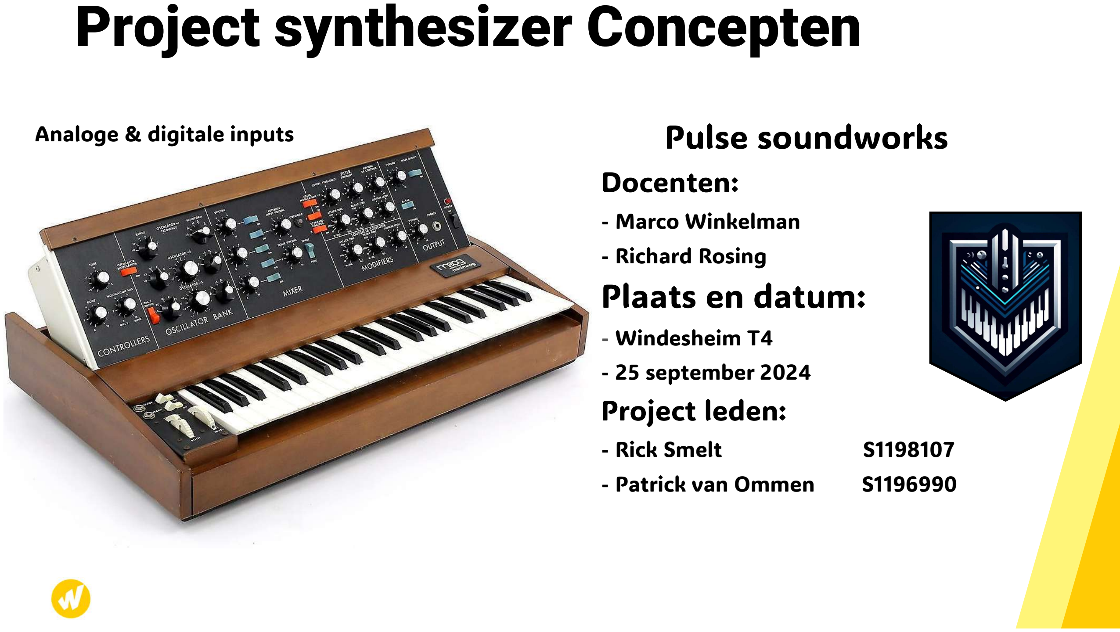
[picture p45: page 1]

# Pulse soundworks

# Docenten:

## - Marco Winkelman - Richard Rosing

# Plaats en datum: - Windesheim T4

## - 25 september 2024

# Project leden:

- Rick Smelt | S1198107
- Patrick van Ommen | S1196990

## Analoge & digitale inputs

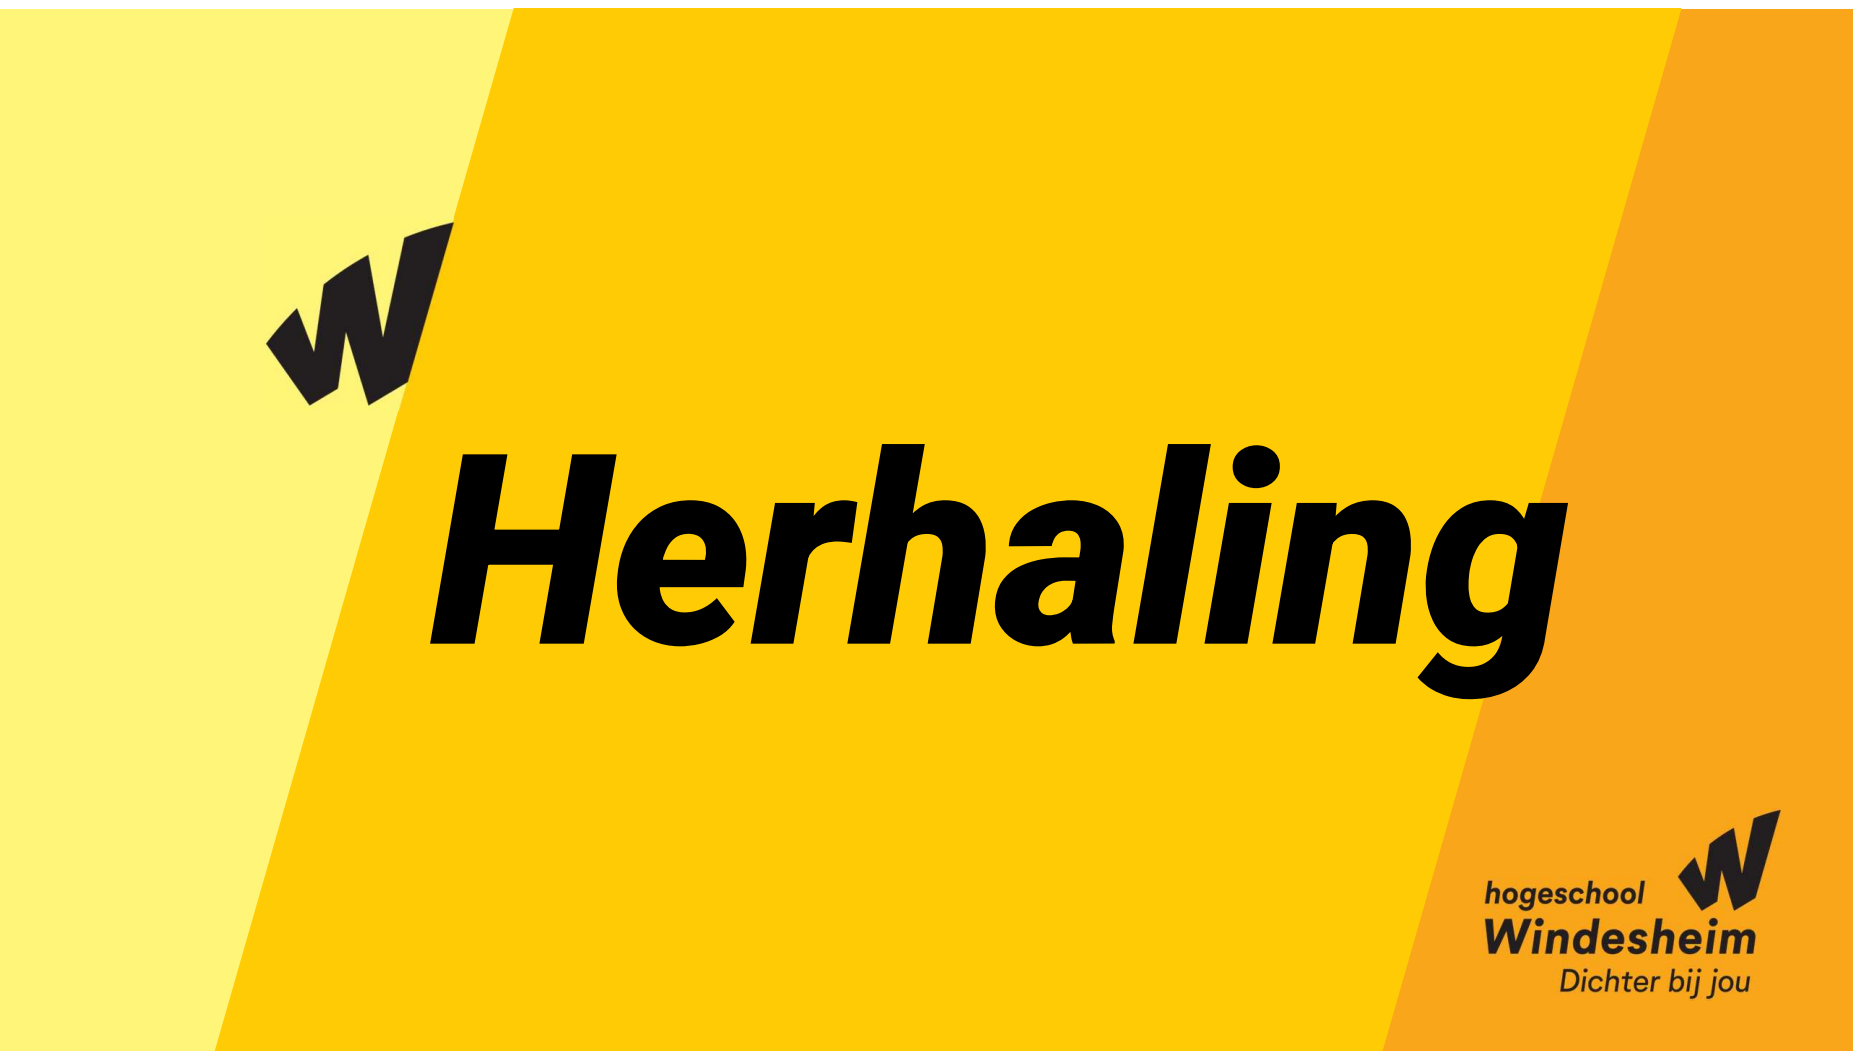
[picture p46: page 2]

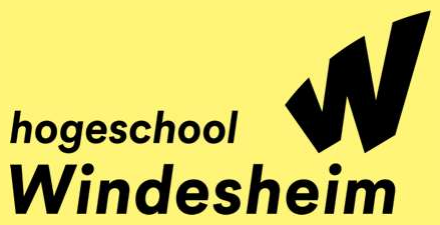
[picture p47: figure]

# wat is de opdracht?

Het ontwerpen en bouwen van een modulaire synthesizer.

## - Er moet een analoge input en een midi input worden gemaakt en deze moet aangesloten

worden.
- Voor de analoge input wordt een keyboard gemaakt. En voor de midi input zal het digitale signaal worden omgezet naar een analoog signaal.
- Uit beide inputs zal een gate signaal komen en een toonhoogte. Deze beide signalen moeten

## naar de volgende modules:

- ADSR- module
- Sequenser
- oscillator

# Achtergronden

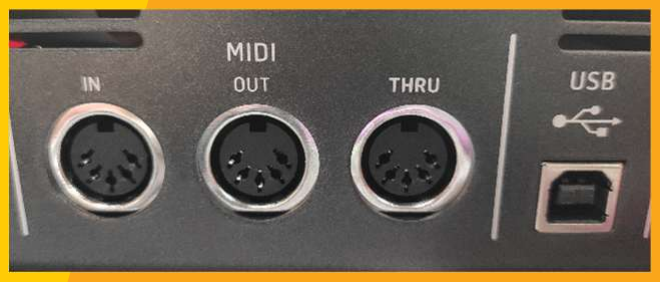
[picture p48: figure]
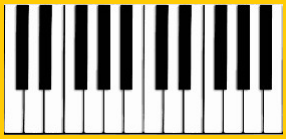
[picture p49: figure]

# Project resultaten

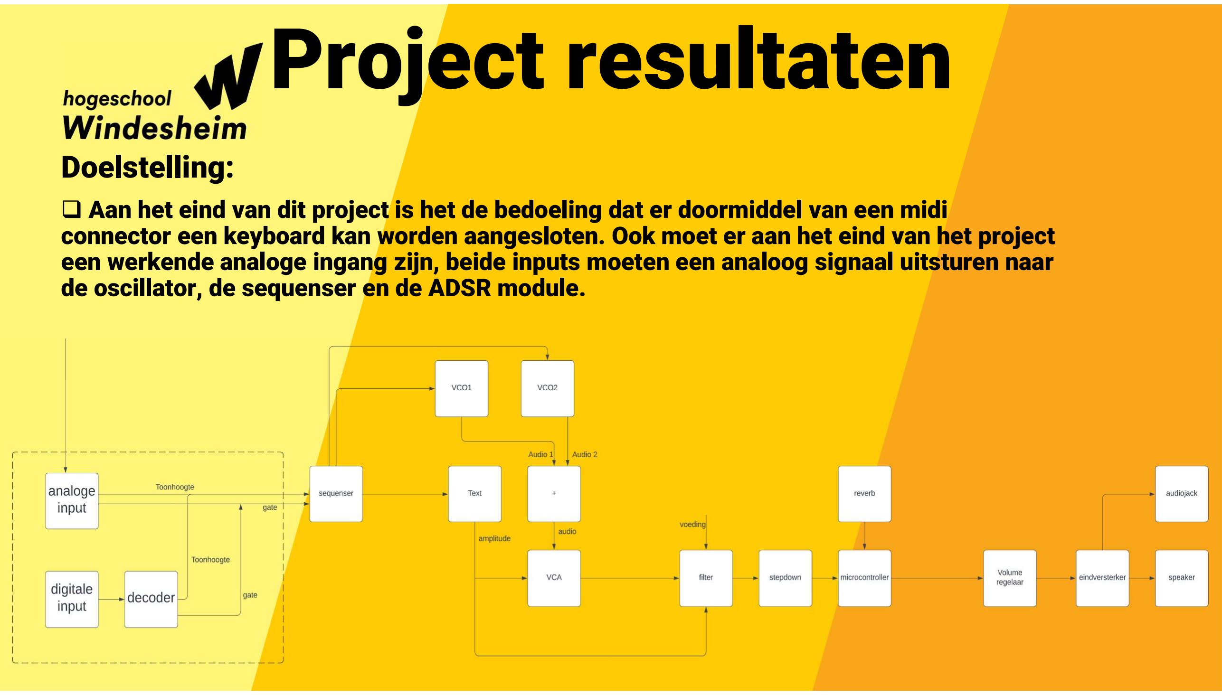
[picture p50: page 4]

# Doelstelling:

## - Aan het eind van dit project is het de bedoeling dat er doormiddel van een midi connector een keyboard kan worden aangesloten. Ook moet er aan het eind van het project een werkende analoge ingang zijn, beide inputs moeten een analoog signaal uitsturen naar

de oscillator, de sequenser en de ADSR module.

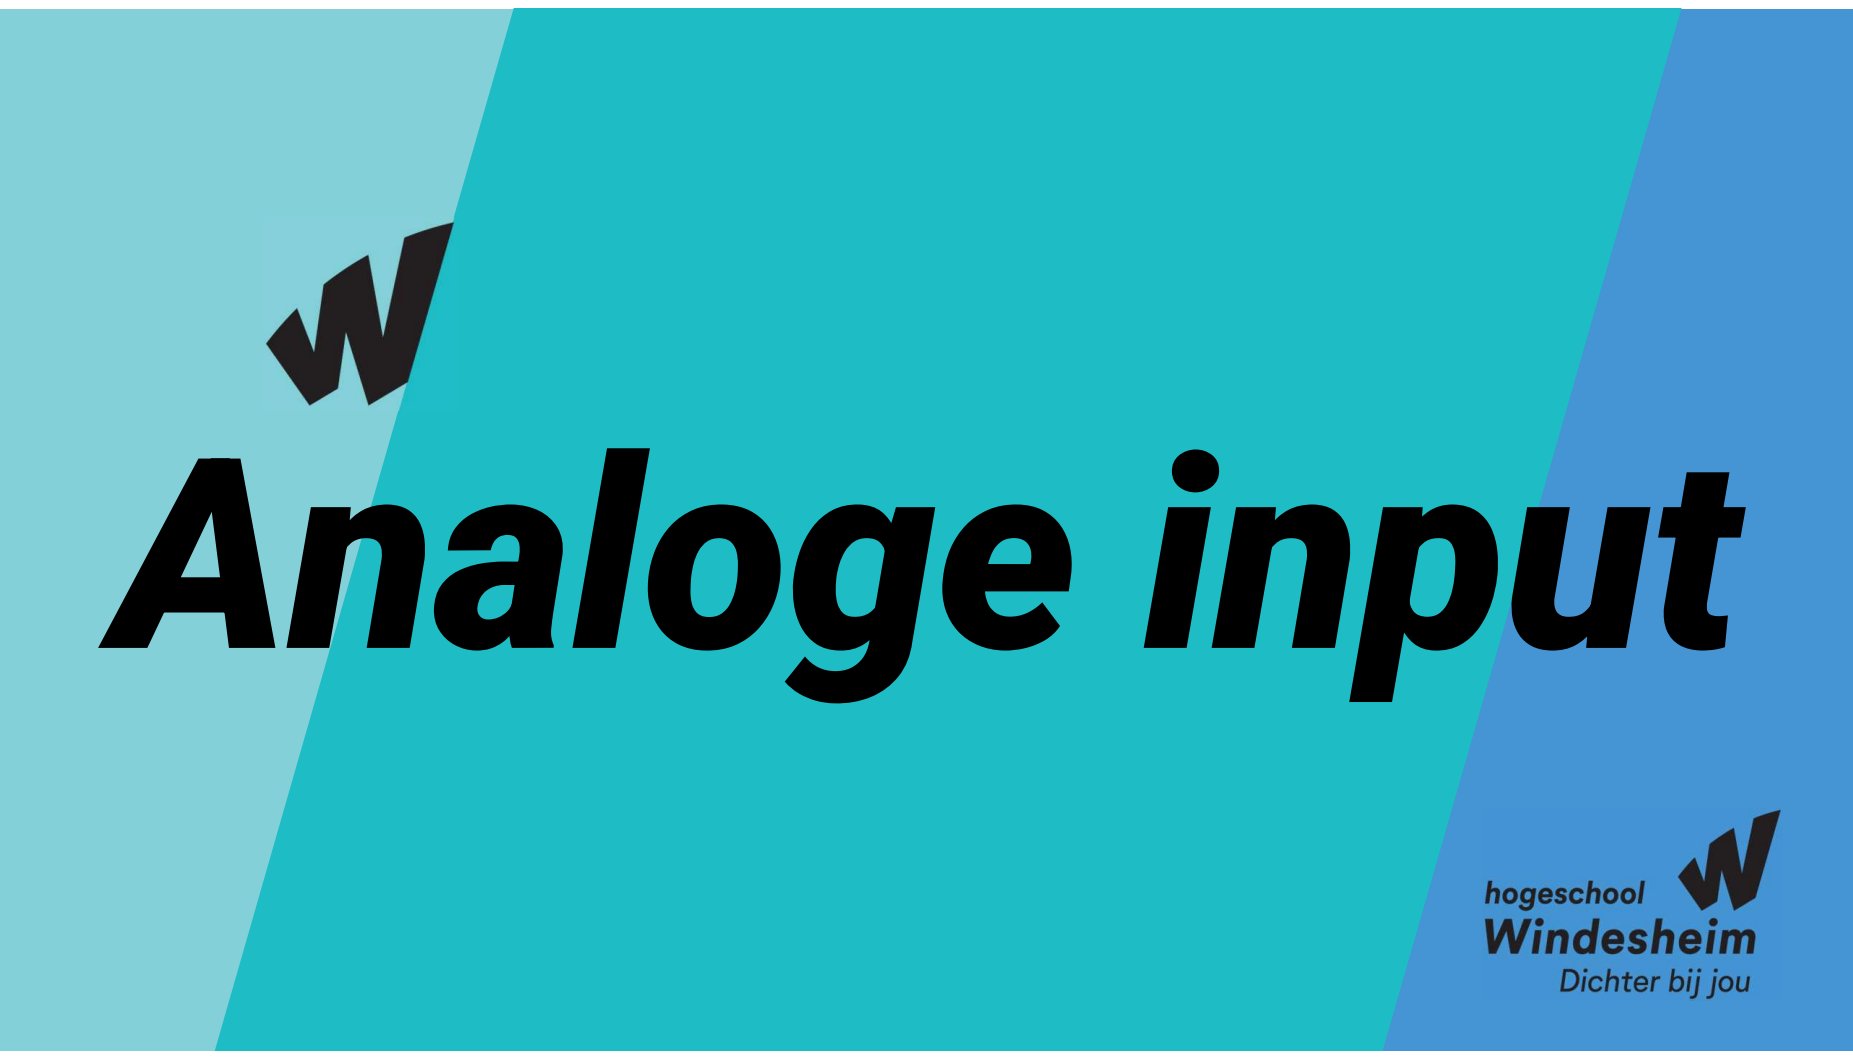
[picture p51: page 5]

# Eisen Analoge input

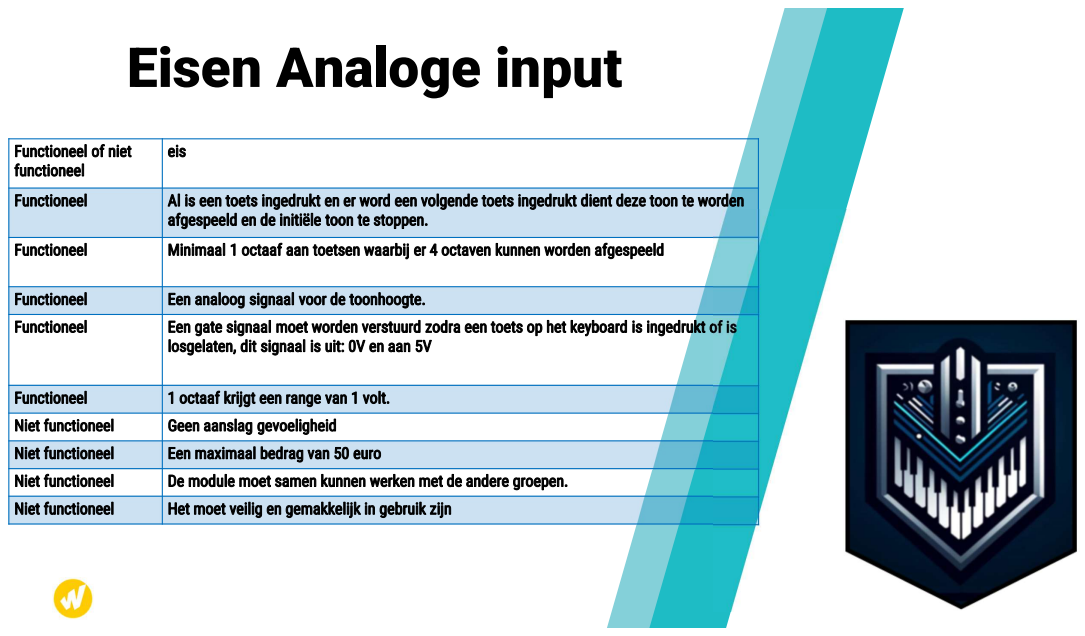
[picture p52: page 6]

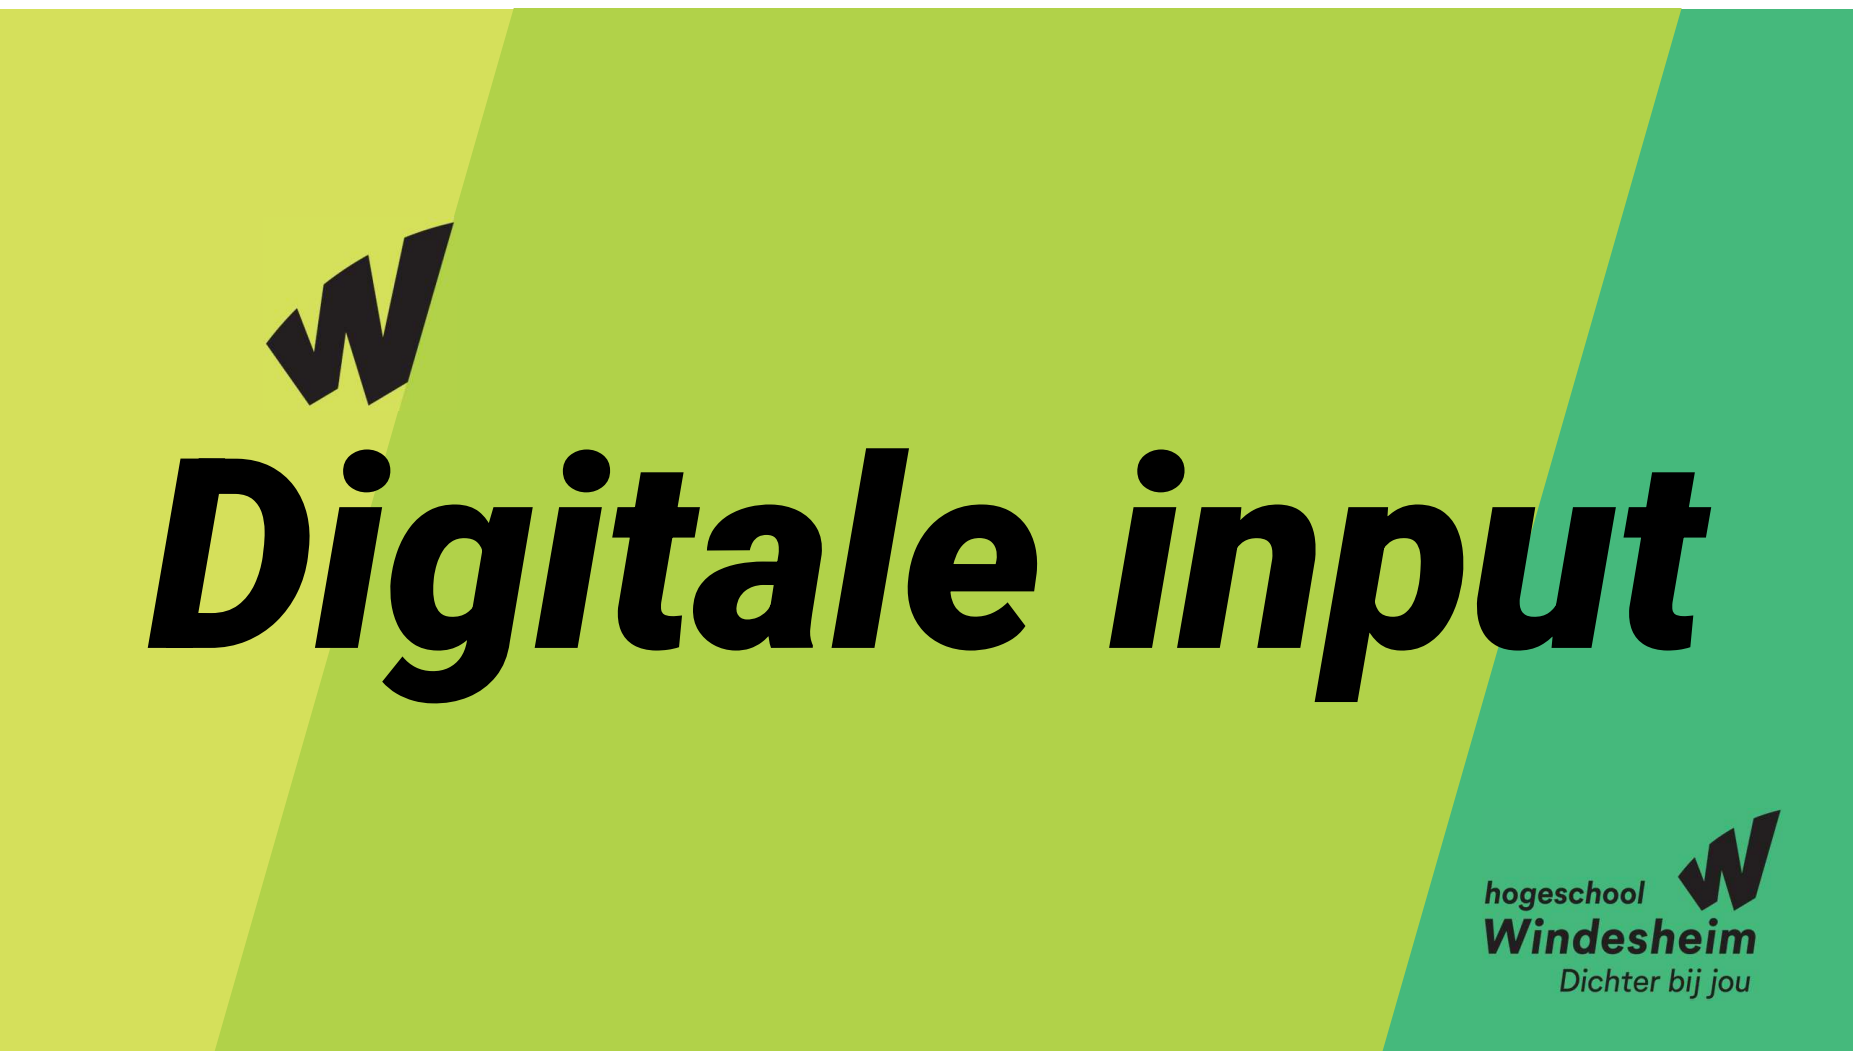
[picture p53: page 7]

# Eisen Digitale input

Functioneel of niet functioneel | eis

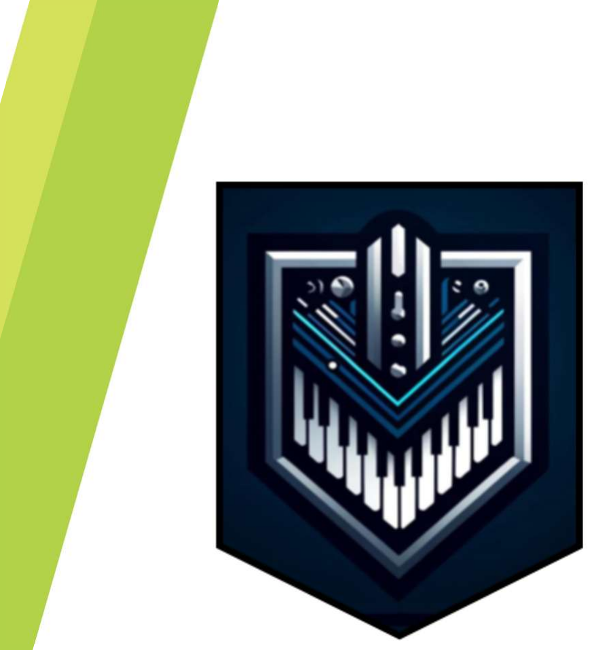
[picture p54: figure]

Functioneel | Al is een toets ingedrukt en er word een volgende toets ingedrukt dient deze toon te worden afgespeeld en de initiële toon te stoppen.
Functioneel | De decoder zet het digitale midi signaal om naar een analoog signaal voor de toonhoogte.
Functioneel | Een gate signaal moet worden verstuurd zodra een toets op het keyboard is ingedrukt of is losgelaten, dit signaal is uit: 0V en aan: tussen de 5 en 10V
Functioneel | Na de midi connector moet het digitale signaal worden verstuurt naar een decoder deze zet het midi signaal om naar een analoge signaal die overeen komt met het analoge input signaal
Functioneel | De midi input moet voor het grootste gedeelte voldoen aan het NEN-EN-INC 63035 protocol, daaronder valt dus geen aanslag gevoeligheid en opslaan van het signaal.
Niet functioneel | Geen aanslag gevoeligheid
Niet functioneel | Een maximaal bedrag van 50 euro
Niet functioneel | De module moet samen kunnen werken met de andere groepen.
Niet functioneel | Het moet veilig en gemakkelijk in gebruik zijn

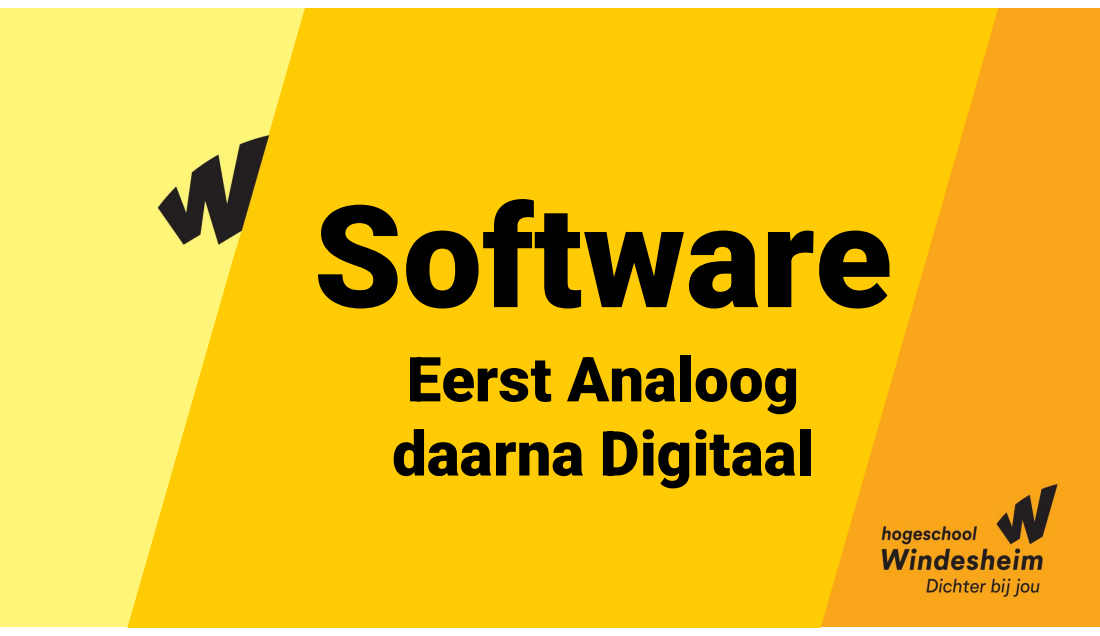
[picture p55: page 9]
Eerst Analoog daarna Digitaal

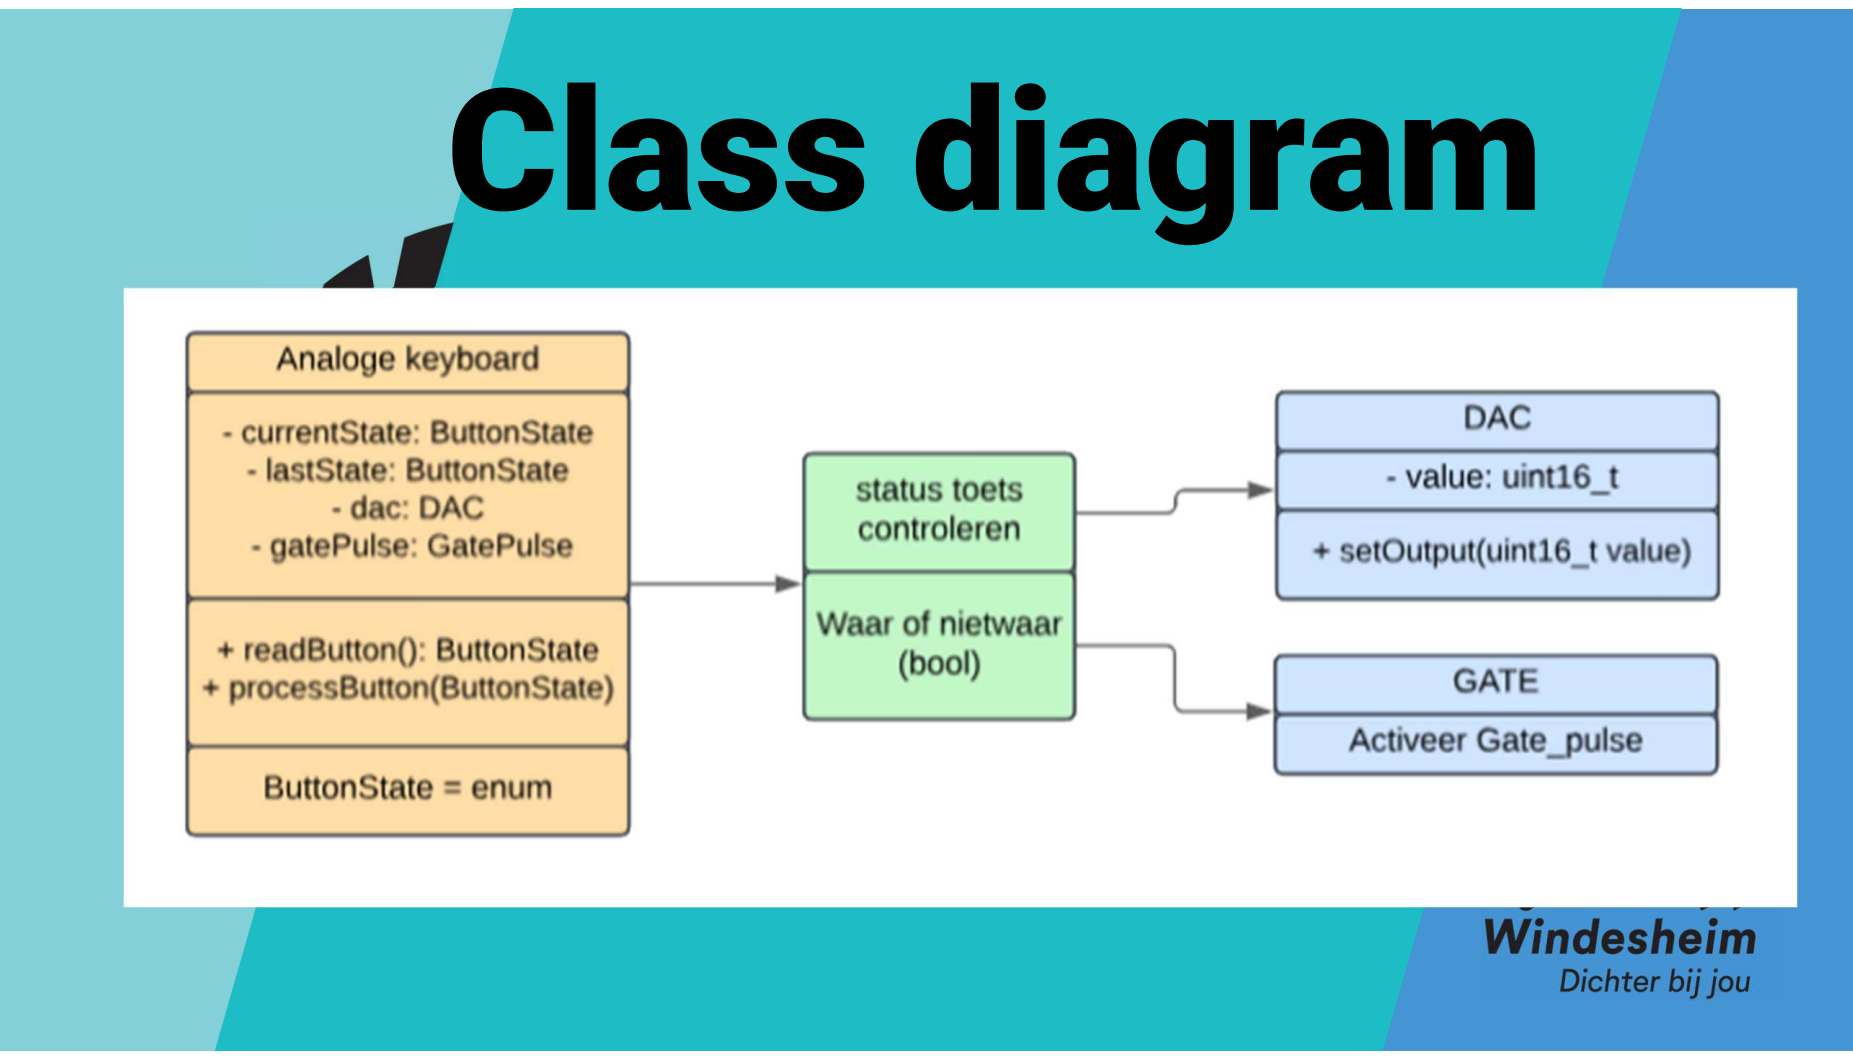
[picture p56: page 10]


# Gebruikte libraries

# Analoge input Code

# Instellen van de DAC

# Functie voor het Gate signaal


# States aanmaken


# Gebruik van IF- statements

# Analoge input Code

# Gebruik van switch-case

# (PART 2)



# Gebruikte libraries

# Digitale input Code

# Functie voor het midi

# Hier wordt de uart0 receivepin uitgelezen

# Hier wordt het midi signaal omgezet


# Main functie waar wordt geschakelt tussen midi en analoge input



# at zijn de vragen?

Hopelijk niet te moeilijk

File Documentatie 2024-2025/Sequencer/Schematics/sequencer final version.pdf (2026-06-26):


PD7 13 PF0(XTAL32K1) | 16 | 0.10 μF 1uF
AVDD 14 | | R9


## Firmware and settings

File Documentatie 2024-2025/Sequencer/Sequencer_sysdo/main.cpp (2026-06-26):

#define F_CPU           4000000UL   /* Main clock frequency */
#define START_TOKEN     0x03        /* Start Frame Token */
#define END_TOKEN       0xFC        /* End Frame Token */
/* Compute the baud rate */
#define USART1_BAUD_RATE(BAUD_RATE) (((float)F_CPU * 64 / (16 * (float)BAUD_RATE)) + 0.5)
#include <avr/io.h>
#include <util/delay.h>
#include <math.h>

/* VREF start-up time */
#define VREF_STARTUP_TIME        (50)
/* Mask needed to get the 2 LSb for DAC Data Register */
#define LSB_MASK                 (0x03)

static void VREF_init(void);
static void DAC0_init(void);
static void DAC0_setVal(uint16_t value);


#include <avr/io.h>
#include <stdbool.h>
#include <avr/cpufunc.h>
#include <avr/interrupt.h>
#include <avr/delay.h>

#define TIMER_PERIOD        0x2000

void CLKCTRL_init(void);
void PORT_init(void);
void VREF0_init(void);
void ADC0_init(void);
uint16_t ADC0_read(void);
void ADC0_start(void);
uint16_t per;

int maten = 1;
uint16_t toonhoogte[32];
int count = 0;
bool recording = true;
int state = 0;
bool aan = false;
bool buttonPressed = false;
float bpm = 60;
int listtotal = 32;
int timer = 0;
int ledCount = 0;
uint16_t  bem;
bool updatebpm = false;
bool interrrupt = false;
int gatedelay = 0;
bool firstplay = false;
uint16_t checkgate;

uint16_t currentToon;
/* This function initializes the CLKCTRL module */
void CLKCTRL_init(void)
{
	/* Unlock and set the clock frequency to 4 MHz */
	CCP = CCP_IOREG_gc;  // Unlock protected registers
	CLKCTRL.OSCHFCTRLA = CLKCTRL_FRQSEL_4M_gc;
}


/* This function initializes the PORT module */
void PORT_init(void)
{
	/* Configure PC0 as output for USART1 TX */
	PORTC.DIRSET = PIN0_bm;
	/* Disable interrupt and digital input buffer on PD3 */
	PORTD.PIN3CTRL &= ~PORT_ISC_gm;
	PORTD.PIN3CTRL |= PORT_ISC_INPUT_DISABLE_gc;

	/* Disable pull-up resistor */
	PORTD.PIN3CTRL &= ~PORT_PULLUPEN_bm;
	/* Configure PC0 as output for USART1 TX */
	PORTC.DIRSET = PIN0_bm;
	/* Disable interrupt and digital input buffer on PD3 */
	PORTD.PIN1CTRL &= ~PORT_ISC_gm;
	PORTD.PIN1CTRL |= PORT_ISC_INPUT_DISABLE_gc;

	/* Disable pull-up resistor */
	PORTD.PIN1CTRL &= ~PORT_PULLUPEN_bm;
}

/* This function initializes the VREF module */
void VREF0_init(void)
{
	VREF.DAC0REF = VREF_REFSEL_2V048_gc | VREF_ALWAYSON_bm; // Set VREF to 2.048V
	_delay_us(VREF_STARTUP_TIME);

	VREF.ADC0REF = VREF_REFSEL_2V048_gc;  /* Internal 2.048V reference */
}
static void DAC0_init(void)
{
	/* Disable digital input buffer on PA6 */
	PORTD.PIN6CTRL &= ~PORT_ISC_gm;
	PORTD.PIN6CTRL |= PORT_ISC_INPUT_DISABLE_gc;
	PORTD.PIN6CTRL &= ~PORT_PULLUPEN_bm;

	DAC0.CTRLA = DAC_ENABLE_bm | DAC_OUTEN_bm | DAC_RUNSTDBY_bm; // Enable DAC
}
static void DAC0_setVal(uint16_t value)
{
	DAC0.DATAL = (value & LSB_MASK) << 6;      // Store LSbs
	DAC0.DATAH = value >> 2;                   // Store MSbs
}


/* This function initializes the ADC module */
void ADC0_init(void)
{
	//ADC0.CTRLC = ADC_PRESC_DIV128_gc;        /* CLK_PER divided by 4 */
	ADC0.CTRLA = ADC_ENABLE_bm             /* ADC Enable: enabled */
	| ADC_RESSEL_10BIT_gc       /* 12-bit mode */
	| ADC_FREERUN_bm;           /* Enable Free-Run mode */
	ADC0.MUXPOS = ADC_MUXPOS_AIN1_gc;
	ADC0.MUXPOS = ADC_MUXPOS_AIN4_gc;     /* Select ADC channel AIN3 <-> PD3 */
}


/* This function returns the ADC conversion result */
uint16_t ADC0_read(int channel)
{
	if(channel == 2){
		ADC0.MUXPOS = ADC_MUXPOS_AIN5_gc;
	}
	else{
		ADC0.MUXPOS = ADC_MUXPOS_AIN1_gc;
	}
	if(channel == 0){
		ADC0.MUXPOS = ADC_MUXPOS_AIN1_gc;
	}
	for(int i; i > 50; i++){}
	/* Wait for ADC result to be ready */
	while (!(ADC0.INTFLAGS & ADC_RESRDY_bm));
	/* Clear the interrupt flag by reading the result */
	return ADC0.RES;
}

/* This function starts the ADC conversions*/
void ADC0_start(void)
{
	/* Start ADC conversion */
	ADC0.COMMAND = ADC_STCONV_bm;
}

void newBPM(float bpm){
	
	TCA0.SINGLE.INTCTRL = TCA_SINGLE_OVF_bm;
	per = (uint16_t) (TIMER_PERIOD / bpm);
	TCA0.SINGLE.PER = per;
	TCA0.SINGLE.CTRLA = (TCA_SINGLE_CLKSEL1_bm | TCA_SINGLE_CLKSEL2_bm);
	TCA0.SINGLE.CTRLA |= TCA_SINGLE_ENABLE_bm;
	
	sei();
	return;
}

void checklist(){
	
	listtotal = 32;
	

}

void gateInterrupt(){
	uint16_t adc = ADC0_read(1);
	//DAC0_setVal(adc);
	
	PORTA.OUTCLR = PIN3_bm;
	PORTA.OUTCLR = PIN4_bm;
	PORTA.OUTCLR = PIN5_bm;
	PORTA.OUTCLR = PIN6_bm;
	if(state != 0){
		if(timer % 4 == 0){
			
			
			if(ledCount == 0){
				PORTA.OUTSET = PIN3_bm;
				}else if(ledCount == 1){
				PORTA.OUTSET = PIN4_bm;
			}
			else if(ledCount == 2){
				PORTA.OUTSET = PIN5_bm;
			}
			else if(ledCount == 3){
				PORTA.OUTSET = PIN6_bm;
			}
			ledCount++;
			if (ledCount >= 4){
				ledCount = 0;
			}
		}
		timer++;
	}
	
	
	
	
	switch (state)
	{
		case 1:
		//record
		
		toonhoogte[count] = adc;
		DAC0_setVal(0);
		break;
		case 2:
		DAC0_setVal(toonhoogte[count]);
		
		//replace
		
		
		
		if (adc > 5){
			toonhoogte[count] = adc;
		}
		break;
		case 3:
		if(1){
			
			DAC0_setVal(toonhoogte[count]);
		}
		
		
	}
	count++;
	//DAC0_setVal(adc);
	currentToon = toonhoogte[count];
}

void tick(){
	
	checklist();
	if (count >= listtotal) {
		count = 0;
	}
	if(updatebpm){
		gateInterrupt();
		
		//foei niet in de ISR ^^
		//DAC0_setVal(ADC0_read(2));
	}
	else
	{
		bem = ADC0_read(2);
		
		newBPM(bem / 100 + 10);

		
	}
	
	updatebpm = !updatebpm;
}


ISR(TCA0_OVF_vect) {
	
	interrrupt = true;
	tick();
	TCA0.SINGLE.INTFLAGS = TCA_SINGLE_OVF_bm;

	//DAC0_setVal(ADC0_read(1));
}


void output(uint8_t toon, bool gate){
	//DAC0_setVal(toon);
	PORTA.OUTCLR = PIN1_bm;
}

void deletes(){
	for(int i = 0; i < listtotal; i++){
		toonhoogte[i] = 0;
	}
	
}



int main(void)
{

	checkgate = toonhoogte[count];
	uint16_t adcVal;
	/* Initialize all peripherals */
	CLKCTRL_init();
	PORT_init();
	VREF0_init();
	ADC0_init();
	DAC0_init();
	/* Start the ADC conversions */
	ADC0_start();
	newBPM(10);
	//gate out                                               PORT A1
	PORTD.DIR = PORTD.DIR | PIN7_bm;
	// Initialize time variablE
	
	PORTA.DIRCLR = PIN7_bm;
	PORTC.DIRCLR = PIN0_bm;
	PORTC.DIRCLR = PIN1_bm;

	PORTA.DIR = PORTA.DIR | PIN3_bm;
	
	PORTA.DIR = PORTA.DIR | PIN4_bm;
	
	PORTA.DIR = PORTA.DIR | PIN5_bm;
	
	PORTA.DIR = PORTA.DIR | PIN6_bm;
	

	PORTC.DIR = PORTC.DIR | PIN2_bm;
	

	
	
	

	while (1)
	{
		state = 0;
		if ((PORTC.IN & (PIN1_bm)))
		{
			PORTA.OUTSET = PIN6_bm;
			/* LED0 on */
			state = 2;
			
		}
		else if((PORTC.IN & (PIN0_bm))){
			state = 1;
		}
		else if(PORTA.IN & (PIN7_bm)){
			state = 3;
			if(!firstplay){
				count = 0;
				firstplay = true;
			}
		}
		/* 1: Released */
		if(PORTC.IN & (PIN2_bm)){
			deletes();
		}
		//DAC0_setVal(bpm);
		
		
		if(state == 0){
			DAC0_setVal(0);
		}

		if((currentToon == checkgate) && (state >= 2)){
			PORTD.OUTSET = PIN7_bm;
			gatedelay = 1;
		}
		else if(toonhoogte[count] <= 10 && (state >= 2)){
			PORTD.OUTCLR = PIN7_bm;
		} else
		{
			PORTD.OUTCLR = PIN7_bm;
			//PORTC.OUTSET = PIN6_bm;
		}
		if(state <= 1)
		{
			PORTD.OUTCLR = PIN7_bm;
		}
		
		if(gatedelay > 50){
			//PORTC.OUTCLR = PIN6_bm;
			checkgate = currentToon;
			gatedelay = 0;
			
			}else{
			gatedelay++;
		}
		
		if(interrrupt){
			
			//PORTB.OUTTGL = PIN3_bm;
			
		}
		
	}
}

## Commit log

2026-04-23 Add README for filter module by Jens and Diémo
2026-04-23 Create README for Power amplifier and Power supply
    Added README file for Power amplifier and Power supply module.
2026-05-11 Add files via upload
    aantekeningen werking input schematic
2026-05-11 Add documentation for polyphonic system upgrade
    Document the current system and requirements for upgrading to a polyphonic synthesizer. Discuss the limitations of the current setup and propose solutions for achieving polyphony or paraphony.
2026-05-20 Create README for Eindproduct and power supply group
    Added README file for the final product and power supply group.
2026-05-20 Create README for PCB files of amplifier and power supply
    Added README file with description of PCB files for amplifier and power supply.
2026-05-20 Add README with project approach for amplifier and power supply
2026-05-20 Add README for mixer, VCA, and ADSR schematics
    Added README file with information about schematics and PCB designs.
2026-07-02 Add README for ADSR approach and NE555p timer IC
    Added documentation on ADSR approach and potential solutions for NE555p timer IC issues.
